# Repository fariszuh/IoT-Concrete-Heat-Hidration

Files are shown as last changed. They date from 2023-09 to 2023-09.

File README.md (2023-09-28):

# Heat Hydration

## Latar Belakang

Perilaku struktur beton pada gedung sangat dipengaruhi oleh mutunya. Salah satu faktor internal beton yang dapat menurunkan kualitas mutu beton adalah panas hidrasi (Lu et al., 2020). Panas akibat proses hidrasi sulit dilepaskan oleh
beton karena sifat konduktivitas beton yang rendah sehingga terjadi perbedaan suhu antara beton dan lingkungan yang besar seiring peningkatan suhu hidrasi
(Gowripalan, 2020). Perbedaan suhu ini mengakibatkan peristiwa konveksi yang menimbulkan tegangan tarik pada sisi luar dan tegangan tekan di bagian tengah  beton. Tegangan ini disebut dengan tegangan thermal. Tegangan thermal yang tidak mampu diterima pada umur awal beton menyebabkan retak yang terjadi bersamaan dengan susut. Retakan dan susut mengubah sifat mekanik beton sehingga terjadi penurunan mutu beton (Gowripalan, 2020).
Mutu beton yang berubah penting untuk diketahui dengan cara evaluasi yang ditinjau dengan Indeks kematangan beton. Evaluasi ini didasari oleh hasil monitoring kenaikan suhu dan perubahan susut beton sebagai efek dari panas hidrasi sejak umur awal.
Monitoring kenaikan suhu dan perubahan susut merupakan hal yang penting diperhatikan dalam mengevaluasi mutu beton. Namun, sistem akuisisi yang digunakan untuk monitoring masih menggunakan transfer data dari data logger menuju komputer atau bahkan dicatat secara manual. Akuisisi data dengan sistem ini berisiko mudah mengalami kehilangan data record karena pada kondisi monitoring realtime terdapat banyak gangguan dan kurang praktis karena data tidak dapat dipantau secara jarak jauh serta memerlukan komputer yang harus menyala ketika monitoring, yang mana monitoring dilakukan selama 24 jam.
Inovasi yang diberikan untuk permasalahan tersebut adalah perancangan sistem monitoring dengan automasi transfer data ke cloud database sebagai wadah penyimpanan dan pengolahan data. Transfer data dari penyimpanan internal dapat dilakukan secara otomatis atau dikendalikan oleh pengguna saat terdapat jaringan internet. Data input yang telah ditransfer, diolah dalam pemrograman untuk mendapatkan maturity index berupa grafik yang akan dibandingkan antara data lab dan lapangan sebagai tinjauan evaluasi kematangan beton akibat efek panas hidrasi. Selain itu, perubahan susut dapat diklasifikasikan berdasarkan waktu yang berjalan dan kondisi kenaikan suhu. Adapun, Modifikasi pada instrumen susut yang menggunakan prinsip sinyal impuls pada kaliper digital yang bekerja bersamaan dengan pengukuran suhu oleh sensor thermocouple. Implementasi ide ini diharapkan dapat menjawab masalah tersebut  yang mana proses perwujudan ide akan dijelaskan dalam laporan ini.

## Rumusan Masalah

Masalah yang dapat dirumuskan dari latar belakang di atas adalah sebagai
berikut.

1. Merancang purwarupa dan algoritma sistem untuk mengukur parameter evaluasi mutu beton (suhu dan susut) pada umur awal akibat efek panas
hidrasi berbasis wireless?
2. Bagaimana cara kerja sistem akuisisi data sehingga dapat menjadi indikator evaluasi mutu beton pada umur awal akibat efek panas hidrasi?
3. Bagaimana menciptakan visualisasi dari sistem akuisisi data parameter evaluasi mutu beton pada umur awal akibat efek panas hidrasi berbasis wireless?

## Tujuan

Tujuan yang akan dicapai dari Program Kreativitas Mahasiswa ini adalah
sebagai berikut.
1. Merancang purwarupa dan algoritma sistem untuk mengukur parameter
evaluasi mutu beton (suhu dan susut) pada umur awal akibat efek panas
hidrasi berbasis wireless.
2. Mengetahui cara kerja sistem akuisisi data sehingga dapat menjadi
indikator evaluasi mutu beton pada umut awal akibat efek panas hidrasi.
3. Menciptakan visualisasi sistem akuisisi data parameter evaluasi mutu
beton pada umur awal akibat panas hidrasi berbasis wireless.

## Manfaat Program
Manfaat dari program Kreativitas Mahasiswa ini adalah sebagai berikut.

1. Bagi Pelaksana
Tercapainya peran dan fungsi mahasiswa untuk be eran pada masyarakat  dan bidang keilmuannya.

2. Bagi Akademisi
Menunjang riset terkait inovasi beton yang mengkaji panas hidrasi sebagai properties beton.

3. Bagi Industri Konstruksi
a. Mempermudah monitoring dan evaluasi mutu beton dengan sistem yang lebih akurat dan praktis.
b. Adanya riwayat pengujian pada penyimpanan awan akan membantu dalam pencarian problem pada sistem struktural pekerjaan konstruksi.

## Hasil pengujian dan evaluasi
Hasil dan evaluasi yang diperoleh dari pengujian alat meliputi: 

### Hasil pengambilan data thermocouple tipe K tersaji dalam grafik berikut
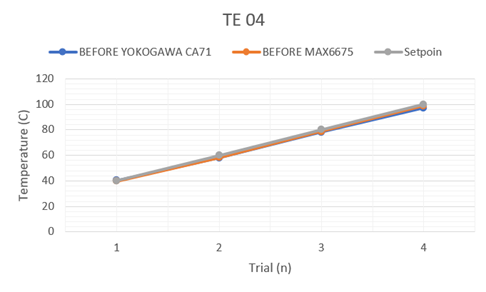
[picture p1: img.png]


Gambar 4. 6 Kalibrasi Pengukuran Suhu

Error thermocouple terukur rata-rata sebesar 0.8025°C (absolute). Hal ini menandakan bahwa standar pengukuran <5% dari range 60°C sudah te enuhi atau bernilai < 3°C. 

### Hasil pengujian Panjang susut tersaji pada grafik berikut. 

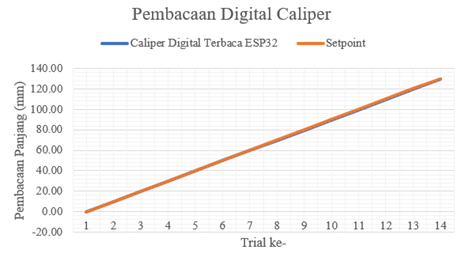
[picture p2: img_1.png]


Gambar 4. 7 Kalibrasi Pengukuran Susut

Error pengukuran digital caliper diperoleh sebesar 252.142857 µm. Nilai error ini masih jauh dari harapan, yakni sesuai standar 10 µm. ketidaksesuaian ini dimungkinkan terjadi karena kontak multiple elektrode stator (tembaga) dengan jalur slider (sin-cos plate) pada PCB terkadang bergeser vertical (normalnya hanya bergeser horizontal sepanjang tuas caliper) sehingga menyebabkan adanya gap antar plate dan timbul noise capacitance. Gap ini dimungkinkan terjadi karena pemasangan caliper dan kabel extender ke modul memakan jalur gerak tuas caliper sehingga jika dilihat dari sisi mekanikal akan sedikit menganga.

### Hasil percobaan monitoring dari sampel beton mutu 25 MPa yang dibuat memperoleh hasil sebagai berikut. 

Data hasil pengukuran suhu oleh termokopel disajikan pada gambar 4.8 dan data pengukuran susut oleh digital caliper disajikan oleh gambar 4.10. Untuk memperoleh prediksi kuat tekan beton digunakan nilai suhu yang dimasukkan kedalam persamaan Nurse-Saul dan diperoleh plot grafik perbandingan kuat tekan terhadap umur beton.

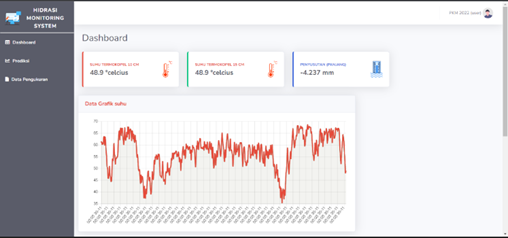
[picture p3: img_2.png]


Gambar 4. 8 Hasil Monitoring Suhu Beton

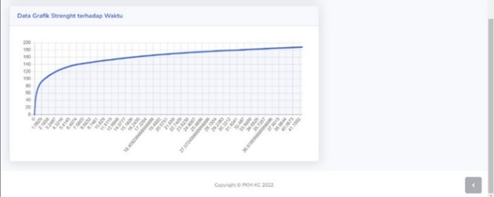
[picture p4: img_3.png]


Gambar 4. 9 Hasil Ploting Grafik Indeks Kematangan Beton

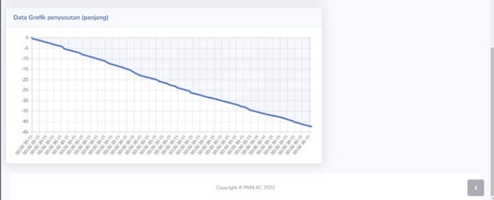
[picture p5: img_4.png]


Gambar 4. 10 Hasil Monitoring Susut Beton

## Kesimpulan
Sistem yang kami buat merupakan sistem akuisisi data berbasis wireless untuk evaluasi efek panas hidrasi beton pada umur awal. Data hasil pengukuran dan monitoring parameter panas hidrasi akan dikirim pada penyimpanan cloud. Sehingga dapat diakses secara realtime melalui website. Adapun alat yang kami buat berhasil diimplementasikan pada sampel beton mutu 25 MPa. Akan tetapi, dari hasil evaluasi diperoleh nilai eror rata-rata pembacaan suhu sebesar 0.8025˚C dan eror pembacaan susut sebesar 0,25mm dibandingkan dengan alat yang terkalibrasi.

## Saran
Saran kami dalam mewujudkan pengembangan alat ini menuju arah yang lebih baik adalah mempertimbangkan sensor dengan ketelitian yang lebih baik atau lebih mendalami cara meningkatkan kualitas pengukuran. Selain itu, perlu adanya kerja sama dengan pihak lain agar pengembangkan alat mampu diimplementasikan di lapangan dan potensi khusus dapat tercapai.

## Dokumentasi PKM (Youtube Ditmawa ITS 2022)
Dokumentasi ada pada direktori Luaran PKM (Video dan Audio). 

Link youtube:
https://www.youtube.com/watch?v=sR6Rn05YM_g&ab_channel=DirektoratKemahasiswaanITS

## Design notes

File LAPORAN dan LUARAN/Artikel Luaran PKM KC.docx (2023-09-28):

# SISTEM AKUISISI DATA BERBASIS WIRELESS UNTUK EVALUASI PANAS HIDRASI BETON PADA UMUR AWAL

Ahmad Dzikrullah Akbar, Muhammad Faris Zuhairi, Hakhi Gya Yektianto, Muhammad Alfiyan

Institut Teknologi Sepuluh Nopember

ABSTRAK

ABSTRACT

Pendahuluan

Metode

Hasil dan Pembahasan

Kesimpulan

Ucapan Terima Kasih

Daftar Pustaka

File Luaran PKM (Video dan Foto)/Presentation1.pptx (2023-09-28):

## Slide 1

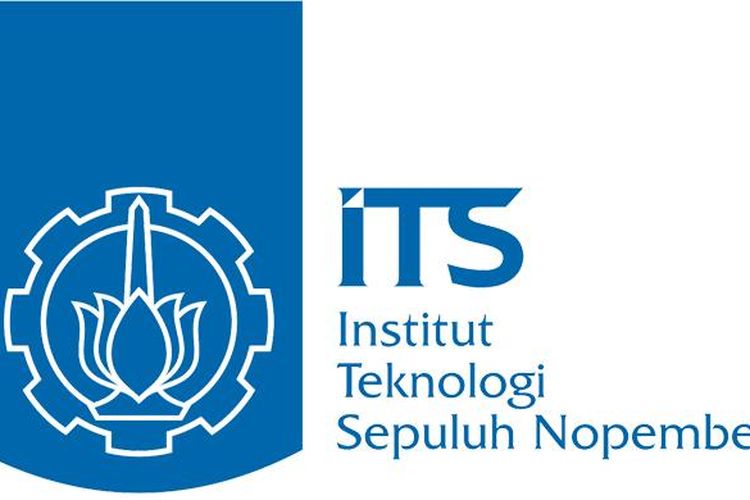
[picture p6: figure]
Lihat gambar sumber
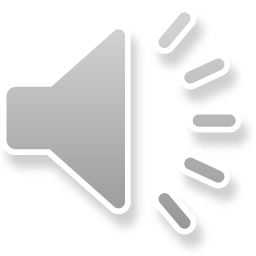
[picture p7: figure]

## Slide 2

Supported by:

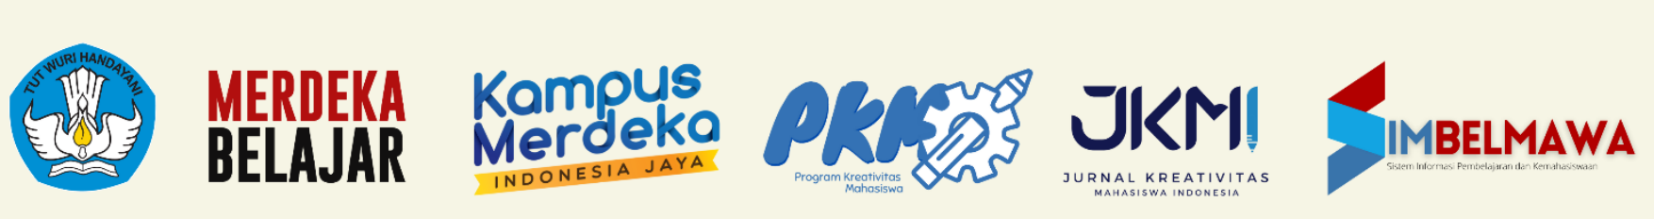
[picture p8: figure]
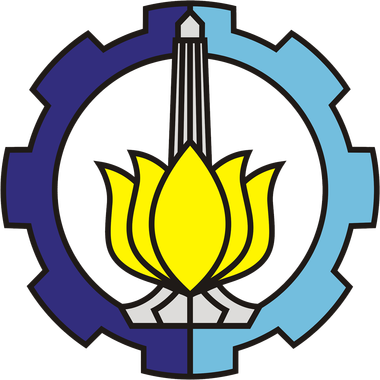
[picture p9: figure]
Institut Teknologi Sepuluh Nopember - Wikipedia bahasa Indonesia, ensiklopedia bebas

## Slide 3

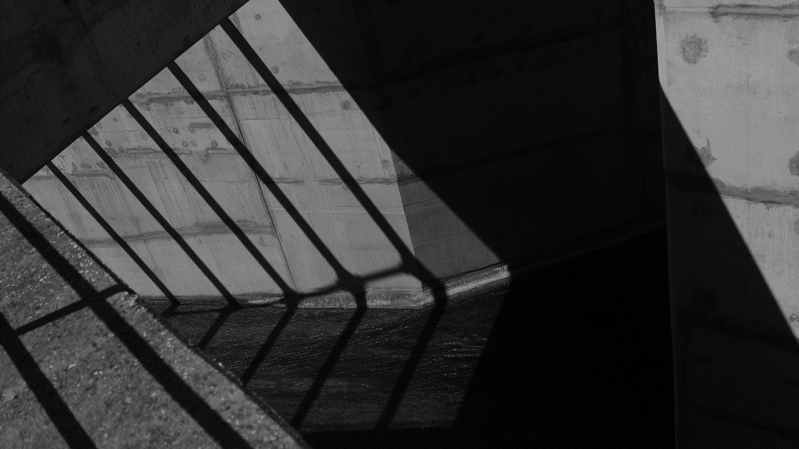
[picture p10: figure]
wing, light, black and white, architecture, structure, white, texture, roof, building, urban, wall, construction, pattern, line, space, shadow, black, monochrome, modern, material, concrete, design, stairs, symmetry, shape, monochrome photography

PROGRAM KREATIVITAS MAHASISWA KARYA CIPTA MEMPERSEMBAHKAN

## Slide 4

SISTEM AKUSISI DATA BERBASIS WIRELESS UNTUK EVALUASI EFEK PANAS HIDRASI BETON PADA UMUR AWAL

TIM 2461

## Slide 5

SISTEM AKUSISI DATA BERBASIS WIRELESS UNTUK EVALUASI EFEK PANAS HIDRASI BETON PADA UMUR AWAL

TIM 2461

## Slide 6

KEY PEOPLE

MUHAMMAD FARIS ZUHAIRI

07111940000021
Teknik Elektro

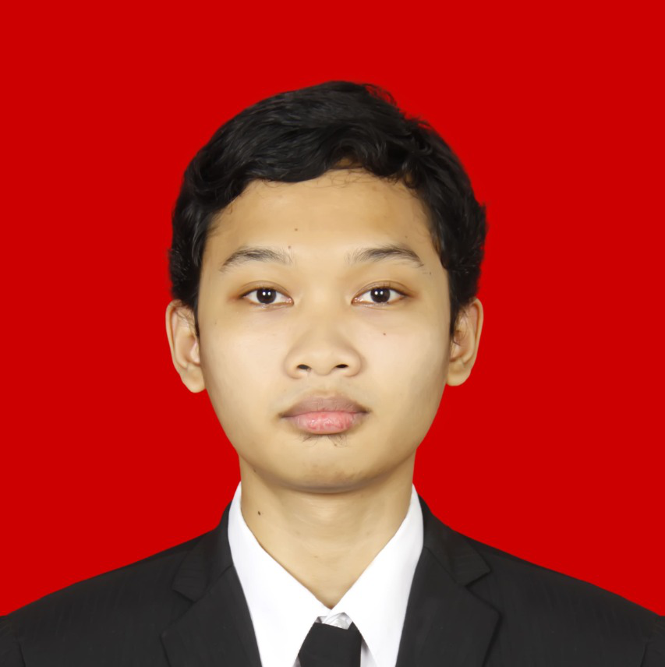
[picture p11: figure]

MUHAMMAD ALFIYAN ZULFA

5012201003
Teknik Sipil

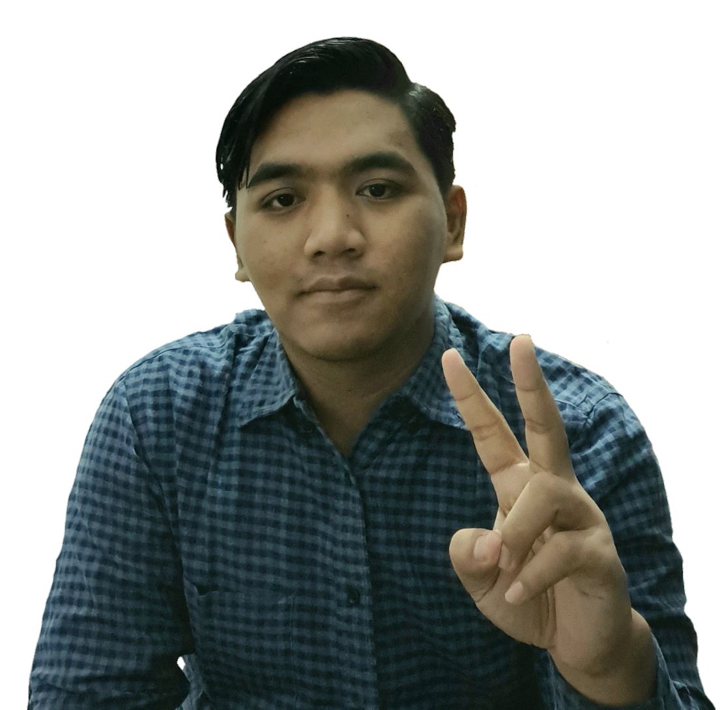
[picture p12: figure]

HAKHI GYA YEKTIANTO

07111940000022
Teknik Elektro

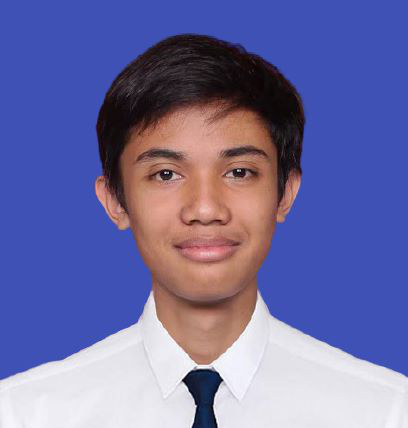
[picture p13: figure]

AHMAD DZIKRULLAH A.

03111940000005
Teknik Sipil

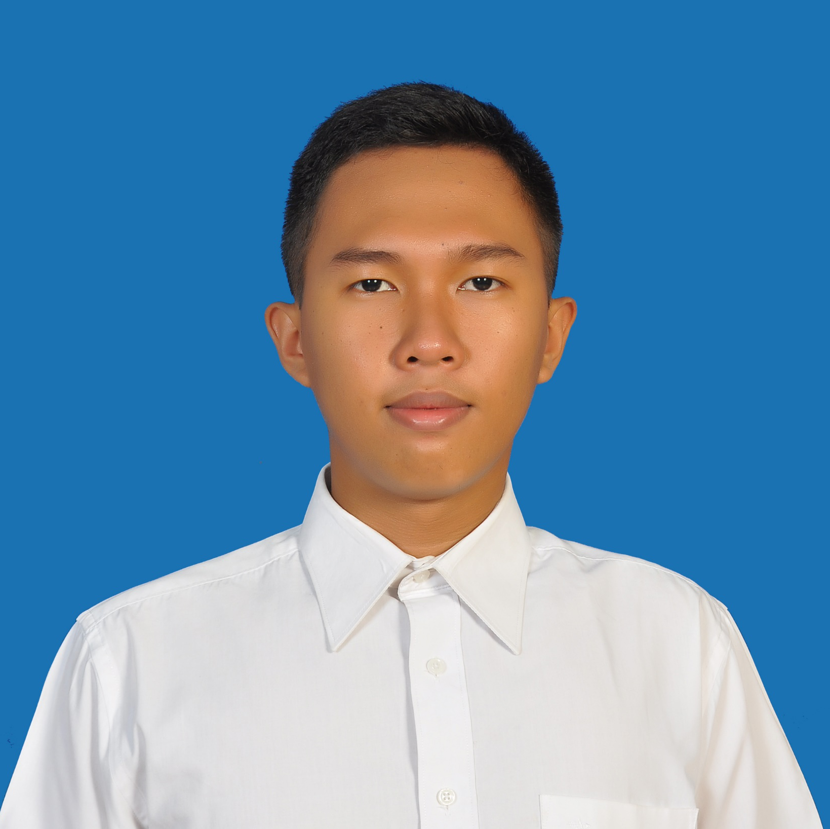
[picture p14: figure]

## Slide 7

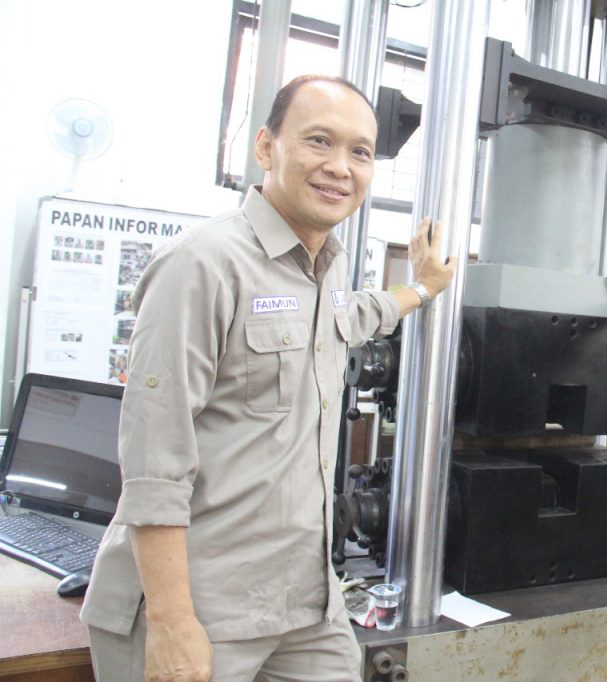
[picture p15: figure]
Lihat gambar sumber

Dosen Pembimbing

Ir. Faimun, M.sc., Ph.D.

## Grafik hasil perbandingan dengan kalibrator

| TE #1 15cm
SP | BEFORE YOKOGAWA CA71 | BEFORE MAX6675 | ERROR MUTLAK
40 | 40,5 | 42,61 | 2,11
60 | 60,2 | 62,71 | 2,51
80 | 80,4 | 82,19 | 1,79
100 | 99,7 | 101,47 | 1,77
| | AVG ERROR: | 2,045

TE #2 15cm
BEFORE YOKOGAWA CA71 | BEFORE MAX6675 | ERROR MUTLAK
41,6 | 41,38 | 0,22
59,8 | 61,49 | 1,69
80 | 82,59 | 2,59
99,4 | 101,05 | 1,65
| AVG ERROR: | 1,5375

## Grafik perbandingan dengan kalibrator

TE #3 10cm
BEFORE YOKOGAWA CA71 | BEFORE MAX6675 | ERROR MUTLAK
39,6 | 39,89 | 0,29
58,4 | 59,75 | 1,35
78,6 | 79,07 | 0,47
96,68 | 98,2 | 1,52
| AVG ERROR: | 0,9075

TE #4 10cm
BEFORE YOKOGAWA CA71 | BEFORE MAX6675 | ERROR MUTLAK
40,4 | 39,68 | 0,72
58,1 | 58,42 | 0,32
78,1 | 78,67 | 0,57
97,2 | 98,8 | 1,6
| AVG ERROR: | 0,8025

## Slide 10

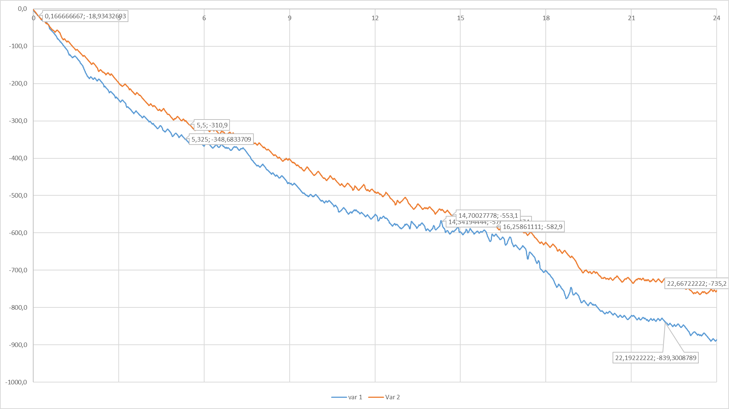
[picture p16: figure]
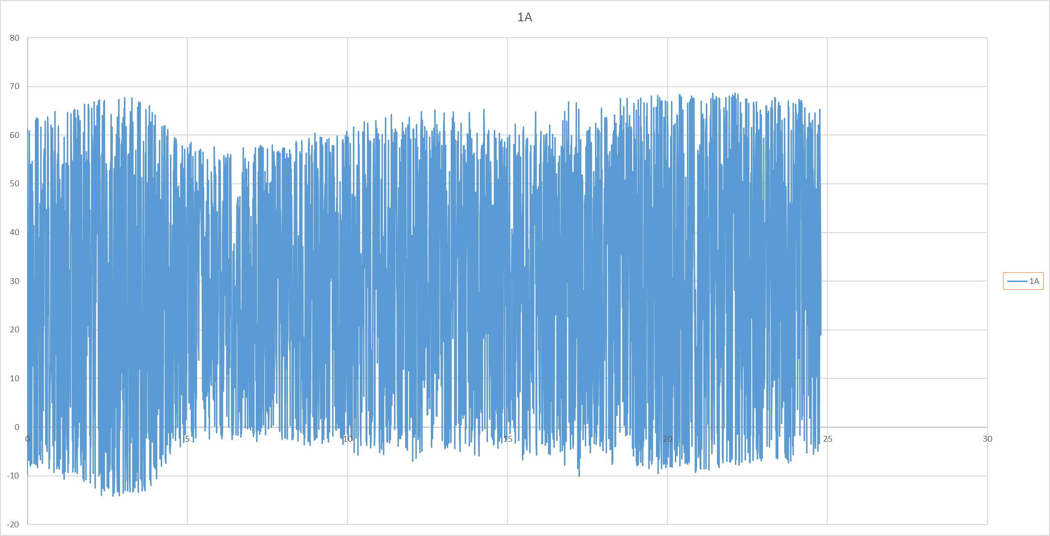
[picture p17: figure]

DATA PENUH NOISE

DATA OUTPUT SEHARUSNYA

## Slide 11

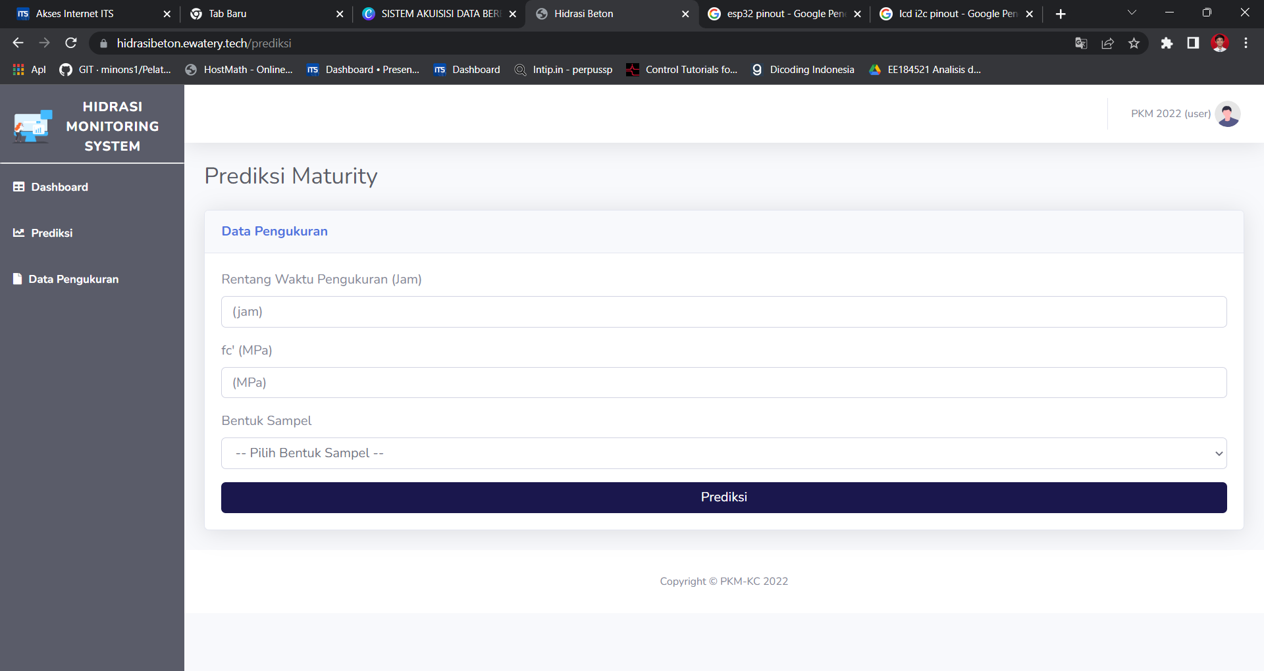
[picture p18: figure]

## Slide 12

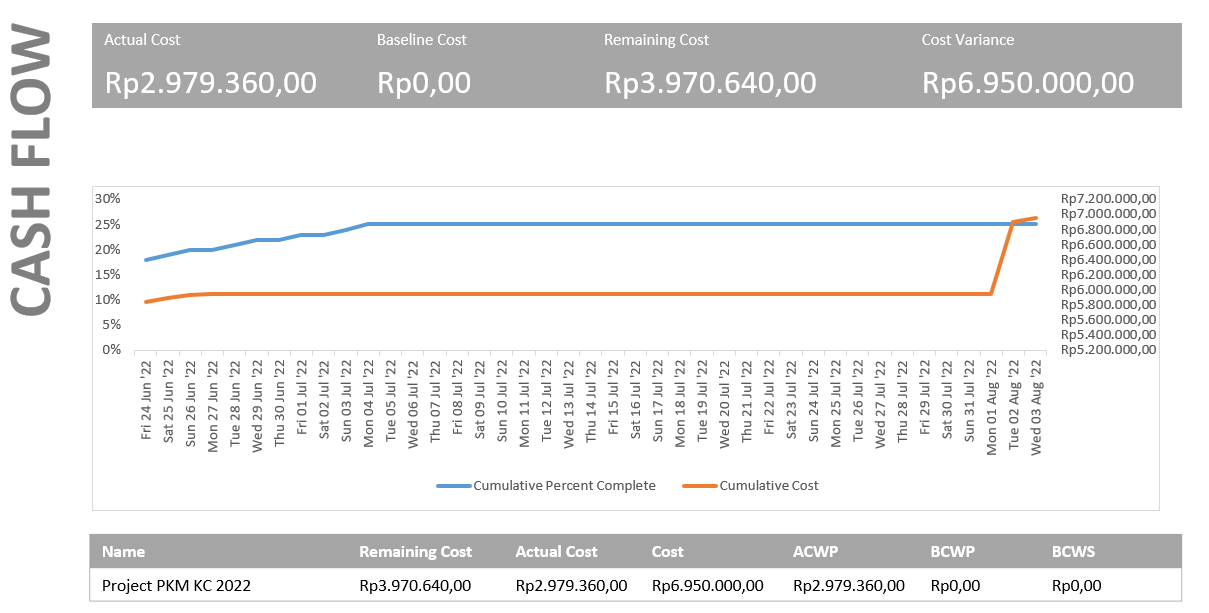
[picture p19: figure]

Berdasarkan rekapitulasi dana, dana yang masuk masih kurang 20% dari total dana yang diberikan oleh ristekdikti. Sedangkan per tanggal 3/9/2022, dana yang telah digunakan adalah sebesar Rp.2.979.360 dengan progress sekitar 80%.

## Simpulan

## Rencana Tahap Selanjutnya

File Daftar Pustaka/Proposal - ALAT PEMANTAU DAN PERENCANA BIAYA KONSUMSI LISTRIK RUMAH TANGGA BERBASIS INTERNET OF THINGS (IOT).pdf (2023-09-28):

i

i

DAFTAR ISI

ii

ii

DAFTAR TABEL
Tabel 1.1 Perbandingan Alat ini dengan KWh Meter Digital dan Power Meter.. 2
Tabel 4.1 Anggaran Biaya | 8
Tabel 4.2 Jadwal Kegiatan | 9

DAFTAR GAMBAR
Gambar 2.1 Sensor Tegangan ZMPT101B | 4
Gambar 2.2 Sensor Arus ACS712 | 4
Gambar 2.3 Modul Relay | 5
Gambar 2.4 STM 32 | 5
Gambar 3.1 Diagram Alir Pelaksanaan | 6
Gambar 3.2 Desain Aplikasi | 7
Gambar 5.1 Halaman Depan Aplikasi | 19
Gambar 5.2 Fitur Pengaturan | 19
Gambar 5.3 Fitur History Pemakaian | 20
Gambar 5.4 Fitur Peringatan | 20
Gambar 5.5 Fitur Informasi | 21
Gambar 5.6 Posisi Peletakan Sensor Tegangan, Sensor Arus dan Relay | 21
Gambar 5.7 Peletakan Hardware | 22
Gambar 5.8 Skema Kerja Alat | 22

BAB 1. PENDAHULUAN

### 1.1 Latar Belakang

Kenaikan pendapatan yang tidak sebanding dengan kebutuhan merupakan salah satu masalah ekonomi yang dirasakan oleh sebagian masyarakat Indonesia. Selain itu kenaikan biaya bahan bakar, pendidikan dan sembako juga menambah beban pengeluaran masyarakat. Adanya kebijakan yang akan diberlakukan pada tahun 2020 untuk mengurangi subsidi dan menaikkan tarif dasar listrik untuk golongan daya 900 VA yang penggunanya didominasi oleh masyarakat kelas menengah ke bawah menyebabkan pengeluaran masyarakat pada golongan tersebut terus bertambah. Di sisi lain, masyarakat golongan menengah ke bawah yang sebagian besar bekerja sebagai petani, pedangang dan juga buruh yang mempunyai pendapatan yang cenderung tetap harus terkena dampak masalah perekonomian nasional.
Salah satu belanja pokok masyarakat tiap bulan adalah biaya listrik yang dapat dihitung dengan cara besaran daya yang dipakai dikalikan tarif listrik lalu dikalikan waktu pemakaian. Jika semakin kecil daya dari peralatan-peralatan elektronik yang digunakan, semakin rendah tarif listrik yang dibayar.Pemakaian listrik semakin sulit untuk dikontrol dan dibatasi agar sesuai dengan anggaran keuangan rumah tangga yang tersedia seiring perkembangan teknologi. Akibat dari pemakaian yang tidak dibatasi, seringkali biaya listrik membengkak. Akibat kondisi ini, seharusnya masyarakat sadar akan pemakaian listrik agar tidak berlebih hanya karena mudahnya mengakses listrik. Dengan anggaran listrik rumah tangga yang terkontrol, sisa anggaran dapat dialokasikan untuk jenis pengeluaran yang lain dan juga tidak mengganggu anggaran belanja rumah tangga yang telah direncanakan.
Saat ini kebanyakan rumah tangga di Indonesia menggunakan kWh meter digital yang dipakai untuk listrik prabayar. Alat tersebut hanya menampilkan daya listrik tersisa yang akan digunakan. Selain itu ada alat yang bernama Power Meter, yaitu alat yang mampu memonitor dan mengetahui besar daya listrik yang digunakan di dalam rumah. Kedua alat tersebut dapat memantau pemakaian daya listrik, namun tidak mampu melakukan pengawasan terhadap penggunaannya dari sisi biaya. Dari alat berbasis aplikasi ada juga yang dapat mengontrol penggunaan listrik perangkat elektronik yang terhubung dengan jaringan nirkabel namun tidak berbasis biaya listrik. Sehingga, solusi tersebut belum mampu mengatasi permasalahan anggaran pengeluaran kebutuhan listrik rumah tangga masyarakat Indonesia.
Oleh karena itu, dibutuhkan solusi berupa alat pengatur penggunaan listrik berdasarkan anggaran belanja rumah tangga yang dapat memonitor dan membantu konsumen untuk membatasi penggunaan listrik dengan menggunakan sistem wireless melalui smartphone dan aplikasi berbasis IoT (Internet of Things). Alat yang terdiri dari software dan hardware terintegrasi ini dilengkapi dengan algoritma yang menghitung penggunaan daya listrik berbasis tarif Rupiah untuk kemudian disampaikan kepada pengguna dalam bentuk alarm atau notifikasi penggunaan sebagai pengingat apabila penggunaan listrik hampir mendekati batas. Pada alat ini juga terdapat relay system yang terhubung dengan perangkat elektronik agar dapat mematikan peralatan listrik yang tidak terlalu dibutuhkan apabila pengunaan listrik di suatu rumah melebihi tarif yang ditentukan oleh budget planner secara otomatis dan real time. Alat ini dapat melakukan setting untuk berapa besar daya yang mau dikeluarkan bergantung biaya penggunaan listrik yang ingin dimasukkan dalam aplikasi. Selain itu, pada alat ini dilengkapi memory yang dapat menyimpan data penggunaan listrik bulan sebelumnya yang bisa digunakan untuk evaluasi pemakaian listrik. Dengan adanya alat ini, tentunya mampu menjawab permasalahan masyarakat rumah tangga dala menghemat listrik sehingga anggaran rumah tangga dapat dialokasikan ke kebutuhan yang lain. Tabel 1.1 Perbandingan Elcomic dengan KWh Meter Digital dan Power Meter
| KWh Meter Digital | Power Meter | Alat kami
Mengukur Daya Listrik | ✓ | ✓ | ✓
Mengukur Daya Listrik per Peralatan | - | ✓ | ✓
Mengukur Biaya Listrik yang Telah Digunakan | - | - | ✓
Pengingat Penggunaan Biaya Listrik | - | - | ✓
Rencana Anggaran Penggunaan Biaya Listrik | - | - | ✓
Pemutus Arus Listrik | ✓ | - | ✓

### 1.2 Rumusan Masalah

Permasalahan | yang | akan | diselesaikan | dari | Program | Kreativitas
Mahasasiswa ini adalah sebagai berikut:
1. Bagaimana membuat rancangan pemrograman software alat ini?
2. Bagaimana membuat rancangan hardware alat ini?
3. Bagaimana mengintegrasikan software dan hardware ke dalam satu sistem?
4. Bagaimana penerapan alat ini pada masyarakat?

### 1.3 Tujuan

Tujuan yang akan dicapai dengan Program Kreativitas Mahasiswa ini adalah sebagai berikut:

1. Mendapatkan software yang dapat memantau dan merencanakan penggunaan listrik sesuai dengan rencana anggaran yang diinginkan konsumen.
2. Mendapatkan hardware yang dapat membatasi penggunaan peralatan listrik yang telah terhubung sesuai dengan rencana anggaran yang telah dialokasikan
3. Mendapatkan suatu sistem software dan hardware terintegrasi menjadi alat yang dapat memantau merencanakan konsumsi listrik berbasis anggaran belanja rumah tangga.
4. Mengetahui hasil penerapan alat ini pada masyarakat rumah tangga.

### 1.4 Luaran yang Diharapkan

Luaran yang diharapkan dari Program Kreativitas Mahasiswa ini adalah sebagai berikut:
1. Terciptanya prototype alat dengan software dan hardware terintegrasi sebagai pemantau dan perencana penggunaan listrik berbasis anggaran belanja rumah tangga.
2. Artikel ilmiah tentang penerapan alat ini.
3. Catatan harian, laporan kemajuan, dan laporan akhir dari kegiatan PKM ini.

### 1.5 Manfaat

Manfaat dari Program Kreativitas Mandiri ini sebagai berikut:
1. Bagi Rumah Tangga
Program ini dapat membantu masyarakat rumah tangga dalam merencanakan dan mengontrol penggunaan listrik sesuai dengan anggaran belanja sehingga dapat menghemat pengeluaran.
2. Bagi Mahasiswa
Program ini dapat mengembangkan kreativitas mahasiswa dalam bidang teknologi yang lebih efektif dan efisien sesuai dengan permasalahan yang ada dalam masyarakat.
BAB 2. TINJAUAN PUSTAKA

### 2.1 Internet of Things (IoT)

Internet of Things, atau dikenal juga dengan singkatan IoT, merupakan sebuah konsep yang bertujuan untuk memperluas manfaat dari konektivitas internet yang tersambung secara terus-menerus dengan mentrabsfer data melalui jaringan tanpa memerlukan interaksi menusia ke manusia atau manusia ke computer. Semua sudah dijalankan secara otomatis dengan program. Pada dasarnya, Internet of Things mengacu pada benda yang dapat diidentifikasikan secara unik sebagai representasi virtual dalam struktur berbasis Internet dengan tujuan untuk mempermudah berbagai macam aktivitas yang dilakukan oleh manusia. IoT telah berkembang dari konvergensi teknologi nirkabel, micro-electromechanical systems (MEMS), dan Internet. (IdCloudHost, 2016). Pada rancangan alat kami, alat menggunakan IoT dimana akan mengirimkan data hasil daya dari peralatan kepada otak utama, STM 32 lalu akan dikirim melalui jaringan ke aplikasi penghitung daya pada smartphone pengguna.

### 2.2 Sensor Tegangan ZMPT101B

AC Voltage Sensor ZMPT101B adalah sensor berukuran kecil, memiliki akurasi tinggi, dan konsistensi yang baik untuk mengukur tegangan dan daya hingga kisaran 250VAC(Abubakar et al., 2017). Aplikasi lain dari alat ini diantaranya untuk mendeteksi gangguan pada ground, dan pembacaan arus berlebih. Pada sensor ZMPT101B terdapat trafo step-down yang dianalogikan pada rangkaian op-amp sebagai pembanding dan kemudian akan menghasilkan output sinyal analog. Pada rancangan kami, sensor ini akan bekerja sebagai pembaca tegangan pada titik percabangan dan beban.

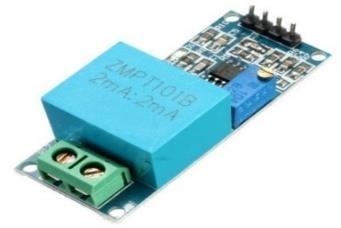
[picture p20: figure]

Gambar 2.1 Sensor Tegangan ZMPT101B ( Sumber : hallroad.com.pk )

### 2.3 Sensor Arus ACS712

Sensor Arus ACS712 adalah sensor yang berfungsi mendeteksi aliran arus listrik baik AC maupun DC yang melewatinya berdasarkan efek medan elektromagnetik. Sensor ini memiliki pembacaan arus listrik dengan ketepatan yang tinggi karena terdapat rangkaian low offset linear hall dengan satu lintasan yang terbuat dari tembaga sebagai rangkaian penguat operasional. Sensor ini tidak memerlukan isolasi sebagai pelindung sehingga tidak memerlukan biaya dan ruang yang besar. ACS712 juga memiliki hambatan yang kecil sehingga nilai arus yang dialirkan ke perangkat listrik tetap optimal (Allegro MicroSystems, 2017). Pada rancangan alat kami, ACS712 berfungsi sebagai pendeteksi aliran arus listrik yang mengalir.

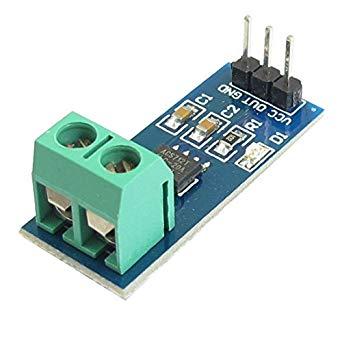
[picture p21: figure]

Gambar 2.2 Sensor Arus ACS712 ( Sumber : amazon.com )

### 2.4 Modul Relay

Relay adalah saklar (switch) yang dioperasikan secara listrik dan merupakan komponen elektronik dengan terdiri dari empat bagian penting yakni coil, armature, switch contact point, dan spring yang bekerja berdasarkan medan elektromagnetik (Teknikelektronika, 2019). Relay menggunakan prinsip elektromagnetik untuk menggerakkan kontak saklar sehingga dengan arus listrik yang kecil dapat menghantarkan listrik yang bertegangan tinggi. Modul relay berfungsi sebagai saklar elektrik dalam peralatan elektronik sehari-hari seperti motor listrik, remote control, dan peralatan elektronik lainnya.

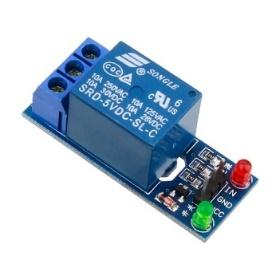
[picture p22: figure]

Gambar 2.3 Modul Relay
( Sumber : addicore.com )

### 2.5 STM 32

STM32 adalah mikrokontroler dengan inti prosesor 32 bit RISC ARM Cortex-M7, Cortex-M4F, Cortex-M3, Cortex-M0+, dan Cortex-M0 dari STMicrelectronics. Mikrokontroler ini mempunyai frekuensi waktu yang tinggi, umumnya berada pada kisaran 72MHz atau lebih. Mikrokontroler di dalamnya adalah STM32F103C8T6 dari STMicroelectronics. Selain Mikrokontroler, board ini juga menggunakan dua osilator kristal, satu adalah kristal 8MHz, dan yang lain adalah kristal 32 KHz, yang dapat digunakan untuk menggerakkan RTC internal (Real Time Clock) (Embeddenesia.com, 2019). Pada rancangan alat kami, STM 32 ini berfungsi sebagai otak utama kendali pendata pemakaian daya listrik yang akan ditransferkan datanya kepada aplikasi pengguna.

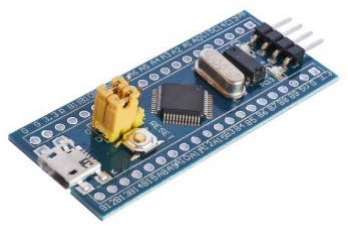
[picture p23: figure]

Gambar 2.4 STM 32
( Sumber : Elektrologi.iptek.web.id )

### 2.6 Micro SD card

Micro SD card merupakan komponen eksternal untuk STM 32 yang berfungsi menyimpan data, baik itu data Operating System ataupun untuk media penyimpanan data jangka panjang. Micro SD card dimasukkan pada port modul untuk dibaca. Penyimpanan dapat diperluas melalui banyak jenis peripheral yang terhubung USB. Dalam pembacaan data yang masuk ke micro SD card diperlukan pembacaan melalui OS yang ditanamkan pada SD card. Pada rancangan alat kami, micro SD card digunakan untuk menyimpan data penggunaan listrik yang dihasilkan peralatan.

BAB 3 Tahapan Pelaksanaan
Kegiatan program kreativitas mahasiswan ini dilakukan dengan diagram pelaksanaan sebagai berikut :

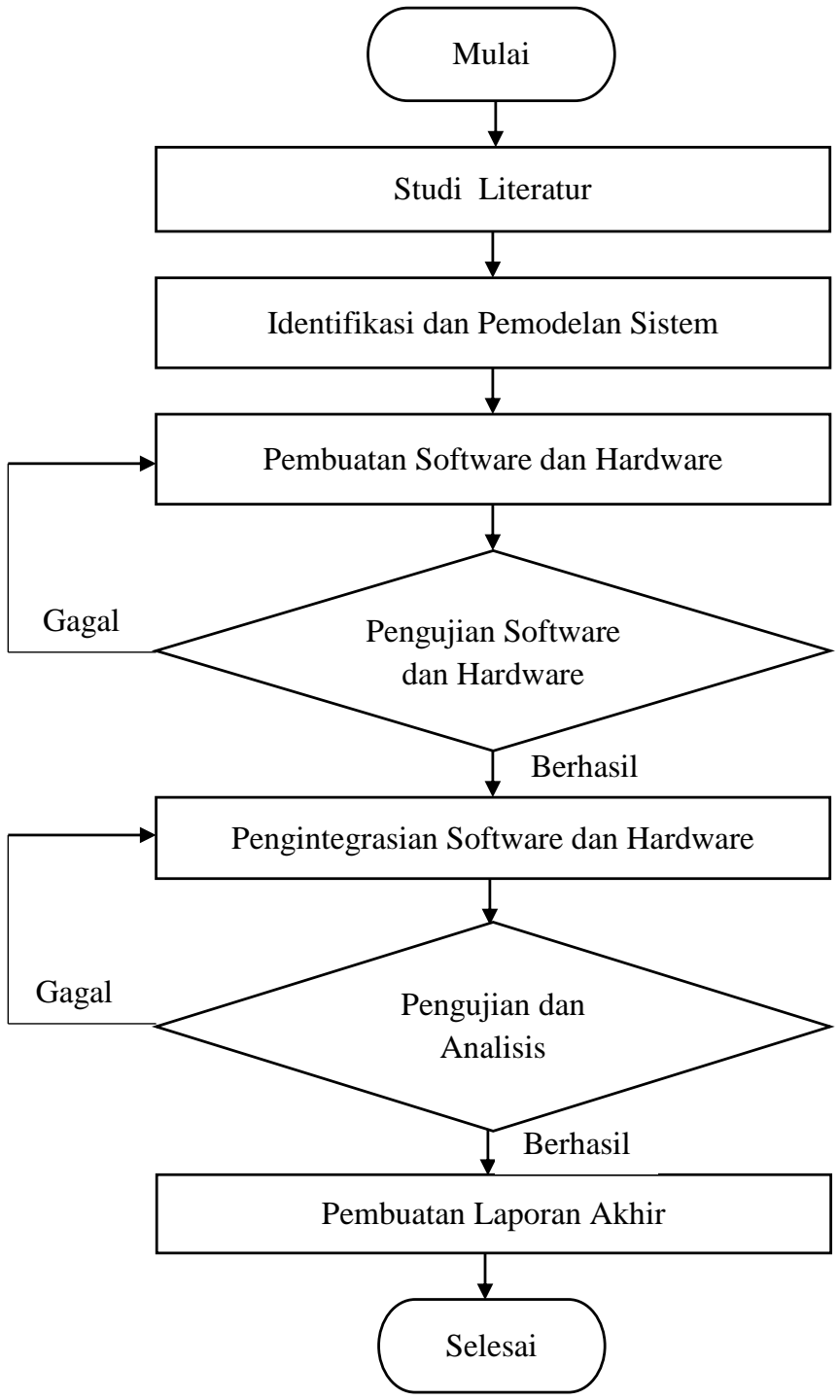
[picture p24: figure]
Pembuatan Laporan Akhir; Selesai; Berhasil; Gagal; Pengintegrasian Software dan Hardware; Identifikasi dan Pemodelan Sistem; Studi Literatur; Mulai; Pembuatan Software dan Hardware; Pengujian Software dan Hardware; Pengujian dan Analisis

Gambar 3.1 Diagram Alir Pelaksanaan

### 3.1 Studi Literatur

Kegiatan studi literatur dilakukan dengan mencari dasar teori yang tepat dalam perancangan alat seperti algoritma program yang tepat untuk perencanaan dan pengontrol konsumsi biaya listrik, penampil data real time pada clientyang fungsional dan user friendly, karakteristik relay, cara kerja power supply, sensor arus dan tegangan, metode penempatan kedua sensor dan relay, rangkaian instrumentasi ,serta pemrosesan dan penyimpanan data konsumsi listrik pada server dengan STM32 dan memory.

### 3.2 Identifikasi dan Permodelan Sistem

Identifikasi sistem bertujuan untuk mengidentifikasi prosedur perencanaan dan permodelan sistem yang tepat sehingga dapat menghasilkan algoritma software, pemodelan alat, komunikasi dengan server, sistem alokasi biaya pemakaian listrik, sistem penyimpanan data pada server, proses pemutusan energi listrik pada server, dan interface pada server-client yang tepat. Dengan algortima pemrograman yang tepat, maka sistem dapat memantau dan merencanakan konsumsi biaya listrik dengan baik seperti yang diinginkan oleh pengguna. Metode penyimpanan data pada server yang tepat dibutuhkan untuk efisiensi suplai daya yang digunakan agar proses monitoring dapat dilakukan secara kontinu dalam jangka waktu yang panjang dan menjamin akurasi data agar perhitungan dan pembatasan konsumsi biaya listrik dapat dilakukan dengan tepat. Sedangkan penampil data real time pada aplikasi server-client wajib memiliki interface yang mudah dipahami oleh pengguna aplikasi dan memuat fitur-fitur terpenting dalam aplikasi seperti pemutus hubungan listrik, tata tertib pemakaian yang benar dan perencana anggaran.
Dalam perencanaan alat pemantau dan perencana kelistrikan rumah ini terdapat lima sistem.
a. Sistem pengambilan data alokasi anggaran listrik yang direncanakan oleh pengguna melalui aplikasi yang bernama Elcomic.
b. Sistem pengambilan data anggaran listrik yang berasal dari sensor yang sudah terpasang pada peralatan yang ingin dikontrol pengguna.
c. Sistem penyimpanan data pada server dengan microkontroller STM 32 yang dilengkapi dengan micro SD card.
d. Sistem operasi pemutusan aliran listrik pada peralatan yang telah ditentukan apabila pemakaian listrik melewati batas yang sudah diatur menggunakan relay.
e. Sistem penampil data pada aplikasi perangkat user.

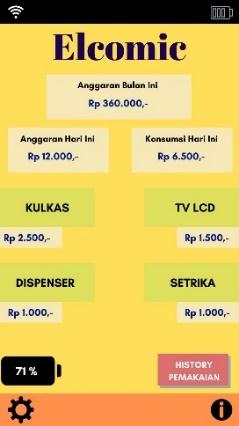
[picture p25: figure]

Gambar 3.2 Desain Aplikasi Elcomic

### 3.3 Pembuatan Prototype

Pembuatan prototype adalah bentuk realisasi dari desain dan model sistem yang telah direncanakan sebelumnya. Rangkaian Elcomic terdiri dari rangkaian peralatan listrik yang digunakan untuk mengolah data pemakaian listrik dan kemudian mengirim data tersebut ke server serta menampilkan pada user. Server untuk rangkaian ini menggunakan mini komputer STM32. Kemudian user dengan perangkat Android mengakses cloud dan mampu menampilkan hasil monitoring pemakaian listrik sesuai dengan anggaran yang ditentukan dan smart alert and relay system akan bekerja apabila pemakaian listrik mendekati batas bawah yang anggaran tersebut. Apabila tidak ada respon dari user dan pemakaian listrik telah melewati batas, maka relay akan otomatis mematikan peralatan yang terhubung.

### 3.4 Pengujian dan Analisis

Pengujian alat ini bertujuan untuk mengetahui dampak dan hasil kinerja dari Elcomic secara langsung yang akan diterapkan pada pemakaian listrik rumah tangga. Pada tahap ini akan menguji data berupa anggaran konsumsi listrik yang tersimpan pada server, penggunaan daya listrik pada tiap tiap alat elektronik dan menyeluruh secara langsung (real time) yang ditampilkan pada user melalui aplikasi, biaya pemakaian listrik dalam rupiah secara langsung (real time), serta kinerja hardware yang terhubung dengan alat elektronik dalam listrik rumah tangga. Keseluruhan pengujian juga ditujukan untuk analisis ketahanan rancangan alat agar dapat dipakai dalam jangka waktu yang lama dan analisis pemakaian
daya | listrik | dalam | bulan-bulan | sebelumnya | agar | pengguna | dapat
mengevaluasinya. Kemudian, dari hasil keseluruhan sistem dapat ditentukan tingkat efisiensi, efektivitas, dan akurasi data dari biaya penggunaan yang dikeluarkan oleh sistem dibandingkan dengan biaya penggunaan yang dikeluarkan oleh PLN melalui meteran listrik konvensional.

### 3.5 Pembuatan Laporan

Pembuatan laporan dilakukan setelah seluruh tahapan yang direncanakan terselesaikan. Laporan dapat menyampaikan keseluruhan proses, menjelaskan kinerja dari alat Elcomic, dan hasil dari penelitian rancangan alat Elcomic dengan mengacu pada data yang didapatkan.
BAB 4. BIAYA DAN JADWAL KEGIATAN

### 4.1 Anggaran Biaya

Adapun anggaran biaya untuk program ini sebagai berikut : Tabel 4.1 Anggaran Biaya

No | Jenis Pengeluaran | Biaya
1 | Peralatan penunjang | Rp 2.010.000,00
2 | Bahan habis pakai | Rp 6.272.500,00
3 | Perjalanan | Rp 246.250,00
4 | Lain-lain | Rp 3.877.500,00

Jumlah | Rp 12.406.250,00

### 4.2 Jadwal Kegiatan

| Adapun jadwal kegiatan untuk program ini sebagai berikut :
Tabel 4.2 Jadwal Kegiatan Pelaksanaan Program
No | Kegiatan | Bulan
1 | 2 | 3 | 4 | 5
1 | 2 | 3 | 4 | 1 | 2 | 3 | 4 | 1 | 2 | 3 | 4 | 1 | 2 | 3 | 4 | 1 | 2 | 3 | 4
1 | Studi Literatur
2 | Identifikasi dan Permodelan Sistem
3 | Pembuatan Prototipe
5 | Pengujian dan Analisis
6 | Pembuatan Laporan

DAFTAR PUSTAKA
Abubakar, dkk. 2017. Calibration of ZMPT101B Voltage Sensor ModSule using Polynomial Regression for Accurate Load Monitoring. APRN Journal of Engineering and Applied Sciences. Volume 12, No. 4.
Allegro | MicroSystem. | 2017. | ACS712-Datashhet. | URL | :
http://www.allegromicro.com/~/media/Files/Datasheets/ACS712-Datasheet.ashx. Diakses pada 29 October 2019.

Ali Akmal, Ketut Abimanyu. 2017. Studi Pengaturan Relay Arus Lebih dan Relay Hubung Tanah Penyulang Timor 4 pada Gardu Induk. Jurnal infotronik. Volume 2, No. 1.

CNBC Indonesia. 2019. Subsidi Listrik 900 VA Dicabut Apakah Tepat Sasaran . URL : https://www.cnbcindonesia.com/news/20190905180518-4-97463/subsidi-listrik-900-va-dicabut-apakah-tepat-sasaran. (https://www.cnbcindonesia.com/news/20190905180518-4-97463/subsidi-listrik-900-va-dicabut-apakah-tepat-sasaran) Diakses pada 30 Oktober 2019.

Embeddenesia.com. 2019. Seri Tutorial Pemograman Mikrokontroler. URL : https://embeddednesia.com/v1/seri-tutorial-stm-32/. Diakses pada 30 Oktober 2019

IdCloudHost. 2016. Mari Mengenal Apa itu Internet of Thing (IoT). URL: https://idcloudhost.com/mari-mengenal-apa-itu-internet-thing-iot/ . Diakses pada 30 Oktober 2019

Mehta, Manan. 2015. Esp 8266: A Breakthrough In Wireless Sensor Networks And Internet Of Things. International Journal of Electronics and Communication Engineering & Technology. 6(8): 07-11.

Moneysmart. 2019. Daftar Tarif Listrik Terbaru 2019 Resmi Dari Kemeterian ESDM. URL: https://www.moneysmart.id/daftar-tarif-listrik-terbaru/. Diakses pada 30 Oktober 2019.

Saleh, Muhamad dan Haryanti, Munnik. 2017. Rancang Bangun Sistem Keamanan Rumah Menggunakan Relay. Jurnal Teknologi Elektro Universitas Mercu Buana. Vol. 8, No. 2.

Saludin Muis. 2014. Perancangan Power Supply Switch Mode. Edisi ke-1. Graha Ilmu, Jogjakarta.

Setiawan, R., Rivai, M., & Suwito. (2017). Implementasi Analog Front End Pada Sensor Kapasitif Untuk Pengaturan Kelembaban Menggunakan Mikrokontroller STM32. Jurnal Teknik ITS. Vol. 6, No. 1.

Teknikelektronika. 2019. Pengertian Relay dan Fungsinya., https://teknikelektronika.com/pengertian-relay-fungsi-relay/. Diakses pada 29 Oktober 2019

T Microelectronics. 2014. STM32F4 Discovery Datasheet : Discovery kit for STM32F407/417 line.

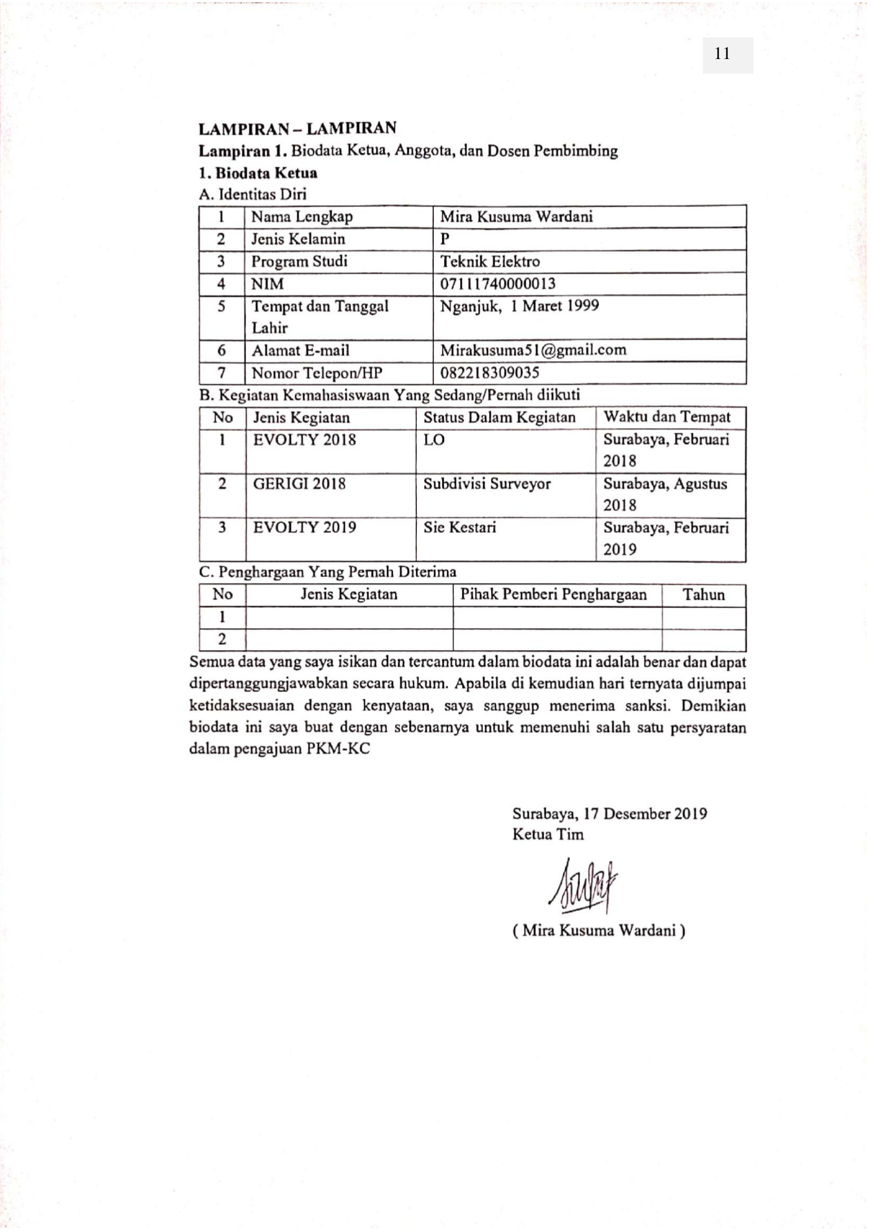
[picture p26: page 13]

hhhhh

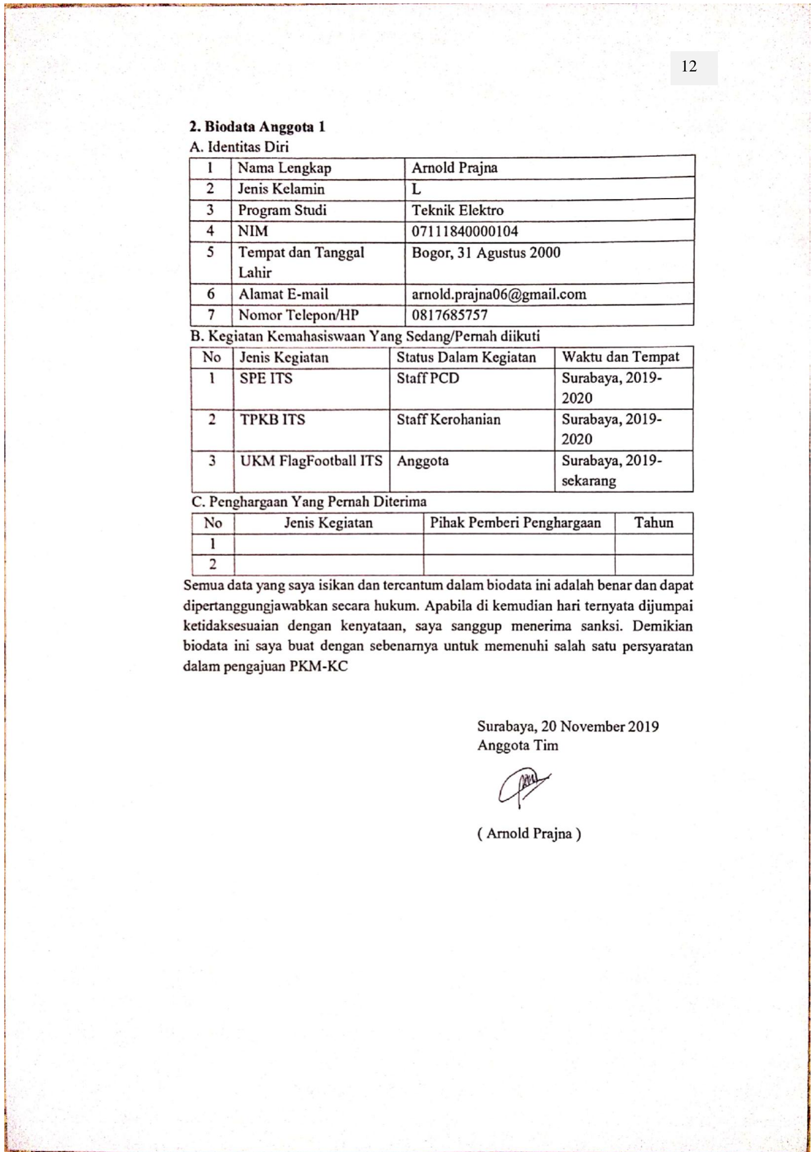
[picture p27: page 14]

hale

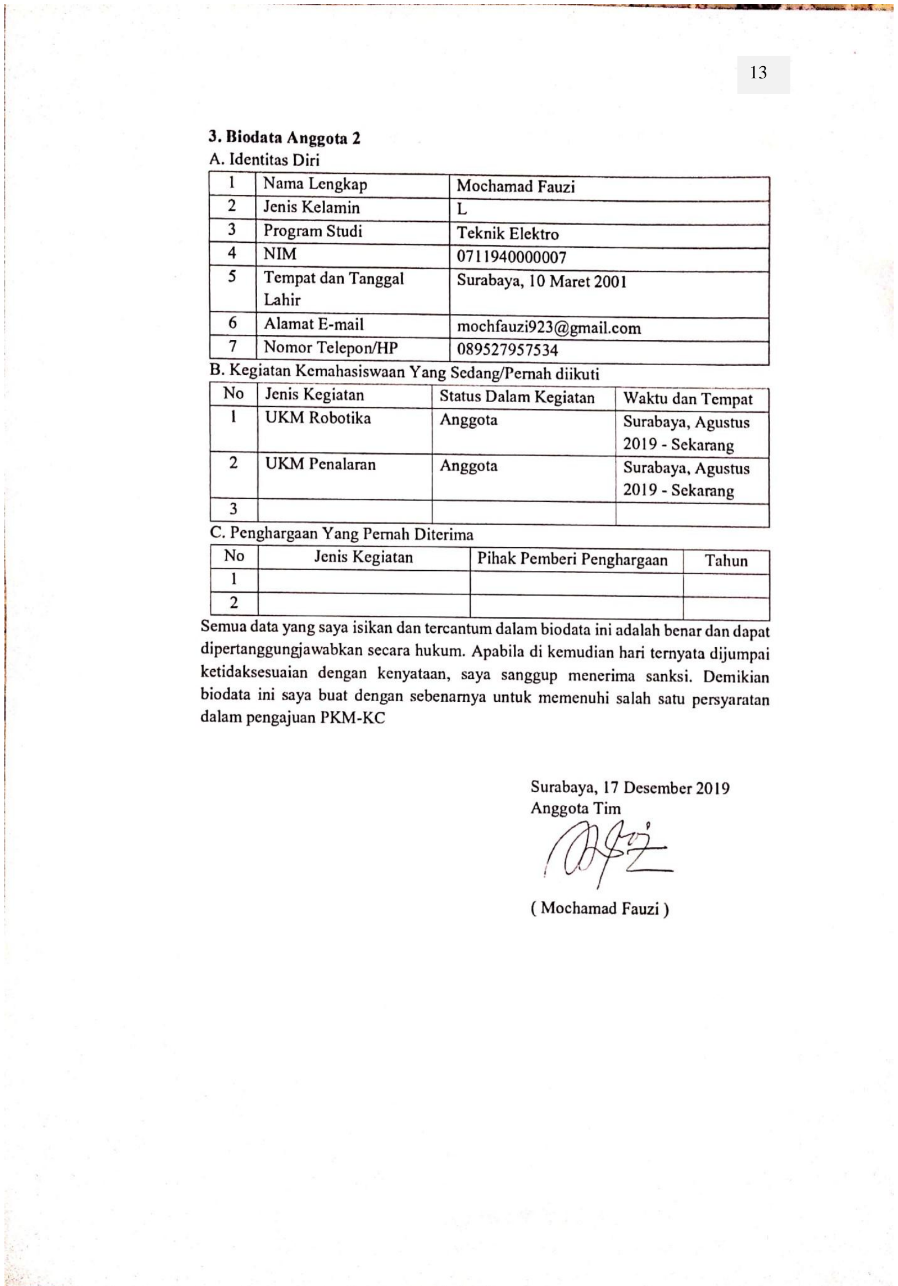
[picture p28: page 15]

bii

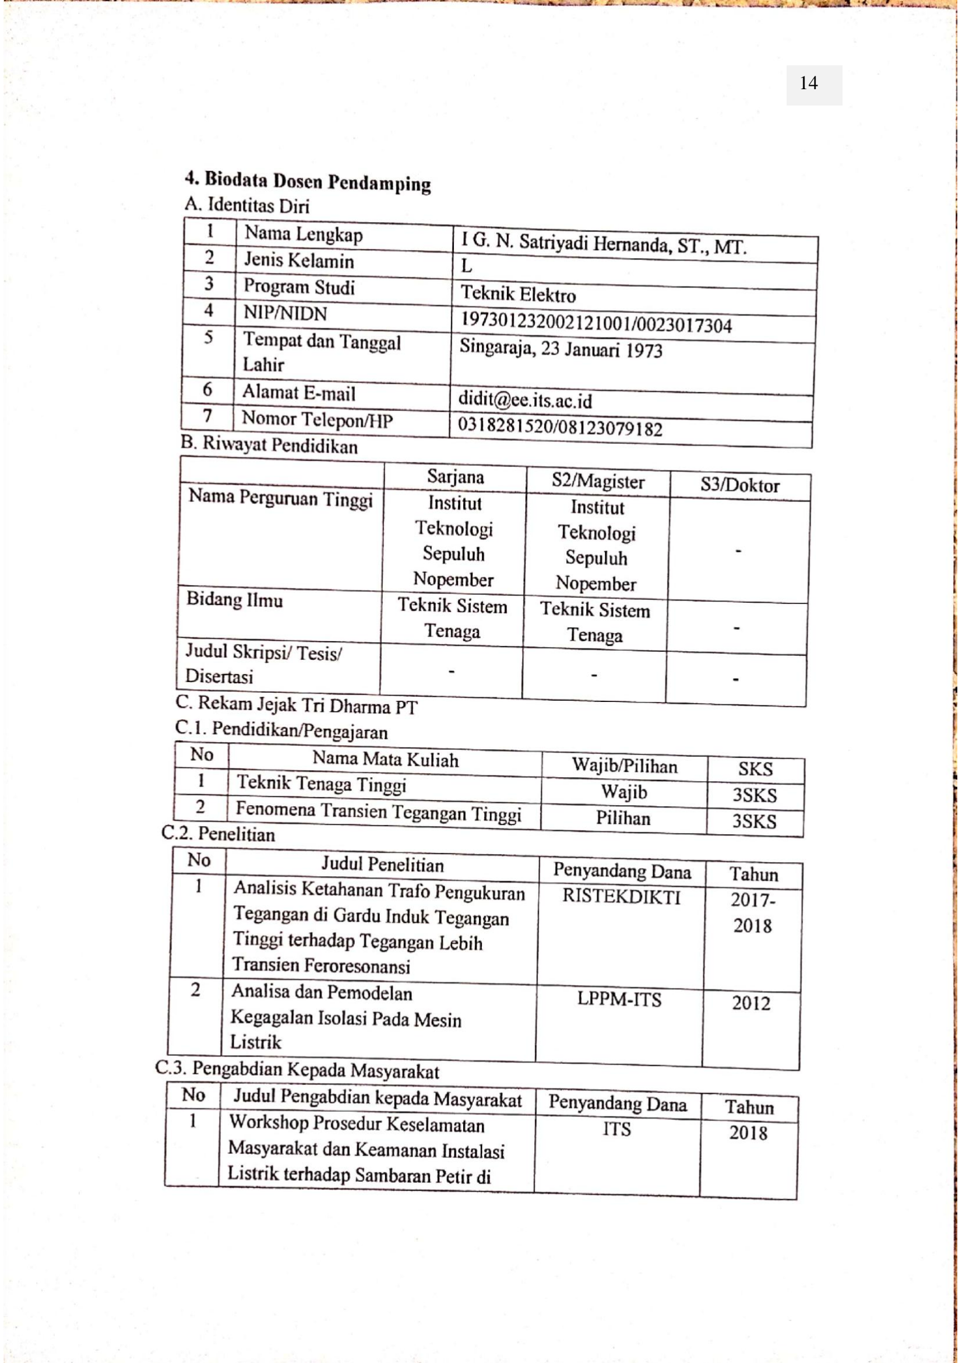
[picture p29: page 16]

Lampiran 2. Justifikasi Anggaran Kegiatan
1. Jenis Perlengkapan | Volume | Harga Satuan (Rp) | Nilai (Rp)
- Solder + Holder | 1 Paket | Rp135.500,00 | Rp135.000,00
- Timah | 2 Buah | Rp17.500,00 | Rp35.000,00
- Bor PCB | 1 Buah | Rp88.000,00 | Rp88.000,00
- Penyedot Timah | 1 Buah | Rp27.000,00 | Rp27.000,00
- AVO Meter Digital Sanwa | 1 Buah | Rp933.300,00 | Rp933.300,00
- DC Power | 1 Buah | Rp195.000,00 | Rp195.000,00
- Tang Kit | 1 Buah | Rp115.000,00 | Rp115.000,00
- Obeng Kit | 1 Buah | Rp105.000,00 | Rp105.000,00
- Lem Tembak | 1 Buah | Rp22.500,00 | Rp22.500,00
- Heatsink | 4 Buah | Rp9.800,00 | Rp39.200,00
SUBTOTAL (Rp) | | | Rp2.010.000,00
2. Bahan Habis Pakai | Volume | Harga Satuan (Rp) | Nilai (Rp)
- Sensor Tegangan ZMPT101B | 2 Buah | Rp69.500,00 | Rp139.000,00
- Sensor Arus ACS 712 | 2 Buah | Rp87.500,00 | Rp175.000,00
- Relay | 4 Buah | Rp60.000,00 | Rp240.000,00
- Komponen (Resistor, Kapasitor, dll) | 1 Buah | Rp115.000,00 | Rp115.000,00
- Xbee Pro | 1 Buah | Rp911.500,00 | Rp911.500,00
- MCB DOMAEI 1 Fasa 2/4 A | 4 Buah | Rp47.000,00 | Rp188.000,00
- STM32 | 1 Buah | Rp1.000.000,00 | Rp1.000.000,00
- Micro SD 16GB | 1 Buah | Rp149.000,00 | Rp149.000,00
- USB Downloader | 1 Buah | Rp195.000,00 | Rp195.000,00
- Monitor LCD | 1 Buah | Rp835.000,00 | Rp835.000,00
- Supply DC | 1 Buah | Rp750.000,00 | Rp750.000,00
- Modem dan Router | 1 Buah | Rp1.57.500,00 | Rp1.57.500,00
SUBTOTAL (Rp) | | | Rp6.272.500,00
3. Perjalanan | Volume | Harga Satuan (Rp) | Nilai (Rp)
- Keperluan Pembelian Komponen | 25 Kali | Rp9.850,00 | Rp246.250,00
SUBTOTAL (Rp) | | | Rp246.250,00
4. Lain – Lain | Volume | Harga Satuan (Rp) | Nilai (Rp)
- Proposal dan Administrasi | 5 Buah | Rp12.500,00 | Rp62.500,00
- Banner | 2 Buah | Rp95.000,00 | Rp190.000,00
- Poster | 5 Buah | Rp25.000,00 | Rp125.000,00
- Fee Pembuatan Alat | 1 Kali | Rp3.500.000,00 | Rp3.500.000,00
SUB TOTAL (Rp) | | | Rp3.877.500,00

TOTAL (Rp) Rp12.406.250,00 (Terbilang Dua Belas Juta Empat Ratus Enam Ribu Dua Ratus Lima Puluh Rupiah)

Lampiran 3 Susunan Organisasi Tim Kegiatan dan Pembagian Tugas
No. | Nama/NRP | Program Studi | Bidang Ilmu | Alokasi Waktu (jam/minggu) | Uraian Tugas
1 | Mira Kusuma Wardani | S1 | Teknik Elektro | 10 | Melakukan Studi literatur dan perancangan model sistem alat, mengkordinasikan pembagian tugas, melakukan pengujian dan evaluasi terhadap alat
2 | Arnold Prajna | S1 | Teknik Elektro | 10 | Mendesain serta merancang alat, melakukan pemrograman terhadap sistem yang akan digunakan, merencanakan dan mengatur keuangan
3 | Mochamad Fauzi | S1 | Teknik Elektro | 10 | Pembuatan laporan akhir, merancang model sistem alat, merangkai rangkaian alat dan melakukan pembelian terhadap bahan baku yang digunakan


19 19

Lampiran 5. Gambaran Teknologi yang Akan Diterapkan


Gambar 5.1 Halaman Depan Aplikasi


Gambar 5.2 Fitur Pengaturan


Gambar 5.3 Fitur History Pemakaian


Gambar 5.4 Fitur Peringatan


Gambar 5.5 Fitur Informasi


Gambar 5.6 Posisi Peletakan Sensor Tegangan, Sensor Arus dan Relay


Gambar 5.7 Peletakan Hardware

Skema Kerja Alat Elcomic


Gambar 5.8 Skema Kerja Alat Gambar diatas merupakan skema kerja dari alat kami. Pertama, user melalui aplikasi yang bernama Elcomic memasukkan target anggaran untuk bulan tertentu dan memilih peralatan apa saja yang ingin dikontrol pemakaiannya. Mikrokontroller STM32 akan menyimpan data dan mengitung target rata – rata pemakaian per hari. Sensor arus akan mendeteksi arus yang mengalir dan sensor tegangan akan mendeteksi tegangan pada terminal peralatan. Mikrokontroller akan menghitung daya yang terpakai melalui arus dikalikan tegangan dan menghitung biaya melalui hasil tersebut dikalikan dengan tarif per kWh PLN. Relay akan mematikan peralatan jika sudah melebihi batas pemakaian. Sistem ini juga mengirimkan peringatan pada pengguna jika pemakaian sudah mencapai 50 %, 75 % dan 90 %. Jika harga per kWh berubah, sistem akan memberi tahu pada fitur informasi bahwa sudah terdapat pembaharuan aplikasi agar user segera mendownload sehingga perhitungan biaya dapat tetap relevan dengan sistem PLN.

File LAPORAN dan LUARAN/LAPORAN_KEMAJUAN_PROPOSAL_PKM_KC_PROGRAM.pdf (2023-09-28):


LAPORAN KEMAJUAN PROPOSAL PROGRAM KREATIFITAS MAHASISWA

JUDUL PROGRAM

IMAN KEMPES (Implementasi Antropometri pada Alat Kemudi Pesawat Terbang) : Solusi Untuk Mempermudah Pengendalian Arah Pada Pesawat Terbang.

BIDANG KEGIATAN:

PKM KARSA CIPTA

Diusulkan Oleh:

Meda Aji Saputro; D400150096; 2014

Nur Indah Swariningrum; J210150106; 2015

Lathiifah Thawafani; D400150110; 2015

UNIVERSITAS MUHAMMADIYAH SURAKARTA

SURAKARTA

2018


ii

iii

DAFTAR ISI

HALAMAN JUDUL | i
HALAMAN PENGESAHAN | ii
DAFTAR ISI | iii
BAB 1. PENDAHULUAN | 1

### 1.1 Latar Belakang | 1

BAB 2. TARGER LUARAN | 2

### 2.1 Target Luaran | 2

BAB 3. METODE PELAKSANAAN | 4

### 3.1 Tahap Penyusunan Konsep | 4 3.2 Desain 3D | 5 3.3 Tahap Pembuatan, Pengujian dan Evaluasi | 5

BAB 4. HASIL YANG DICAPAI | 6
BAB 5. POTENSI HASIL | 9

### 5.1 Kesimpulan | 9 5.2 Publikasi | 10

BAB 6. RENCANA TAHAPAN BERIKUTNYA | 10
LAMPIRAN 1 Anggaran Dana | 11
LAMPIRAN 2 Dokumentasi Kegitatan | 15
LAMPIRAN 3 Nota Kegitatan | 18

BAB 1
PENDAHULUAN

### 1.1 Latar Belakang

Ruang kemudi pada umumnya merupakan tempat seseorang untuk mengontrol dan mengendalikan sebuah alat industri atau transportasi pada umumnya, biasanya bagian ini terletak paling depan sebuah alat tersebut. Seperti halnya pesawat terbang, pesawat terbang memiliki ruang kemudi yang disebut cockpit (Juwianto et al, 2014). Cockpit memiliki beberapa instrumen panel dan kontrol yang mana berfungsi untuk mempermudah pilot menerbangkan pesawat terbang. Kontrol pada cockpit pesawat terbang terdiri dari: (i) Control column (tuas kemudi) digunakan untuk roll (gulingan) dan pitch (anggukan) dari pesawat terbang oleh pergerakan elevator (ekor horisontal) dan aileron (ujung belakang sayap); (ii) Rudder pedals (alat kemudi rudder) yang berfungsi menggerakan rudder (sirip pesawat terbang) ke kiri atau kanan yang memungkinkan pesawat untuk bermanuver dan (iii) Kontrol throttle yang disediakan untuk mengontrol kekuatan mesin dan memberikan dorongan pesawat (Grag, 2013)(US.Departement of Transportation, 2016).


Gambar 1. Cockpit pesawat terbang modern Sumber: http://www.aerospace-technology.com

Salah satu faktor yang membuat pekerja dapat bekerja dengan produktif adalah dengan menciptakan lingkungan kerja yang tenang, aman, dan nyaman (Prasetyo, 2011) dengan memasukkan data antropometri. Antropometri (berasal dari bahasa Yunani: Anthorops = manusia; metron = ukuran) adalah pengetahuan yang menyangkut pengukuran tubuh khususnya dimensi tubuh manusia. Antropometri secara luas akan digunakan sebagai pertimbangan-pertimbangan ergonomis dalam proses desain produk maupun sistem kerja yang akan memerlukan interaksi manusia (Nurmianto, 2013). Hal ini tidak terlepas pada perancangan alat kemudi pesawat terbang yang bertujuan agar rancangan dapat terintegrasi dari atas ke bawah sehingga lebih terstruktur, berdasar dan bersifat koheren pada rancangan generasi selanjutnya.

Diharapkan rancangan baru dapat membantu pilot dalam tugasnya menerbangkan pesawat lebih baik (Baxter et al., 2007). Salah satunya adalah rudder pedals. Rudder pedals merupakan bagian dari alat kemudi pesawat terbang yang terletak di bawah instrumen panel dekat kaki pilot pada ruang kemudi (cockpit) dan berfungsi untuk melakukan gerakan gelengan (yaw) ke kiri dan kanan (Daneshjo, 2013) serta memiliki peranan yang sangat penting ketika pesawat berada di darat (Handayo dan Subdibyo, 2011). Akan tetapi desain rudder pedals saat ini dirancang untuk ukuran kaki orang Eropa dan Amerika sehingga kurang ergonomis jika digunakan oleh orang Asia yang memiliki ukuran kaki lebih pendek (ilmuterbang.com) serta dapat menjadi beban kerja mental yang berakibat kecelakaan, karena dari 60% sampai 90% kecelakaan pesawat terbang berasal dari intensitas beban kerja mental yang tinggi (Zongmin, 2014). Dari permasalahan tersebut, maka diusulkan rancangan konseptual alat kemudi rudder berbasis kendali tangan yang mengakomodasi aspek ukuran antropometri dengan persentil 50 dan 90 laki-laki Amerika dewasa, sehingga ergonomis dan nyaman digunakan oleh pilot dari berbagai ras. Secara ringkas inovisi karsa cipta ini dinamakan IMAN KEMPES
Yang merupakan inovasi terbaru di dalam sistem interface primary flight control (alat kemudi)/stir pesawat terbang yang menggabungkan alat kemudi rudder dan control column, yang semula kedua alat ini terpisah. Namun perlu diingat bahwa rancangan IMAN KEMPES ini berbeda prinsip dengan sistem fly by wire. Meskipun begitu IMAN KEMPES tetap membutuhkan sistem fly by wire untuk meneruskan sinyal-sinyal dari cockpit ke sirip-sirip kendali pesawat. Karena pada dasarnya rancangan IMAN KEMPES hanya berfokus pada alat kemudi/stir/antar muka yang berhubungan langsung dengan pilot untuk melakukan beberapa gerakan pada pesawat terbang. Rancangan ini mengadopsi aspek ukuran antropometri dengan persentil 50 dan 90 laki-laki Amerika dewasa dengan mempertimbangankan tingkat keergonomisan, sehingga dalam pengoperasian alat kemudi rudder cukup menggunakan tangan pilot sebab alat tersebut telah menjadi satu bagian pada control column yang dalam pengoperasian juga menggunakan tangan dan alat kemudi rudder dapat dioperasikan tidak harus menggunakan kaki pilot. Hal ini dapat memberikan rasa nyaman, efisien dan kemudahan dalam pengoperasian pada pesawat terbang oleh pilot dari berbagai ras serta dapat mengurangi persentase intensitas beban kerja mental pilot yang dapat berakibat pada kecelakan

BAB II
TARGET LUARAN

### 2.1 Target Luaran

Alat kemudi rudder yang ada saat ini masih menggunakan kaki sebagai penggeraknya dalam mengoperasikan bidang kemudi rudder atau yang disebut rudder pedals, walaupun sudah ada alat tambahan dalam pada rudder pedals. Namun kondisi tersebut dikatakan belum cukup sebab ada sebuah masalah terhadap feedback yang tidak maksimal dari tekanan kaki yang diberikan ke pedal terhadap bidang kemudi rudder. Inovasi tersebut tidak berhenti sampai itu, ada beberapa inovasi salah satunya pada flexible gerakan dan posisi tempat duduk pilot dan menahan beban hentakan hingga 6G. Namun, kursi pilot mempunyai kelemahan yang sangat fatal yaitu kursi tersebut harus terkunci secara benar pada relnya agar tidak bergerak ketika lepas landas atau pun mendarat. Suatu kecelakaan dapat terjadi sebagai akibat dari kursi penerbang yang tiba-tiba bergeser ke belakang diwaktu pesawat mulai rotation saat lepas landas yang mengakibatkan pilot menarik tuas kemudi melebihi yang dibutuhkan, sebab dari reflek sebagai upaya menahan dirinya, sehingga pesawat terbang stall dan jatuh pada posisi mendongak (Hutagaol, 2013). Oleh karena itulah Alat kemudi rudder berbasis tangan tersebut di rasa cukup membantu dalam menyelesaikan masalah ini tanpa mengatur tempat duduk dan menambah alat bantu pada pedal yaitu hanya menggantikan pedal menjadi handle dan dijadikan satu paket dengan control column sehingga menggunakan tangan pilot dan alat kemudi rudder dapat dioperasikan tidak harus menggunakan kaki pilot.. Namun perlu diingat bahwa rancangan IMAN KEMPES ini berbeda prinsip dengan sistem fly by wire. Meskipun begitu IMAN KEMPES tetap membutuhkan sistem fly by wire untuk meneruskan sinyal-sinyal dari cockpit ke sirip-sirip kendali pesawat. Karena pada dasarnya rancangan IMAN KEMPES hanya berfokus pada alat kemudi/stir/antar muka yang berhubungan langsung dengan pilot untuk melakukan beberapa gerakan pada pesawat terbang.
Target luaran yang diharapkan dari program ini adalah dihasilkannya sebuah rancangan konseptual IMAN KEMPES dalam bentuk gambar 3D, prototype IMAN KEMPES dan artikel ilmiah yang akan dimasukan pada jurnal ilmiah nasional.

BAB III METODE PELAKSANAAN; yang akan dilaksanakan.; Tahapan; Metode; Output; Alat dan Bahan; Identifikasi Masalah; Draft Keluhan; Check Sheet; Wawancara Terhadap Pilot dan Forum Diskusi Penerbangan; Data Keluhan Pilot; Pengumpulan Data; Pengumpulan Data Sekunder dari Buku Referensi; Data Anthropometry Orang Dewasa Asia, Eropa, dan Amerika; Penyusunan Konsep; Penentuan Data Anthropometry yang Digunakan; Konsep IMAN KEMPES; Pembuatan Desain 3D; Software Solidwork; Desain 3D Rudder Pedals dengan Software Solidwork; Desain 3D Rudder Pedals; Alat Perkakas Bengkel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

Metode yang digunakan dalam kegiatan ini adalah dengan membuat kerangka kerja, dimana kerangka kerja tersebut akan menjelaskan secara garis besar urutan

Gambar 3.1 Diagram Alir Metode Pelaksanaan

### 3.1. Tahap Penyusunan Konsep

Penyusunan konsep ini adalah membuat sketsa rancangan awal desain alat kemudi rudder berdasarkan data-data yang telah diperoleh dari dua referensi yaitu: (i) Boeing 737 measurements dari referensi Capt. Mark, dengan pertimbangan bahwa Boeing 737 merupakan pesawat komersil yang memiliki teknologi yang sangat mutakhir di zamannya, sekaligus menjadi salah satu objek penelitian dan pengembangan pesawat komersil lainnya. (ii) Data sekunder dimensi tubuh atau anthropometry (Tilley, 1993). Data yang didapatkan dari literatur kedua adalah dimensi tangan laki-laki dewasa Amerika dengan persentil 50% untuk ukuran rata-rata dan 90 % (large man) untuk dimensi tertentu, dengan alasan dimensi tubuh terbesar dimiliki oleh manusia Eropa dan Amerika (Tilley, 1993). Pemilihan persentil tersebut dengan dasar agar ukurannya tidak terlalu besar dan terlalu kecil bagi sebagian ras manusia yang digunakan sebagai pedoman dalam pembuatan desain 3D IMAN KEMPES.

### 3.1.2 Desain 3D

Pembuatan desain 3D dari rancangan konsep yang telah dibuat dengan menggunakan software 3D Solidwork sehingga didapatkan desain 3D IMAN KEMPES.

### 3.1.3 Pembuatan Prototype, Pengujian dan Evaluasi

Pembuatan prototype sesuai dengan konsep dan desain yang telah didapatkan sebelumnya dengan menggunakan alat: (i) alat perkakas bengkel dan bahan utama: (i) control column, (ii) handle, (iii) besi hollow, (iv) kabel wire, poros, dan (v) bearing. Hasil dari pembuatan prototype akan dilakukan pengujian tingkat keandalan dan kenyamanan dengan mengambil sampel sebanyak 20-30 pilot untuk mengoperasikan prototype tersebut. Pengujian ini menggunakan alat ukur anthorpometry sebagai indikator pengujian. Data pengujian yang sudah dilakukan, dicatat dan dijadikan sebagai bahan evaluasi dalam perbaikan

BAB IV
HASIL YANG DICAPAI

Hasil tampilan dari perancangan alat ini dapat dilihat pada gambar 4.1 merupakan desain 3D IMAN KEMPES yang dibuat dengan menggunakan Aplikasi desain yaitu Solidworks Pro 2014 dan gambar 4.2 tampilan fisik prototype IMAN KEMPES yang dibuat sesuai dengan data yang didapat dari data sekuder dan desain yang terlah kami buat di aplikasi desain Solidworks. Untuk data-data ukuran tubuh antropometri setiap ras atau etnisitas sangat berbeda (Tilley, 1993), dan berdasarkan data survei antropometri ukuran ras yang paling besar nilainya dari penelitian Tilley adalah ukuran si Finn dan Amerika (NASA, 1978). Sesuai dengan pengambilan data kami yang tertera pada bab 3 tentang pengambilan data, ada alasan mengapa kami mengambil data atau literatur sekunder dari Tilley. Karena sangatlah susah dan juga membutuhkan waktu yang sangat lama untuk mengukur dan mendapatkan data ukuran tubuh semua manusia dari berbagai macam ras di dunia.


Gambar. 4.1 Desain IMAN KEMPES | Gambar. 4.2 Bentuk fisik

Dalam pembuatan alat kemudi rudder berbasis tangan yang kami sebut dengan IMAN KEMPES ini kami menggunakan data antropometri tangan pria Amerika usia 20-65 tahun dalam persentil pertama (ukuran terkecil) dengan asumsi tangan kemudi dapat digunakan berbagai ras manusia, dan menggunakan persentil ke-99 (ukuran terbesar) sehingga nantinya tidak terlalu kecil / padat untuk tangan besar. Data berikut ini adalah tangan manusia Amerika anthropomerty dalam persentil 1 dan 99 :
Tabel 1. Data percentil yang didapat dari
No. | Kode | Dimensi | Percentile (mm)
1% | 99%
1 | PT | Total Length Hand | 168 | -
2 | PTM | Long Hand Grip | 97 | -
3 | DTM | Diameter Tubes Handheld | 38.1 | -
4 | PTT | Long Hand Center to Center Tubes | 66 | -
5 | PTU | Long Center to End Hand Thumb | 102 | -
6 | PUI | Long Edge to Edge Thumb Tubes | 74.1 | -
7 | LTM | Width Hand Grip | 86.36 | -
8 | L4J | The Total Width of Four Fingers | 79 | -

9 | PIJ | Long Toe to Edge of Finger | 69 | -
10 | LP4JB | The Total Width of The Four Fingers | - | 93
11 | T1 | Thick Finger Finger + (Allowance 8 Mm) | - | 32
12 | T2 | Thickness Middle Finger + (Allowance 4 Mm) | - | 29
13 | T3 | Thick Ring Finger + (Allowance 4 Mm) | - | 28
14 | T4 | Thick Finger Little Finger + (Allowance 2 Mm) | - | 26
15 | D1 | Depth Finger Finger X ½ | - | 11.5
16 | D2 | Depth Middle Finger X ½ | - | 12
17 | D3 | Depth Ring Finger X ½ | - | 12
18 | D4 | Depth Finger Little Finger X ½ | - | 11.5

Data ukuran tersebut yang kami gunakan adalah ketika tangan dalam bentuk menggenggam pada suatu handle dan stir/kemudi kendaraan seperti pada gambar 4.3.


Gambar 4.3.Desain alat kemudi rudder berbasis tangan yang sudah mengadopsi anthropometry

Sehingga kami mendesain alat tersebut sesuai dengan ukuran-ukuran yang diperoleh dengan menggunakan Aplikasi desain yaitu Solidworks Pro 2014, seperti yang terdapat pada gambar 4. Dari desain tersebut digunakan untuk pembuatan prototype alat kemudi rudder (gambar 5). Untuk mengetahui tingkat keergonomisan dan kenyamanan kami melakukan uji coba pada alat dengan mengambil sampel 20 orang yang terdiri dari 16 mahasiswa dan 4 pilot dengan keluhan rasa sakit atau pegal di tangan (seperti gambar 4.4; 4.5). Dalam hal ini kami hanya mampu mendapatkan 4 pilot dalam pengujian kenyamanan pada alat kami, yang mana karena kesibukan para pilot yang kami hubungi sebelumnya akan pekerjaannya. Meskipun itu kami menggantikannya dengan 16 mahasiswa, Untuk mahasiswa sendiri kami mengambil setidaknya 2 kartegori yaitu 6 mahasiswa dengan pengetahuan akan dunia penerbang dan juga pernah mengendarai pesawat terbang pada flight simulator dengan jam terbang sekurang-kurangnya 15 jam terbang dan 10 mahasiswa biasa tanpa pengetahuan penerbangan dan tanpa pernah mengendarai pesawat terbang pada simulator. Serta dengan tinggi badan yang bervariatif yaitu 180-175 cm, 175-170 cm, 170-165 cm, dan 165-160 cm dengan lama waktu penggunaan 30 menit dan didapat hasil seperti berikut :
Tabel 2. Hasil pengujian Kenyamanan
NO | Nama Karespondensi | Jenis Kelamin | Tinggi Badan | Keluhan
1 | Sdr. A | L | 163 cm | Tidak Ada
2 | Sdr. Z | L | 170 cm | Latah
3 | Sdr. A | L | 165 cm | Latah
4 | Sdr. T | L | 160 cm | Tidak Ada
5 | Sdr. H | L | 175 cm | Latah
6 | Sdr. N | L | 168 cm | Latah
7 | Sdr. J | L | 174 cm | Tidak Ada
8 | Sdr. W | L | 178 cm | Tidak Ada
9 | Sdr. S | L | 165 cm | Latah
10 | Sdr. R | L | 170 cm | Latah
11 | Sdr. B | L | 180 cm | Latah
12 | Sdr. Y | L | 178 cm | Tidak Ada
13 | Sdr. N | L | 170 cm | Tidak Ada
14 | Sdr. J | L | 165 cm | Latah
15 | Sdr. T | L | 170 cm | Tidak Ada
16 | Sdr. M | L | 168 cm | Latah
17 | Sdr. S | L | 164 cm | Tidak Ada
18 | Sdr. F | L | 168 cm | Latah
19 | Sdr.H | L | 167 cm | Latah
20 | Sdr. M | L | 170 cm | Tidak Ada

. Dari hasil pengujian didapat hampir tidak ada keluhan rasa sakit atau pegal pada tangan dan pergelangan tangan hanya saja dari karesponden menyatakan bahwa karespondensi sering melakukan kegiatan semacam latah atau lupa (seperti kondisi dimana seseorang yang kebiasaan sehari-hari menggunakan sepada motor bebek lalu pada suatu hari menggunakan sepeda motor matic yang terkadang kaki pengendara tersebut sering bergerak secara otomatis untuk memindahkan proseneling, padahal sepeda motor yang dikendarai adalah sepeda motor matic). Kegiatan latah di ungkapkan oleh karespondensi dari mahasiswa dengan pengetahuan akan dunia penerbang dan juga pernah mengendarai pesawat terbang pada flight simulator dengan jam terbang sekurang-kurangnya 15 jam dan pilot ini perlu maklum, karena pada dasarnya alat kemudi pesawat yang menggabungkan kedua alat kemudi ini belum pernah ditemukan di beberapa pesawat komersil maupun militer, baik pesawat yang berbadan kecil walaupun di pesawat berbadan besar Berikut adalah gambar pengujian alat kemudi rudder IMAN KEMPES di Kampus 4 Universitas Muhammadiyah Surakarta


Gambar 4.4 pengguna pertama | Gambar 4.5 pengguna kedua


Gambar 4.6 pengguna ketiga | Gambar 4.7 pengguna keempat

BAB V
| POTENSI HASIL

### 5.1. Kesimpulan

Berdasarkan hasil dari penelitian diatas, dapat disimpulkan bahwa alat kemudi rudder berbasis kendali tangan merupakan penggabungan alat kemudi rudder dan control column dengan memberikan handle yang sudah diadopsi oleh ukuran tangan anthropometry persentil 50 dan 90 laki-laki Amerika dewasa, sehingga dalam pengoperasian alat kemudi rudder cukup menggunakan tangan. Hal ini dapat menciptakan kemudi yang lebih nyaman, efisien, mudah dan dapat digunakan oleh pilot dari berbagai macam ras. Prototype kemudian diujikan terhadap 20 calon pengguna untuk melihat tingkat keandalan dan kenyamanan dari alat yang dirancang dari hasil pengujian diperoleh bahwa tidak ada keluhan rasa sakit dan pegal pada tangan hanya saja ada kegiatan latah pada pengguna. Kegiatan latah ini perlu maklumi karena pada dasarnya alat kemudi pesawat yang menggabungkan kedua alat kemudi ini belum pernah ditemukan di beberapa pesawat komersil maupun militer, baik pesawat yang berbadan kecil walaupun di pesawat berbadan besar.

### 5.2. Publikasi

Publikasi yang telah dilakukan yaitu publikasi di MTA TV dan submit 2 jurnal pada 8th University Research Colloqium (URECOL) di Universitas Muhammadiyah Purwokerto.

BAB VI

RENCANA TAHAP SELANJUTNYA

Rencana untuk tahap berikutnya dilakukan yaitu :

### 1. Submit Jurnal pada Rekayasa Aplikasi Perancangan dan Industri (RAPI) ke

XVII di Universitas Muhammadiyah Surakarta.

### 2. Hak Paten melalui LPPM UMS

IMAN KEMPES yang berupa alat kemudi rudder berbasis tangan yang dibuat akan dipatenkan melalui LPPM UMS dan dipamerkan pada kegiatan-kegiatan Pameran yang diselenggarakan oleh LPPM UMS guna untuk memperkenalkan alat tersebut ke dunia industri khususnya industri penerbangan, yang mana harapan kami yaitu agar mampu menjadi alternatif dalam mengatasi dan mengurangi tindakan rasa kurang nyaman pada alat kemudi pesawat terbang.

Lampiran 1. Penggunaan Dana
A. Bahan habis pakai
Tangal | Uraian | Volume | Harga Satuan (Rp) | Jumlah (Rp.)
10 April 2018 | Lem Alteco | 3 | 6.500 | 19.500
16 April 2018 | PLS 303 IT | 1 | 6.000 | 6.000
27 April 2018 | Lapban Daimaru | | | 11.000
1 Mei 2018 | 1. Kabel Kawat/Tig | 2 | | 30.000
| 2. Isolasi Kertas | 1 | | 5.000
| 3. Lem Alteco | 2 | | 12.000
| 4. Daimaru lapban | 2 | 8.500 | 17.000
| 5. GB P 50 X 100 X 2 | 1 | 10.000 | 10.000
9 Mei 2018 | Control coloum | 1 | 1.500.000 | 1.500.000
14 Mei 2018 | 1. Master dan Handle rem sepeda motor | 2 125.000 | 95.000 | 220.000
| 2 Bearing | 4 | 27.000 | 108.000
| 3. Plat | 9 | 12.000 | 108.000
| 4. oli skok | 2 | | 20.000
| 5. baut | 20 | 800 | 16.000
18 Mei 2018 | Alfa Gloss | 1 | 35.000 | 35.000
20 Mei 2018 | 1. Duplek Plano | 2 | 6.000 | 12.000
| 2. Yellow Board | 2 | 8.000 | 8.000
| 3. Garisan Besi | 1 | 5.600 | 5.600
| 4. GB P 40 X 60 X 1,5 cm | 2 | 5.000 | 10.000
| 5. Debozz DB-M510 Jang | 1 | 16.500 | 16.500
| 6. Lem Epotek | 1 | 7.200 | 7.200
21 Mei 2018 | 1. Besi bundar hollow | 2 | 200.000 | 400.000
| 2. Master dan Handle rem sepeda motor | 4 135.000

| 3. Bearing | 4 | 28.000 | 112.000
10 Juni 2018 | 1. Handle Mio variasi 1 set | 2 | 195.000 | 390.000
| 2.Master Rem Supra | 2 | 175.000 | 350.000
| 3.Mur dan Baut | 1 Set | | 50.000
9 Juli 2018 | 1. Master Rem Supra lengkap | 2 | | 205.000
| 2. Maspran 1/2" | 1 | | 18.000
| 3. T 1/2” | 2 | | 7.000
| 4. Knie 1/2" | 2 | | 6.000
| 5. Knie 2” | 2 | | 10.000
| 6. Overlup 2” ¼ | 1 | | 5.000
| 7. C. Tik | 1 | | 4.000
TOTAL | | | | 3.868.800
B. PeralatanPenunjang
Tanggal | Nama Alat | Volume | Harga Satuan (Rp) | (Rp.)
20 Mei 2018 | Penggaris | 1 | 5.600 | 5.600
| Kenko cutter | 1 | 5.000 | 5.000
21 Mei 2018 | Amplas halus dan kasar | 2 set | 20.000 | 40.000
| Alat ukur : Busur dan penggaris | 1 | 19.500 | 19.500
| Gergaji Kayu | 1 | 30.000 | 30.000
| Mata gerinda | 5 | 10.000 | 50.000
Total | | | | 150.100
C. Lain-lain
No | Jenis Pengeluaran | Tanggal | Nama Barang | Jumlah (Rp)
1 Kesekertariatan | | 10 April 2018 | Print proposal dan FC | 14.300
| | 1 Juni 2018 | Print laporan | 35.000
| | 5 Juni 2018 | Print Gambar Kerja | 24.000

| 7 Juni 2018 | Print Gambar Kerja | 19.500
| 9 Juli 2018 | Print Laporan | 38.000
2 Transportasi | 21 April 18 | Pertalite | 50.000
| 23 April 18 | Pertalite | 26.000
| 25 April 2018 | Pertalite | 30.000
| 27 April 2018 | Pertalite | 28.000
| 9 Mei 2018 | Perjalanan Bandara Soetta- Depok | 45.000
| 10 Mei 2018 | Perjalanan Depok -Solo | 160.000
| 5 Juli 2018 | Perjalanan Surabaya -Solo | 117.500
| 6 Juli 2018 | Pertalite | 34.000
| 10 April 2018 | Konsumsi Anggota | 8.000
| 22 April 2018 | Konsumsi Anggota | 18.000
| 24 April 2018 | Kosumsi Anggota | 37.851
| 26 April 2018 | Konsumsi Anggota | 22.400
| 30 April 2018 | Konsumsi Anggota | 6.800
| 30 Mei 2018 | Konsumsi Karespondensi | 85.000
| 17 Juni 2018 | Konsumsi Laboran | 24.000
| 3 Juli 2018 | Konsumsi Karespondensi | 48.000
| 4 Juli 2018 | Konsumsi Laboran | 10.000
| 6 Juli 2018 | Konsumsi Anggota | 34.200
| 9 Juli 2018 | Konsumsi Anggota | 25.000
Total | | | 940.551

### 3 Konsumsi

No | Jenis Pengeluaran | Biaya (Rp)
1 | Bahan Habis Pakai | 3.868.800
2 | Peralatan Penunjang | 150.100
3 | Lain-Lain | 940.551
TOTAL | | 4.959.451

Lampiran 2. Dokumentasi Kegiatan


Gambar 1. Submit Artikel Ilmiah/Jurnal di 8th URECOL Universitas Muhammadiyah Purwokerto


Gambar. 2 Publikasi Prototype di MTA TV


Gambar 3 Proses Pembuatan rancang bangun prototype alat IMAN KEMPES


Gambar 4. Pengujian prototype rancang bangun IMAN KEMPES

Lampiran 3. Nota Kegiatan





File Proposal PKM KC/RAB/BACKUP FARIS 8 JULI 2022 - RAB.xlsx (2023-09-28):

1. Perlengkapan | kuantitas | satuan | Harga Satuan | Nilai (RP) | link beli
breadboard | 1 | unit | Rp 32000 | Rp 32000 | https://www.tokopedia.com/akhishop/solderless-breadboard-transparan-syb-120
kabel jumper | 2 | paket | Rp 15000 | Rp 30000 | https://www.tokopedia.com/akhishop/kabel-jumper-female-to-female-30cm-isi-40-kabel
timah | 1 | unit | Rp 44000 | Rp 44000 | https://www.tokopedia.com/isee/timah-kaina-100gr-b-2-solder-wire-0-8mm-63-37-flux-2-original-fine
solder | 1 | unit | Rp 70000 | Rp 70000 | https://www.tokopedia.com/isee/dekko-dcs30-30w-soldering-iron-alat-solderan-solder-deko-biru-dcs-30-w
Cetakan Beton | 2 | unit | Rp 600000 | Rp 1200000
Peralatan K3 | 4 | paket | Rp 50000 | Rp 200000
kabel 3p | 5 | meter | Rp 6000 | Rp 30000 | estimasi https://www.tokopedia.com/arduinoid/kabel-serabut-awg24-multicore-isi-12-10-8-6-4-3-2-jalur-kabel-data-1m-3jalur
 |  |  |  | Rp 0
 |  |  |  | Rp 0
sub total |  |  |  | Rp 1606000
2. Bahan Habis Pakai | kuantitas | satuan | Harga Satuan | Nilai (RP)
mikrokontroller ESP32 devkit v4 | 2 | unit | Rp 80000 | Rp 160000 | https://www.tokopedia.com/akhishop/esp32-devkitc-v4-development-board-esp32-wroom-32d-esp32-wroom-32u-esp32-wroom-32u
digital caliper | 2 | unit | Rp 975000 | Rp 1950000 | https://www.tokopedia.com/rekomendasi/609847508?c=11973662787&m=131165158&p=609847508&txsc=google&gclsrc=aw.ds
hosting | 1 | unit | Rp 275880 | Rp 275880 | hostinger
domain web | 1 | unit | Rp 140000 | Rp 140000 | hostinger
adaptor 12v 1A | 1 | unit | Rp 34000 | Rp 34000 | https://www.tokopedia.com/isee/adaptor-dc-12v-2a-power-supply-eu-plug-5-5mm-x-2-1-2-5mm-high-quality
dc stepdown (lm 2596) | 1 | unit | Rp 12000 | Rp 12000 | https://www.tokopedia.com/akhishop/lm2596-dc-dc-step-down-module
DS18B20 (probe) | 2 | unit | Rp 20000 | Rp 40000 | https://www.tokopedia.com/akhishop/waterproof-ds18b20-temperature-probe
komponen elektronik lain | 1 | paket | Rp 150000 | Rp 150000 | isee/ berkat
konektor (molex, pinheader, mur, baut, dll) | 1 | paket | Rp 50000 | Rp 50000 | isee/ berkat
Pasir | 0.25 | col | Rp 280000 | Rp 70000
Batu Kerikil | 0.25 | col | Rp 290000 | Rp 72500
Semen OPC | 1 | sak | Rp 50000 | Rp 50000
styrofoam tebal 1 cm 100 x 50 | 5 | Lembar | Rp 20000 | Rp 100000
Acrylic case ESP32 | 1 | unit | Rp 35000 | Rp 35000 | https://www.tokopedia.com/isee/acrylic-case-box-king-chasis-for-nodemcu-v3-ch340-lolin-with-lcd-16x2
PCB print | 1 | unit | Rp 50000 | Rp 50000
sub total |  |  |  | Rp 3189380
3. Perjalanan dalam Kota | kuantitas | satuan | Harga Satuan | Nilai (RP)
Transport lokal (untuk keperluan pembelian bahan dan uji coba) | 4 |  | Rp 100000 | Rp 400000
 |  |  |  | Rp 0
 |  |  |  | Rp 0
 |  |  |  | Rp 0
sub total |  |  |  | Rp 400000
4. Lain-lain | kuantitas | satuan | Harga Satuan | Nilai (RP)
Print administrasi | 100 | lembar | Rp 500 | Rp 50000
Alat tulis kantor | 4 | paket | Rp 30000 | Rp 120000
Perlengkapan protokol kesehatan | 4 | orang | Rp 120000 | Rp 480000
Publikasi jurnal | 1 | kali | Rp 1000000 | Rp 1000000
materai | 2 | unit | Rp 10000 | Rp 20000
sub total |  |  |  | Rp 1670000
total |  |  |  | Rp 6865380

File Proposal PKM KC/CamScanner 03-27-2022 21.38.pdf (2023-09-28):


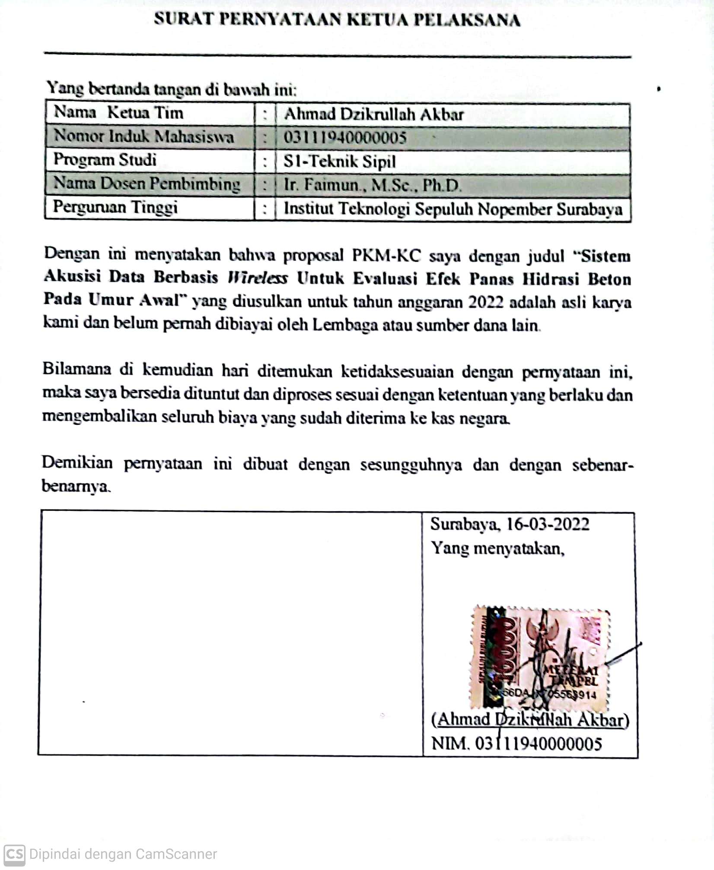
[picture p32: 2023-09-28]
Proposal PKM KC/CamScanner 03-27-2022 21.38.jpg

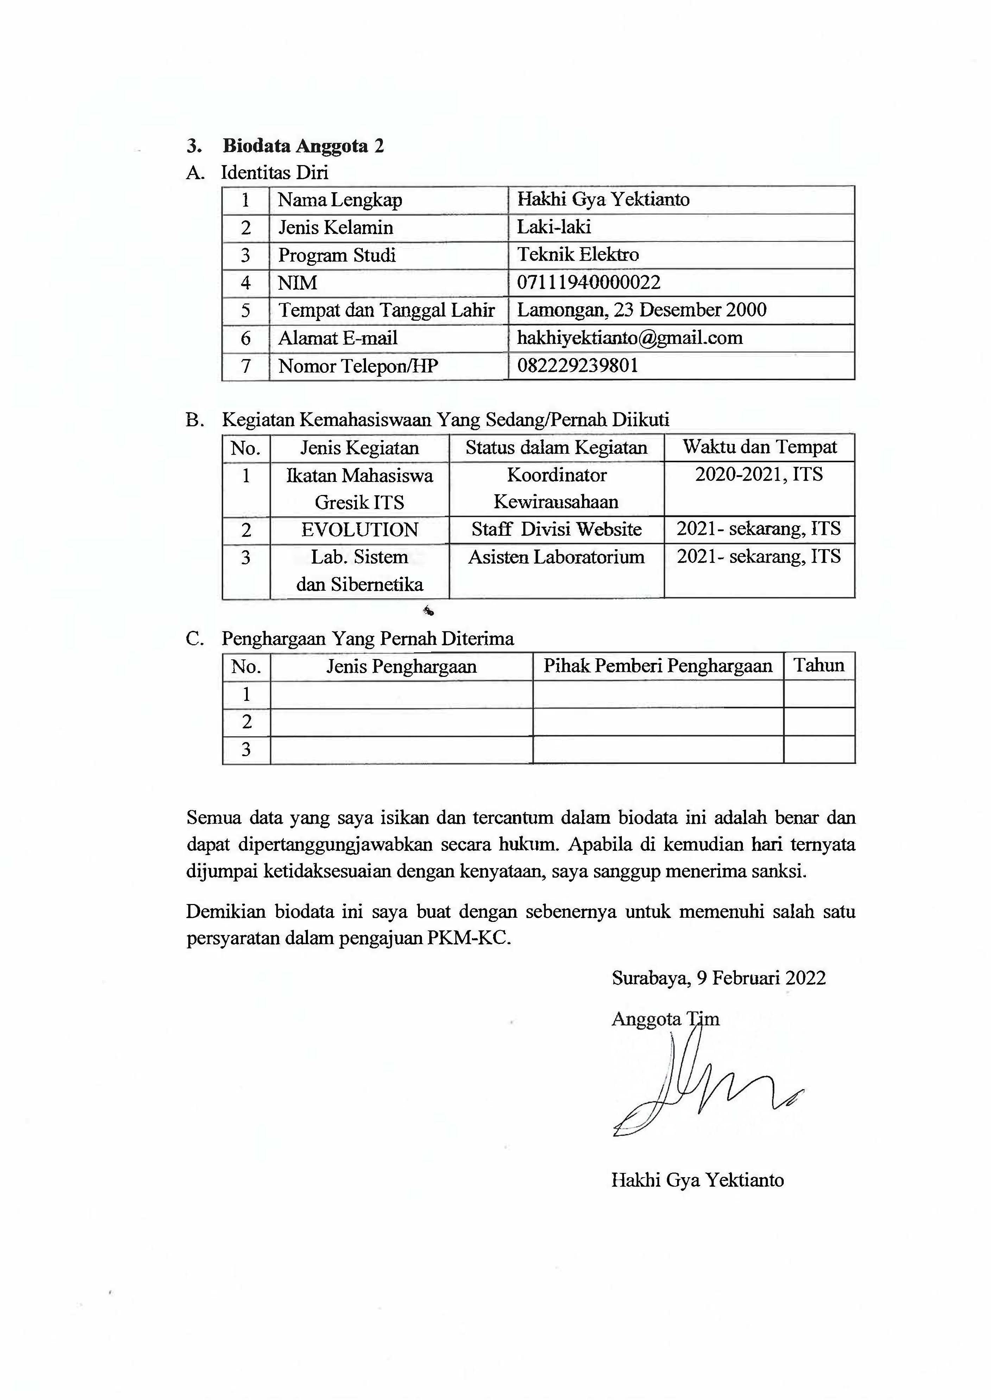
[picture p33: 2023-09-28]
Proposal PKM KC/Biodata/Scan biodata Hakhi.jpg

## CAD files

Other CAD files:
Prototype/6+inch+digital+caliper.skp
Prototype/Bolt+M12+dynamic.skp
Prototype/Prototype 2018/prototype uji autogenous shrinkage 18.skp
Prototype/Prototype 2018/м8.skp
Prototype/Spring.skp
Prototype/bolt.skp
Prototype/prototype uji autogenous shrinkage.skp
Prototype/м8.skp

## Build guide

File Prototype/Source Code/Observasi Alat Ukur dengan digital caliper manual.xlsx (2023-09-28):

 | Observasi Alat Ukur dengan digital caliper manual.
 | length (mm)
No | Caliper Manual | Caliper Digital Terbaca ESP32 | error
1 | 0.00 | 0.01 | 0.01
2 | 10.00 | 9.88 | 0.12
3 | 20.00 | 19.88 | 0.12
4 | 30.00 | 29.77 | 0.23
5 | 40.00 | 39.81 | 0.19
6 | 50.00 | 49.70 | 0.3
7 | 60.00 | 59.73 | 0.27
8 | 70.00 | 69.64 | 0.36
9 | 80.00 | 79.68 | 0.32
10 | 90.00 | 89.65 | 0.35
11 | 100.00 | 99.68 | 0.32
12 | 110.00 | 109.70 | 0.3
13 | 120.00 | 119.70 | 0.3
14 | 130.00 | 129.66 | 0.34
 |  |  | 0.2521428571

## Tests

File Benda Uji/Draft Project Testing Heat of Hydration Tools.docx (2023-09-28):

Draft Project Testing Heat of Hydration Tools

Latar Belakang

Prosedur Pengetesan

Standard of Heat Temperatures

Accusation of Temperatures

Sensor

Testing Method

Materials

Mix Design Beton

Method : ACI R411

Mutu Beton (f’c) : 28 MPa

Slump rencana :

w/c :

Air :

% Udara :

Tipe semen :

Kebutuhan semen :

Gradasi

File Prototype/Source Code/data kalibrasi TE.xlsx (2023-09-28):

 | TE #1 15cm |  |  | TE #2 15cm |  |  | TE #3 10cm |  |  | TE #4 10cm
Setpoin | BEFORE YOKOGAWA CA71 | BEFORE MAX6675 | ERROR MUTLAK | BEFORE YOKOGAWA CA71 | BEFORE MAX6675 | ERROR MUTLAK | BEFORE YOKOGAWA CA71 | BEFORE MAX6675 | ERROR MUTLAK | BEFORE YOKOGAWA CA71 | BEFORE MAX6675 | ERROR MUTLAK
40 | 40.5 | 42.61 | 2.11 | 41.6 | 41.38 | 0.22 | 39.6 | 39.89 | 0.29 | 40.4 | 39.68 | 0.72
60 | 60.2 | 62.71 | 2.51 | 59.8 | 61.49 | 1.69 | 58.4 | 59.75 | 1.35 | 58.1 | 58.42 | 0.32
80 | 80.4 | 82.19 | 1.79 | 80 | 82.59 | 2.59 | 78.6 | 79.07 | 0.47 | 78.1 | 78.67 | 0.57
100 | 99.7 | 101.47 | 1.77 | 99.4 | 101.05 | 1.65 | 96.68 | 98.2 | 1.52 | 97.2 | 98.8 | 1.6
 |  | AVG ERROR: | 2.045 |  | AVG ERROR: | 1.5375 |  | AVG ERROR: | 0.9075 |  | AVG ERROR: | 0.8025

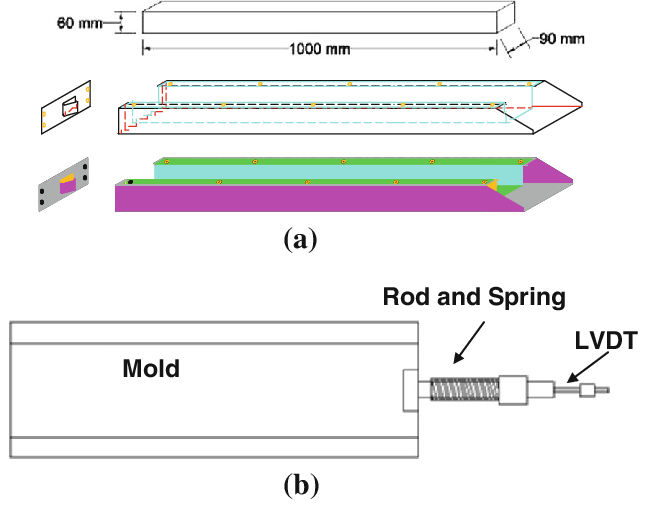
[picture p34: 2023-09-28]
Prototype/Autogenous-shrinkage-test-set-up-a-Inner-and-outer-molds-of-shrinkage-drain-b-set-up.png

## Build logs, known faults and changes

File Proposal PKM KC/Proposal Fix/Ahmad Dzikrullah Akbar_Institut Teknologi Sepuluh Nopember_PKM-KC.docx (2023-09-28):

# DAFTAR ISI

# DAFTAR GAMBAR

# DAFTAR TABEL

## BAB 1. PENDAHULUAN

## 1.1 Latar Belakang

Beton merupakan material yang seringkali digunakan pada konstruksi dalam kondisi lingkungan tidak terkendali yang menyebabkan kerusakan struktur seiring berjalannya waktu, sehingga kualitas mutu beton perlu dikendalikan. Beton dengan mutu tinggi memerlukan pengendalian terhadap masalah panas hidrasi yang tinggi. Utamanya, ketika pelaksanakan pengecoran dengan volume yang masif. Beton akan kesulitan menurunkan suhu hidrasi karena memiliki sifat “Poor Thermal Conductivity”. Pada saat bersamaan dengan peningkatan suhu, beton mengalami penyusutan volume internal akibat hidrasi semen yang disebut dengan Autogenous Shrinkage. Perbedaan suhu yang besar yang terjadi antara bagian tengah dan muka beton mengakibatkan susut semakin membesar (Gowripalan, 2020). Susut yang tidak dibatasi akan menyebabkan tegangan tarik yang memunculkan retak micro atau macro pada beton. Kualitas mutu beton akan menurun dengan adanya keretakan ini, terutama ketika retak terjadi sejak umur awal beton. (Springenschmid, 2004). Monitoring pengukuran suhu dan susut yang terjadi sebagai efek dari panas hidrasi di umur awal beton penting sebagai evaluasi kematangan mutu beton.

Pengukuran suhu beton yang ideal memiliki akurasi ±0,2ºC, yang merupakan nilai simpangan (noise) akibat pengaruh lingkungan, dengan kapasistas ukur alat minimum 50ºC (Astm C1064/C1064M-04, 2004). Untuk mendapatkan nilai simpangan akibat pengaruh lingkungan yang ideal tersebut, proses pengukuran perlu dilakukan pada kondisi panas internal beton yang terisolasi sempurna atau mengalalami sistem adiabatik. Akan tetapi, sistem adiabatik sulit terjadi di lapangan. Oleh karena itu, untuk tetap mempertahankan pengukuran yang ideal, dilakukan pendekatan sistem semi adiabatik. Pendekatan ini dilakukan dengan mengisolasi beton menggunakan styrofoam box, dengan pendekatan ini akan diperoleh nilai simpangan yang kecil (Awal & Hussin, 2010). Peningkatan suhu internal terjadi bersamaan dengan perubahan susut beton, sehingga perubahan susut diukur juga bersamaan dengan suhu dalam satu spesimen yang sama. Pengukuran susut yang ideal harus memenuhi syarat dalam ASTM C1698. Kedua pengukuran tersebut merupakan parameter yang digunakan dalam evaluasi kematangan mutu beton. Terdapat dua indikator kematangan mutu beton dengan data pengukuran tersebut, yaitu maturity index yang didapatkan dari perbandingan hasil pengukuran suhu dan tes kuat tekan beton, dan grafik hubungan susut beton versus suhu beton tiap waktu ukur. Untuk itu, Alat pengukuran dan sistem akusisinya menjadi faktor penting dari ketersediaan data parameter evaluasi kualitas kematangan beton.

Saat ini, pengambilan data yang umum menggunakan sensor suhu, sensor displacement susut dan diakusisi oleh data logger menuju komputer atau bahkan dicatat secara manual (Kim et al., 2009). Akusisi data dengan sistem ini beresiko mudah mengalami kehilangan data record karena pada kondisi monitoring realtime terdapat banyak gangguan dan kurang praktis karena data tidak dapat dipantau secara online serta memperlukan komputer yang harus menyala ketika monitoring, dimana monitoring dilakukan selama 24 jam. Berdasarkan permasalahan tersebut, Inovasi yang diberikan adalah perancangan sistem monitoring dengan automasi transfer data ke cloud database sebagai wadah penyimpanan dan pengolahan data. Transfer data dari penyimpanan internal dapat dilakukan secara otomatis atau dikendalikan oleh pengguna saat terdapat jaringan internet. Data inputan yang telah ditransfer, diolah dalam pemrograman untuk mendapatkan Maturity Index dan grafik hubungan susut versus suhu sebagai tinjauan evaluasi kematangan beton akibat efek panas hidrasi. Selain itu, inovasi dilakukan pada komponen alat ukur yaitu modifikasi kaliper digital yang umumnya ada pada jangka sorong digital menjadi pengukur susut beton yang akan bekerja bersamaan dengan pengukuran suhu oleh sensor thermocouple. Gagasan ide ini diharapkan dapat terealisasi sehingga permasalahan panas hidrasi pada beton dapat diselesaikan.

## 1.2 Rumusan Masalah

Bedasarkan uraian latar belakang yang dijelaskan diatas, maka didapatkan poin-poin masalah dalam proposal ini adalah sebagai berikut,

1. Bagaimana merancang prototype alat (Hardware) untuk mengukur parameter evaluasi mutu beton sebagai efek panas hidrasi secara otomatis?
2. Bagaimana menyusun algoritma pada program (website) untuk menghasilkan indikator tinjauan mutu beton sebagai efek panas hidrasi?
3. Bagaimana keandalan penggunaan prototype terhadap hasil pengukuran dan evaluasi mutu beton akibat efek panas hidrasi?

## 1.3 Tujuan

Adapun tujuan yang akan dicapai berdasarkan poin-poin permasalahan pada rumusan masalah, adalah sebagai berikut:

1. Terciptanya rancangan prototype alat (Hardware) untuk mengukur parameter evaluasi mutu beton sebagai efek panas hidrasi secara otomatis.
2. Mengetahui susunan algoritma pada program untuk menghasilkan indikator tinjauan mutu beton sebagai efek panas hidrasi.
3. Mengetahui tingkat reabilitas penggunaan prototype terhadap hasil pengukuran dan evaluasi mutu beton akibat efek panas hidrasi.

## 1.4 Luaran yang Diharapkan

Selain, kelancaran dalam pelaksanaan perancangan alat pada proposal ini,target kami dalam PKM-KC ini adalah:

1. Artikel ilmiah, laporan kemajuan, dan laporan akhir yang sesuai kriteria penilaian;
2. Alat yang berfungsi dengan baik, dan dapat digunakan oleh masyarakat luas.

## 1.5 Manfaat Implementasi Prototype

Manfaat yang dapat diambil dengan terealisasinya prototype, sebagai berikut.

1. Bagi Akademisi: Menunjang riset terkait inovasi beton yang mengkaji panas hidrasi sebagai properties beton. Pengembangan alat dapat menjadi bahan studi bagi mahasiswa teknik sipil dan elektro.
2. Bagi Industri Konstruksi: Monitoring perawatan dan evaluasi mutu beton murah, dan praktis. Data histori yang terakusisi dan tersimpan dengan baik membantu pencarian problem pada sistem struktural pekerjaan konstruksi.

## BAB 2. TINJAUAN PUSTAKA

## 2.1 Panas Hidrasi

Salah satu komponen penting dalam beton adalah semen. Semen mengandung senyawa kimia yang tidak stabil secara termodinamika saat bereaksi hidrasi dengan air. Sehingga, pembentukan produk hidrasi akan menghasilkan panas (Exotherm). Panas akibat proses tersebut disebut dengan panas hidrasi (Nugraha & Antoni, 2007). Komposisi semen yang berperan dalam reaksi hidrasi disajikan, sebagai berikut.

Tabel 2. 1 Komposisi Utama Semen

Bahan | Kecepatan Hidrasi | Panas Hidrasi (Joule/gram) | Kontribusi kekuatan | Susut
C3S | Cepat | 503 – tinggi | dalam 28 hari | Sedang
C2S | Lambat | 260 – rendah | > setelah 28 hari | Sedang
C3A | Sangat Cepat | 867 – sangat tinggi | dalam 1 hari | Besar
C4AF | Cepat | 419 – sedang | < 1 hari | Kecil

Sumber: Nugraha and Antoni, 2007

Komposisi semen berupa C3S (alite) dan C2S (belite) memiliki sifat perekat. Senyawa ini dapat memiliki sifat perekat karena reaksi hidrasinya membentuk Calsium Silicate Hydrate (C-S-H) yang berkontribusi pada kuat tekan beton. Kuat tekan beton pada umur awal dipengaruhi oleh C3S karena reaksi hidrasinya lebih cepat daripada C2S. Hidrasi C3S yang cepat menghasilkan panas yang tinggi.

Komposisi semen lain yang berperan dalam meningkatkan panas hidrasi adalah C3A (Tricalsium Aluminate) yang berperan pada proses pengerasan beton. C3A mengalami hidrasi yang sangat cepat sehingga perlu dikontrol dengan penambahan gipsum dan adanya katalisator C4AF (Nugraha & Antoni, 2007). Mekanisme reaksi hidrasi semen dalam beton diilustrasikan pada gambar, berikut.

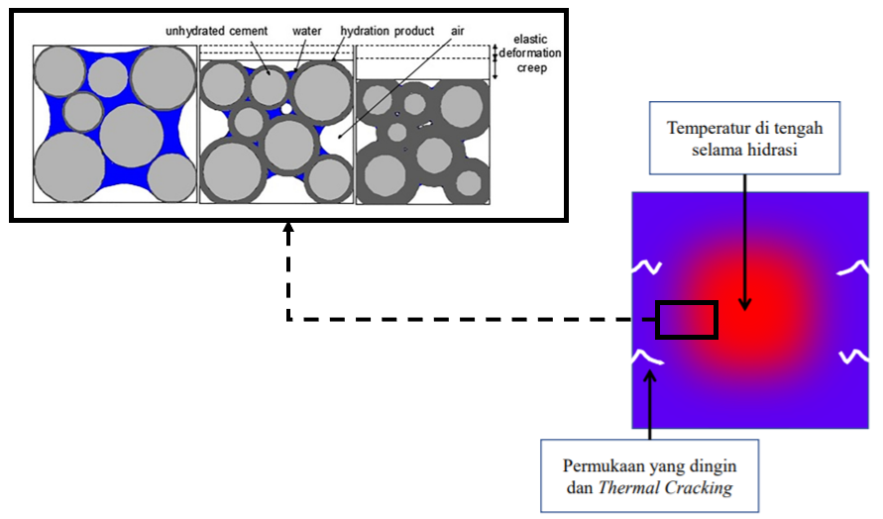
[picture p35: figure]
P113#yIS1

Gambar 2. 1 Ilustrasi Mekanisme Panas Hidrasi
(Amshar et al., 2018; Lu et al., 2020)

Berdasarkan Ilustrasi mekanisme reaksi hidrasi di atas menunjukkan bahwa panas yang terjadi pada bagian tengah beton lebih tinggi dari daerah sekeliling muka beton. Panas hidrasi semen pada beton sulit untuk turun, terutama pada beton dicor dengan volume yang massif. Hal ini disebabkan oleh sifat “Poor Thermal Conductivity” beton (American Concrete Institute (ACI), 2008).

## 2.2 Parameter Evaluasi Mutu Beton Akibat Efek Panas Hidrasi

Indikator panas hidrasi yang umum adalah suhu. Pengukuran suhu beton yang ideal memiliki akurasi ±0,2ºC, yang merupakan nilai simpangan (noise) akibat pengaruh lingkungan, dengan kapasistas ukur alat minimum 50ºC (Astm C1064/C1064M-04, 2004). Untuk mendapatkan hasil pengukuran ideal tersebut, beton diisolasi dalam styrofoam box. (Awal & Hussin, 2010). Peningkatan suhu internal terjadi bersamaan dengan perubahan susut beton, sehingga perubahan susut diukur juga bersamaan dengan suhu dalam satu spesimen yang sama.

Susut massal yang terjadi ketika semen bereaksi hidrasi selama terjadi peningkatan suhu disebut dengan Autogenous shrinkage. Autogenous shrinkage jarang terjadi pada beton konvensional atau terjadi dengan nilai susut kurang dari 100µ ε . Akan tetapi, pada beton mutu tinggi dengan rasio air per semen yang rendah atau mrnggunakan silica fume dapat mengalami susut ini (Gowripalan, 2020). susut secara makroskopis terjadi saat semen mulai bereaksi hidrasi (initial setting time) (Taizawa, 2003). Hidrasi semen dengan rasio air per semen kurang dari 0.42 mulai memberikan efek autogenous shrinkage (Holt, 2001). Hasil pengukuran suhu dan susut menjadi parameter evaluasi mutu beton akibat efek panas hidrasi dalam bentuk grafik hubungan suhu versus susut.

Grafik yang didapatkan ditunjang dengan analisis kematangan beton. Estimasi kematangan beton merupakan salah satu metode non destruktif dalam evaluasi mutu beton. Indikator estimasi kematangan beton adalah Maturity Index. Standardiasai estimasi tercantum dalam ASTM C1074. Konsep pengestimasian didasari oleh histrori suhu internal akibat panas hidrasi, kuat tekan beton, dan umur beton (Lim et al., 2018). Untuk memperoleh Maturity Index, data parameter yang didapatkan diinputkan dalam persamaan (1), sebagai berikut.

M(t)=∑ (T_a -T_0 )∆t (Persamaan 1)

Dimana, M(t) adalah total temperature-time factor pada umur tertentu (t), Δt adalah interval waktu dalam hari atau jam, Ta adalah rata-rata suhu internal sample beton, T0 adalah suhu terendah dari total histori pengukuran suhu. Estimasi umur equivalen dari beton terhadap Maturity Index memenuhi persamaan (2), berikut.

t_e =∑ e^(-Q(1/(Ta) - 1/(Ts))) ∆t (Persamaan 2)

Dimana, te adalah umur equivalen pada suhu spesifik Ts dalam hari atau jam, Q adalah rasio energi aktivasi terhadap konstanta gas K, Ta adalah rata-rata suhu internal sample beton selama Δt, Δt adalah interval waktu dalam hari atau jam, Ts adalah suhu spesifik. Pada suhu spesifik 20º C (293 K), nilai Q adalah 4700 K (ASTM, 2004).

## 2.3 Review Pemodelan Alat

Pengukuran dan monitoring suhu dan susut akibat hidrasi umumnya menggunakan data logger, sensor suhu dan pengukur displacement yang dihasilkan tiap waktu yang ditetapkan. Data yang tersimpan diakusisi oleh data logger menuju komputer. Sensor suhu yang digunakan adalah thermocouple. Thermocouple memilki berbagai macam tipe. Setiap tipe memiliki kriteria kapasitas berbeda. Sedangkan, pengukuran susut yang ada saat ini menggunakan LVDT, dilatometer, dan strain gauge (Holt, 2001; Springenschmid, 2004).

Suhu dan susut diukur dan dimonitor pada waktu bersamaan karena kejadian peningkatan suhu bersamaan dengan penyusutan (Januarti, 2008). Menurut (Januarti, 2008), batasan yang diberikan adalah mekanisme autogenous shrinkage dengan parameter kelembaban relative, suhu internal, dan susut. Sedangkan menurut (Kim et al., 2009), batasan yang diberikan adalah penentuan autogenous shrinkage akibat panas hidrasi pada beton kuat tinggi (High Strength Concrete) dengan parameter ukur susut, suhu internal, dan koreksi terhadap indeks kematangan. Akusisi dengan data logger dari kedua metode pengukuran tersebut, menyebabkan data yang tersimpan rawan hilang. Oleh karena itu, berdasarkan (Lim et al., 2018), akusisi data menggunakan sistem Internet of Things (IoT) dengan batasan untuk memonitor suhu internal beton sebagai parameter indeks kematangan beton (Maturity Index).

## 2.4 Sistem Akusisi Data Berbasis Wireless

Sistem akuisisi data adalah suatu sistem untuk mengambil, mengumpulkan dan menyiapkan data, sampai memprosesnya untuk menghasilkan data yang dikehendaki. Sistem akuisisi data merupakan sistem intrumentasi elektronik terdiri dari sejumlah elemen yang secara bersama – sama bertujuan melakukan pengukuram, penyimpanan, dan mengolah hasil pengukuran.

Proses pengambilan data umumnya dilakukan oleh operator dengan cara yang manual. Pengambilan data secara manual memiliki kelemahan diantaranya waktu yang diperlukan untuk pencatatan data, tingkat akurasi data yang rendah akibat human error, dan proses penyimpanan datayang tidak praktis. Sistem akuisisi data dapat dilakukan dengan mengolah data analog dan data digital. Pengiriman data secara digital dapat menggunakan komputer atau mikrokontroller dengan memanfaatkan jaringan nirkabel (wireless) dengan komunikasi MQTT. Jaringan internet yang digunakan sangat berpengaruh pada proses pengiriman data. Pada penelitian ini hasil dari pembacaan sensor dikirimkan ke database menggunakan mikrokontroller dengan komunikasi MQTT.

## 2.5 Mikrokontroller ESP32

ESP32 adalah mikrokontroler yang terintegrasi dengan modul Wi-Fi dan Bluetooth. Selain itu ESP32 juga sudah terintegrasi dengan built-in antenna switches, RF balun, power amplifier, low noise receives amplifier, filters, and power management modules. sehingga sangat mendukung untuk membuat sistem aplikasi Internet of Things. ESP 32 mempunyai memori RAM sebesar 320KB dan ROM sebesar 448 KB. ESP32 memiliki antarmuka peripheral antara lain 34 pin GPIO (General Purpose Input/Output), 18 pin ADC (Analog Digital Converter), 2 pin DAC (Digital Analog Converter), 16 pin PWM (Pulse Width Modulation), 10 pin capasitive sensing, 2 jalur antarmuka UART, pin antarmuka I2C, I2S, SPI, dll. Setiap pinout ESP 32 dapat menerima atau memberi tegangan hingga sebesar 3,3V (Espressif Systems, 2021). Bentuk mikrokontroller ditunjukkan, sebagai berikut.

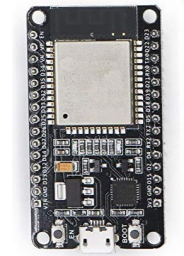
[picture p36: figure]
P132#yIS1

Gambar 2. 2 Model Mikrokontroller ESP32 (Espressif Systems, 2021)

## 2.6 Sensor Temperatur

Termokopel merupakan salah satu dari jenis sensor suhu. Sensor ini terdiri dari dua kawat logam konduktor yang berbeda jenis dan ujungnya digabungkan menjadi satu. Dua kawat memiliki fungsi yang berbeda. Salah satu kawat berfungsi sebagai titik ukur/titik panas. Sedangkan, yang lain sebagai titik referensi, yang mana temperaturnya konstan.

Beberapa sensor suhu yang digunakan dalam pengukuran suhu pada beton adalah Termokopel Tipe T, dan K. Sensor dapat membaca perubahan suhu ketika titik referensi dan ukur terdapat perbedaan suhu yang menimbulkan GGL sehingga menghasilkan arus pada rangkaian. Rangkaian yang terhubung pada sebuah alat pencatat akan mendefinisikan perubahan arus (Santoso & Ruslim, 2019).

## 2.7 Digital Caliper

Kaliper digital terdiri dari balok utama dan a penggeser, rak, dan roda gigi dipasang di balok utama dan penggeser masing-masing. Sistem roda gigi ini mengubah posisi linier pada sumbu-x pada balok utama ke posisi sudut ( θ + 2Nπ ), dan posisi sudut diukur dengan pengukuran kapasitif perangkat. Alat pengukur kapasitif posisi sudut diisolasi secara tertutup dari rak dan roda gigi dengan rongga segel dan anggota segel. Oleh karena itu, caliper dapat digunakan di bawah kondisi yang buruk. Invensi ini khususnya cocok untuk digunakan dalam bidang pekerjaan mekanik (Chen & You, 2010). Komponen kaliper digital disajikan pada ilustrasi, berikut.

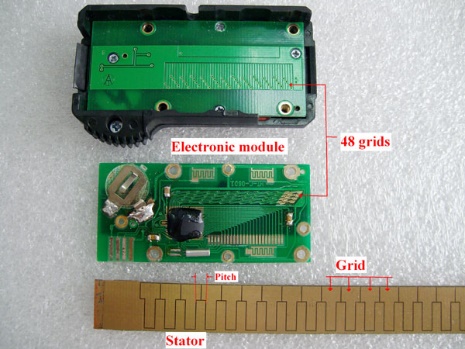
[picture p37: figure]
P139#yIS1

Gambar 2. 3 Model Kaliper Digital (Chen & You, 2010)

## BAB 3. TAHAP PELAKSANAAN

Pelaksanaan program in akan dilakukan secara luring dengan tetap mentaati protokol kesehatan. Pelaksanaan pembuatan prototype untuk pengujian panas hidrasi mengikuti beberapa tahapan yang telah dirancang dalam diagram alir gambar, berikut.

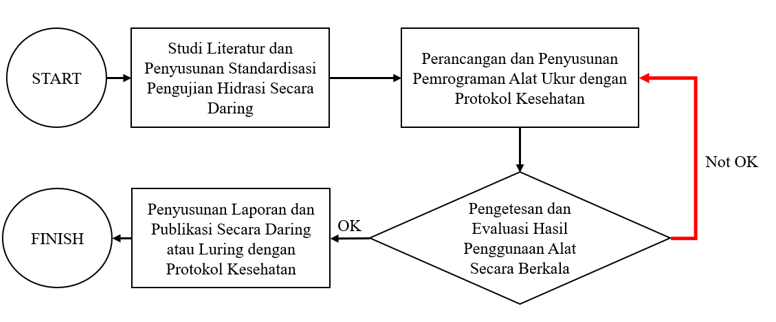
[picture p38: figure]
P143#yIS1

Gambar 3. 1 Skema Alur Pelaksanaan Pembuatan Prototype

## 3.1 Studi Literatur dan Penyusunan Standardisasi

Batasan studi literatur ditujukan untuk perancangan model alat pengujian suhu internal beton dan susut (Autogenous Shrinkage) dengan output pengukuran adalah indeks kematangan beton (Maturity Index). Selain, Pemodelan alat, penyusunan pemrograman berbasis IoT memerlukan standardisasi. Standardisasi mengacu pada design code, sebagai berikut.

Penyiapan Spesimen Uji

a. Mix design beton (ACI 211.1.91 dan SNI 03-3449-2002)
b. Uji konsistensi normal semen (ASTM C 187-16, SNI 03-6826-2002)
c. Uji setting time semen (ASTM C 191-3, SNI 15-2049-2004)
d. Uji saringan/lolos ayakan (ASTM C 117-95)
e. Uji slump (SNI 03-1972-1990)
f. Uji kuat tekan (SNI 03-1974-1990)

Prasyarat Standardisasi Alat

a. Uji suhu internal beton segar (ASTM C 1064)
b. Uji autogenous shrinkage (ASTM C 1698-09)
c. Estimasi kematangan beton (ASTM C 1074)

## 3.2 Perancangan Alat

Perancangan alat dibagi menjadi dua proses, yaitu proses Hardware dan software. Perancangan yang harus dilewati pertama adalah Hardware alat ukur berupa penyusunan komponen kelistrikan dan komponen mekanik alat ukur. Hardware yang telah jadi akan masuk proses software dalam bentuk pengolahan transfer data dan pengolahan data hingga menghasilkan output.

Komponen kelistrikan tersusun dari sensor yang terhubung dengan mikrokontroller ESP32. Sensor yang akan digunakan sebagai pengukur suhu perlu ditrial dahulu agar mendapatkan sensor paling optimal saat digunakan. Sensor suhu rencana yang akan ditrial adalah termokopel tipe T, tipe K, dan DS18B20. Pengukuran suhu dengan sensor yang telah ditentukan akan dilakukan bersamaan dengan pengukuran susut (Autogenous Shrinkage). Pengukuran susut dilakukan oleh kaliper digital sehingga kaliper digital juga akan terhubung dengan mikrokontroller ESP32.

Modifikasi kaliper digital juga akan masuk dalam proses perancangan mekanik alat ukut. Susut yang diukur kaliper digital berupa penurunan muka beton. Beton akan dicetak dalam cetakan persegi berukuran 15 cm x 15 cm x 15 cm. Cetakan beton akan diberi styrofoam untuk mengisolasi panas hidrasi beton. Kaliper digital akan menempel pada cetakan agar pengukuran stabil. Perancangan mekanik alat diilustrasikan dalam gambar, berikut.

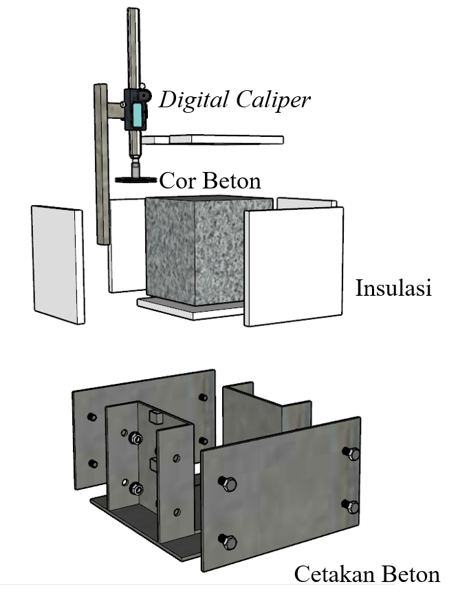
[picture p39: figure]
P162#yIS1

Gambar 3. 2 Pemodelan Alat Ukur Autogenous Shrinkage

Proses perancangan software direncanakan sesuai skema kerja alat disajikan pada gambar, berikut.

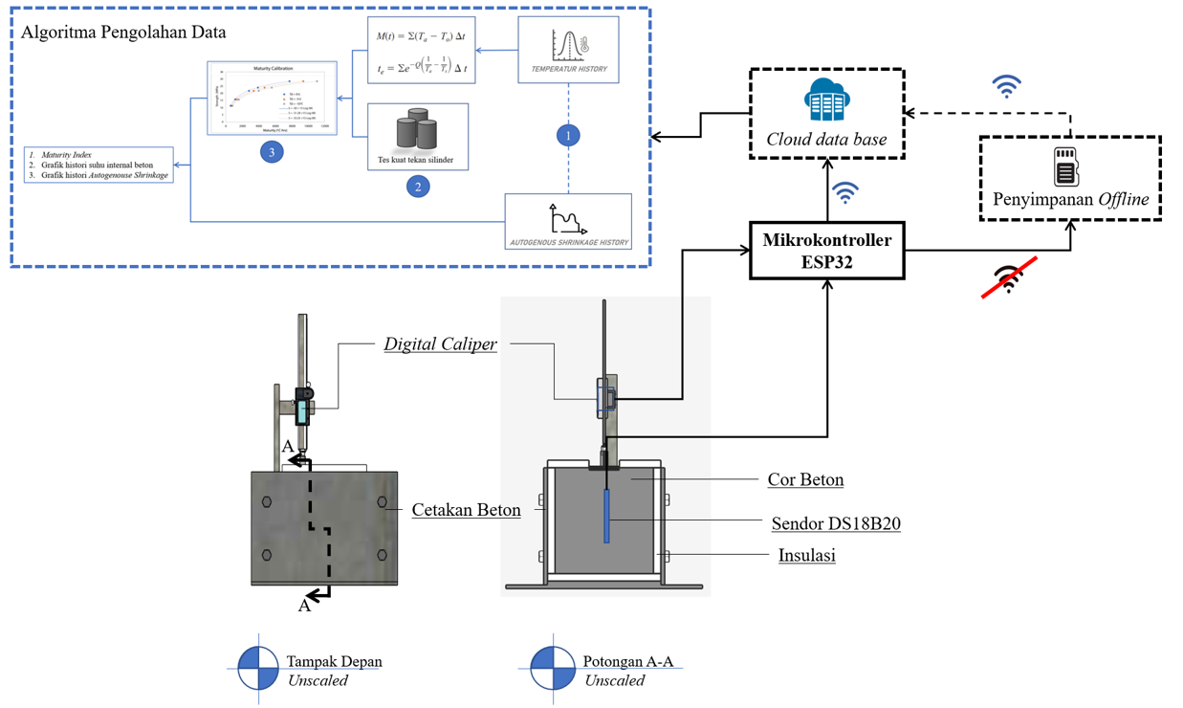
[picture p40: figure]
P165#yIS1

Gambar 3. 3 Skema Pemodelan Alat Ukur

Mikrokontroller akan diprogram agar data inputan dari sensor dan kaliper digital disimpan dalam penyimpanan internal. Data dapat ditransfer menuju cloud data base saat tersedia jaringan internet yang terhubung dengan mikrokontroller. Transfer dapat dibuat menjadi dua opsi yaitu transfer otomatis atau memerlukan perintah pengguna. Data yang telah ditransfer menuju data base akan diolah dengan algoritma pemrograman dalam website (Lampiran 5) menjadi dua output yaitu grafik suhu versus susut serta visualisasi dari tingkat kematangan beton berdasarkan hubungan kuat tekan beton dan hasil pengukuran suhu beton. Suhu beton akan diolah dengan persamaan 1 dan persamaan 2 sehingga menghasilkan output equivalensi hari terhadap suhu beton. Grafik dan hasil regresi dari equivalensi hari terhadap suhu beton dan kuat tekan beton menghasilkan nilai Maturity Indeks. Nilai inilah yang menjelaskan pengaruh suhu hidrasi terhadap mutu beton seiring bertambahnya umur beton.

## 3.3 Pengetesan dan Evaluasi Alat

Pengetesan dan evaluasi pengujian digunakan untuk meningkatkan kinerja dari prototype yang telah dibuat. Proses ini digunakan untuk mengukur variabel akurasi pengukuran alat terhadap penyusutan dan suhu internal beton sesuai standardisasi.

## 3.4 Penyusunan Laporan

Pembuatan laporan dilakukan terprogress dan direkap saat seluruh tahapan selesai sehingga hasil pelaksanaan dapat dikaji dan dibuktikan keasliannya.

## BAB 4. BIAYA DAN JADWAL KEGIATAN

## 4.1 Anggaran Biaya

Berikut kami sajikan rekapitulasi rencana anggaran biaya:

Tabel 4. 1 Rekapitulasi Rencana Anggaran Biaya

No. | Jenis Pengeluaran | Sumber Dana | Besaran Dana (Rp)
1. | Bahan habis pakai | Belmawa | Rp 3.279.000
| | Perguruan Tinggi | Rp 1.093.000
| | Instansi Lain | Rp 0
2. | Sewa dan jasa | Belmawa | Rp 351.000
| | Perguruan Tinggi | Rp 117.000
| | Instansi Lain | Rp 0
3. | Transportasi lokal | Belmawa | Rp 300.000
| | Perguruan Tinggi | Rp 100.000
| | Instansi Lain | Rp 0
4. | Lain-lain | Belmawa | Rp 1.282.500
| | Perguruan Tinggi | Rp 427.500
| | Instansi Lain | Rp 0
Jumlah | | | Rp 6.950.000
Rekap Sumber Dana | | Belmawa | Rp 5.212.500
| | Perguruan Tinggi | Rp 1.737.500
| | Instansi Lain | Rp 0
| | Jumlah | Rp 6.950.000

## 4.2 Jadwal Kegiatan

Adapun jadwal kegiatan dari program ini dapat dilihat pada table berikut:

Tabel 4. 2 Format Jadwal Kegiatan

No | Kegiatan | Bulan | | | | | | | | | | | | | | | | Penanggung jawab
| | 1 | | | | 2 | | | | 3 | | | | 4
1 | Studi Literatur dan Penyusunan Standardisasi. | | | | | | | | | | | | | | | | | Ahmad Dzikrullah Akbar
2 | Perancangan Alat. | | | | | | | | | | | | | | | | | M. Faris Zuhairi
3 | Pengetesan dan Evaluasi Alat | | | | | | | | | | | | | | | | | Hakhi Gya Yektianto
4 | Penyusunan Laporan dan Publikasi | | | | | | | | | | | | | | | | | M. Alfiyan Zulfa

## DAFTAR PUSTAKA

American Concrete Institute (ACI). (2008). Aci 207.2R-07. In Journal of American Concrete Institute: Vol. C.

Amshar, Tjaronge, M. W., Djamaluddin, R., & Amiruddin, A. A. (2018). Panas Hidrasi Beton Massa yang Menggunakan Semen Portland Komposit. Invensi, Inovasi Dan Riset Keselamatan Dan Kesehatan Kerja Untuk Pembangunan Infrastruktur Berkelanjutan, 21–30. https://knpts.ftsl.itb.ac.id/wp-content/uploads/2019/04/28.-PANAS-HIDRASI-BETON-MASSA-YANG-MENGGUNAKAN-SEMEN.pdf

ASTM. (2004). Estimating Concrete Strength by the Maturity Method 1. ASTM C 1074-04. 1–9.

Astm C1064/C1064M-04. (2004). Standard Test Method for Temperature of Freshly Mixed Hydraulic-Cement Concrete. Annual Book of ASTM Standards, c, 4–6. https://doi.org/10.1520/C1064

Awal, A. S. M. A., & Hussin, M. W. (2010). Influence of palm oil fuel ash in reducing heat of hydration of concrete. In Journal of Civil Engineering (IEB) (Vol. 38, Issue 2, pp. 153–157).

Chen, S., & You, N. (2010). (12) United States Patent. 1(12).

Espressif Systems. (2021). ESP32 Series Datasheet. Espressif Systems, 1–65.

Gowripalan, N. (2020). Autogenous Shrinkage of Concrete at Early Ages. Lecture Notes in Civil Engineering, 37(December), 269–276. https://doi.org/10.1007/978-981-13-7603-0_27

Holt, E. E. (2001). Early age autogenous shrinkage of concrete. VTT Publications, 446, 2–184.

Januarti, J. E. (2008). EXPERIMENTAL STUDY ON MECHANISM OF AUTOGENEOUS SHRINKAGE OF DIFFERENT TYPE OF SLAG CEMENT. PONDASI, 14.

Kim, G., Lee, E., & Koo, K. (2009). Hydration Heat and Autogenous Shrinkage of High-Strength Mass Concrete. Journal of Asian Architecture and Building Engineering, 8(2), 509–516. https://doi.org/10.3130/jaabe.8.509

Lim, J. S., Cruz, H., Pourhomayoun, M., & Mazari, M. (2018). Application of IoT for concrete structural health monitoring. Proceedings - 2018 International Conference on Computational Science and Computational Intelligence, CSCI 2018, 1479–1482. https://doi.org/10.1109/CSCI46756.2018.00295

Lu, T., Li, Z., & van Breugel, K. (2020). Modelling of autogenous shrinkage of hardening cement paste. Construction and Building Materials, 264, 120708. https://doi.org/10.1016/j.conbuildmat.2020.120708

Nugraha, P., & Antoni. (2007). Teknologi Beton Dari Material, Pembuatan, ke Beton Kinerja Tinggi (First). Andi.

Santoso, H., & Ruslim, R. (2019). Pembuatan Termokopel Berbahan Nikel (Ni) dan Tembaga (Cu) Sebagai Sensor Temperatur. Indonesian Journal of Fundamental Sciences, 5(1), 59. https://doi.org/10.26858/ijfs.v5i1.9376

Springenschmid, R. (2004). Prevention of Thermal Cracking in Concrete at Early Ages (Issue July). CRC Press. https://doi.org/10.1201/9781482271812

Taizawa, E. C. (2003). Autogenous Shrinkage of Concrete. Routledge. https://doi.org/10.4324/9780203223222

## LAMPIRAN

## Lampiran 1. Biodata Ketua dan Anggota serta Dosen Pendamping

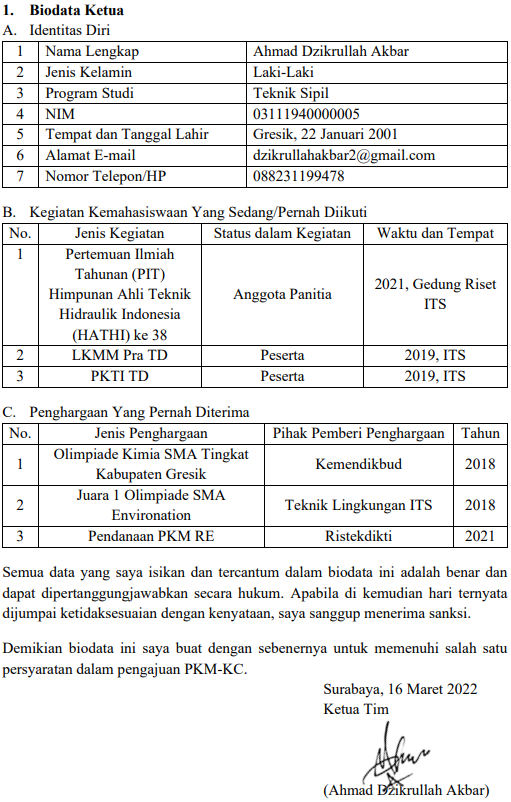
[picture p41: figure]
P376#yIS1

2. Biodata Anggota 1

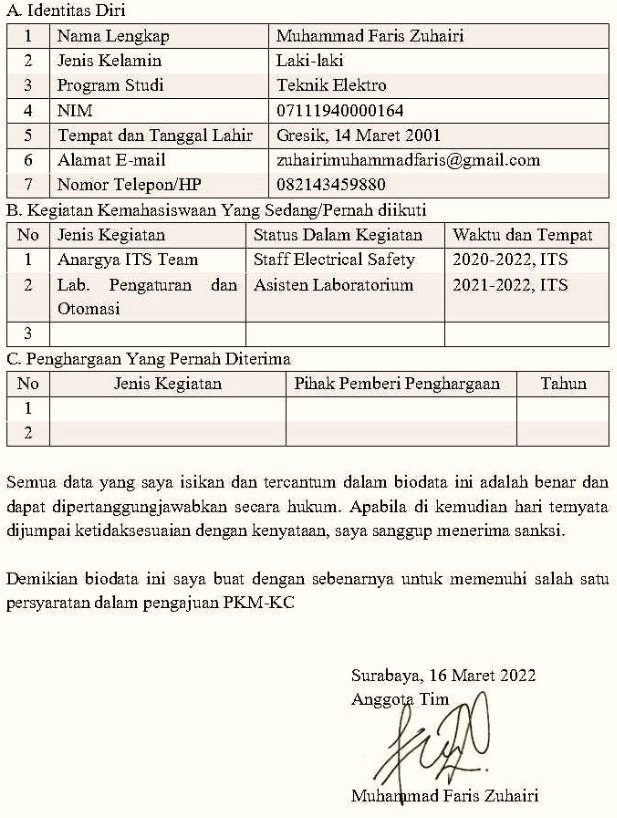
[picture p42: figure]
P379#yIS1

3. Biodata Anggota 2

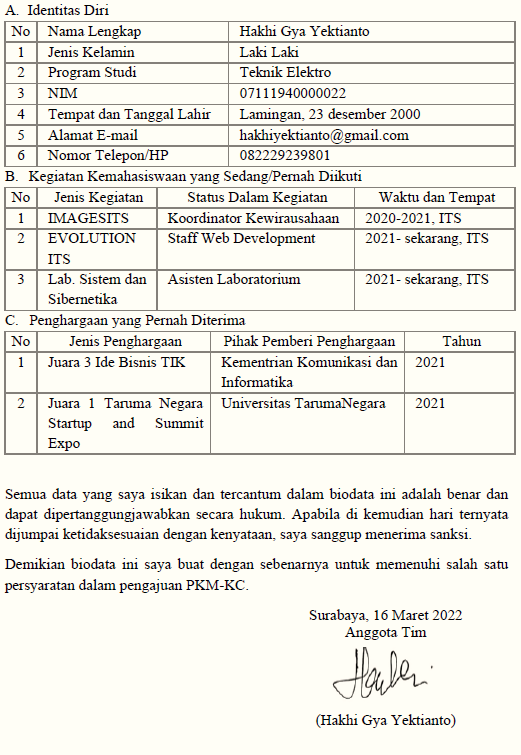
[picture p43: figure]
P382#yIS1
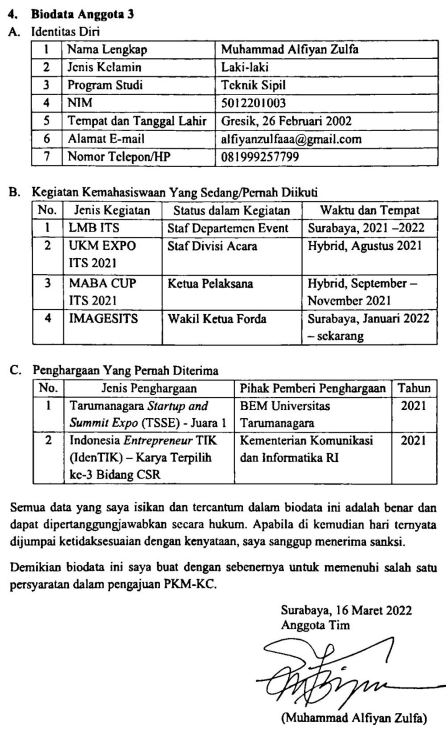
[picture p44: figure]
P383#yIS1
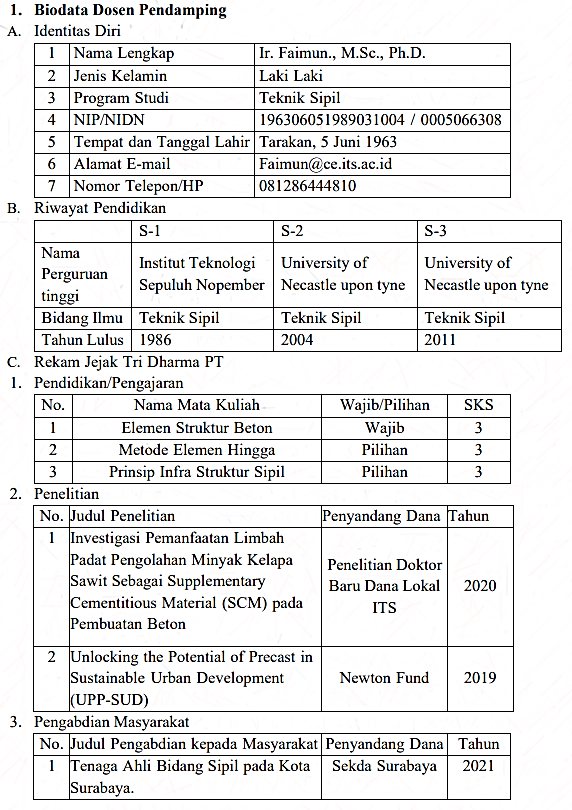
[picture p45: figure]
P384#yIS1
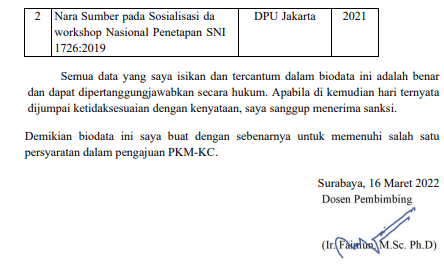
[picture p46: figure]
P385#yIS1

## Lampiran 2. Justifikasi Anggaran Kegiatan

No. | Jenis Pengeluaran | Volume | Harga Satuan (Rp) | Nilai (Rp)
1 | Barang Habis Pakai
| Mikrokontroller ESP32 devkit v4 | 2 unit | Rp. 80.000 | Rp. 160.000
| Digital caliper 1 | 1 unit | Rp. 975.000 | Rp. 975.000
| Digital caliper 2 | 1 unit | Rp. 975.000 | Rp. 975.000
| Breadboard | 1 unit | Rp. 32.000 | Rp. 32.000
| Kabel jumper | 2 paket | Rp. 15.000 | Rp. 30.000
| Adaptor 12v 1A | 1 unit | Rp. 20.500 | Rp. 34.000
| DC stepdown (lm 2596) | 1 unit | Rp. 12.000 | Rp. 12.000
| Termokopel tipe K | 3 unit | Rp. 30.000 | Rp. 90.000
| Komponen elektronik lain | 1 paket | Rp. 100.000 | Rp. 100.000
| Konektor (molex, pinheader, mur, baut, dll) | 1 paket | Rp. 50.000 | Rp. 50.000
| Pasir | 0.25 kol | Rp. 280.000 | Rp. 70.000
| Batu kerikil | 0.25 kol | Rp. 290.000 | Rp. 72.500
| Cetakan Betonz | 1 unit | Rp. 600.000 | Rp. 600.000
| Cetakan Beton A | 1 unit | Rp. 600.000 | Rp. 600.000
| Semen OPC | 2 sak | Rp. 50.000 | Rp. 100.000
| Styrofoam tebal 1 cm 100 x 50 | 5 lembar | Rp. 20.000 | Rp. 100.000
| Acrylic case ESP32 | 1 unit | Rp. 35.000 | Rp. 35.000
| Timah | 1 unit | Rp. 44.000 | Rp. 44.000
| Solder | 1 unit | Rp. 70.000 | Rp. 70.000
| Peralatan K3 | 4 paket | Rp. 50.000 | Rp. 200.000
| Kabel 3p | 5 meter | Rp. 6.000 | Rp. 30.000
SUB TOTAL | | | | Rp 4.372.000
2 | Belanja Sewa dan Jasa
| Sewa hosting | 6 bulan | Rp. 50.000 | Rp. 300.000
| Sewa domain web | 1 tahun | Rp. 168.000 | Rp. 168.000
SUB TOTAL | | | | Rp 468.000
3 | Transportasi Lokal
| Transport lokal (untuk keperluan pembelian bahan dan uji coba) | 4 | Rp. 100.000 | Rp. 400.000
SUB TOTAL | | | | Rp 400.000
4 | Lain-lain
| Print administrasi | 100 | Rp. 500 | Rp. 50.000
| Jasa cetak PCB | 1 unit | Rp. 200.000 | Rp. 200.000
| Alat tulis kantor | 4 | Rp. 30.000 | Rp. 120.000
| Perlengkapan protokol kesehatan | 4 | Rp. 80.000 | Rp. 320.000
| Publikasi jurnal | 1 | Rp. 1.000.000 | Rp. 1.000.000
| Materai | 2 | Rp. 10.000 | Rp. 20.000
SUB TOTAL | | | | Rp 1.710.000
GRAND TOTAL | | | | Rp 6.950.000

GRAND TOTAL (Enam Juta Sembilan Ratus Lima Puluh Ribu Rupiah)

## Lampiran 3. Susunan Organisasi Tim Penyusun dan Pembagian Tugas

No. | Nama/NIM | Program Studi | Bidang Ilmu | Alokasi Waktu (jam/ minggu) | Uraian Tugas
1 | Ahmad Dzikrullah Akbar/03111940000005 | S1 - Teknik Sipil | Teknologi Bahan Bangunan | 12 jam/minggu | Pengetesan Alat dan Penyusunan Alur Perhitungan
2 | M. Faris Zuhairi/07111940000 | S1 - Teknik Elektro | Teknik Sistem Pengaturan | 12 jam/minggu | Perancangan Hardware
3 | Hakhi Gya Yektianto/ 07111940000022 | S1 - Teknik Elektro | Teknik Sistem Pengaturan | 12 jam/minggu | Integrasi Hardware dan Software
4 | Muhammad Alfiyan Zulfa/5012201003 | S1 - Teknik Sipil | Teknologi Bahan Bangunan | 12 jam/minggu | Penyusunan Laporan dan Publikasi

## Lampiran 4. Surat Pernyataan Ketua Pelaksana

P656#yIS1

## Lampiran 5. Gambaran Teknologi yang akan Dikembangkan

Modifikasi digital kaliper secara mekanik dilakukan sesuai Gambar A sehingga mampu mengukur perubahan susut pada muka beton. Digital kaliper juga dimodifikasi agar dapat tersambung dengan rangkaian mikrokontroler sehingga hasil dari pengukuran dapat terekam dan terintegrasi bersamaan dengan pengukuran suhu. Ilustrasi Skema modifikasi digital kaliper dijelaskan sebagai, berikut.

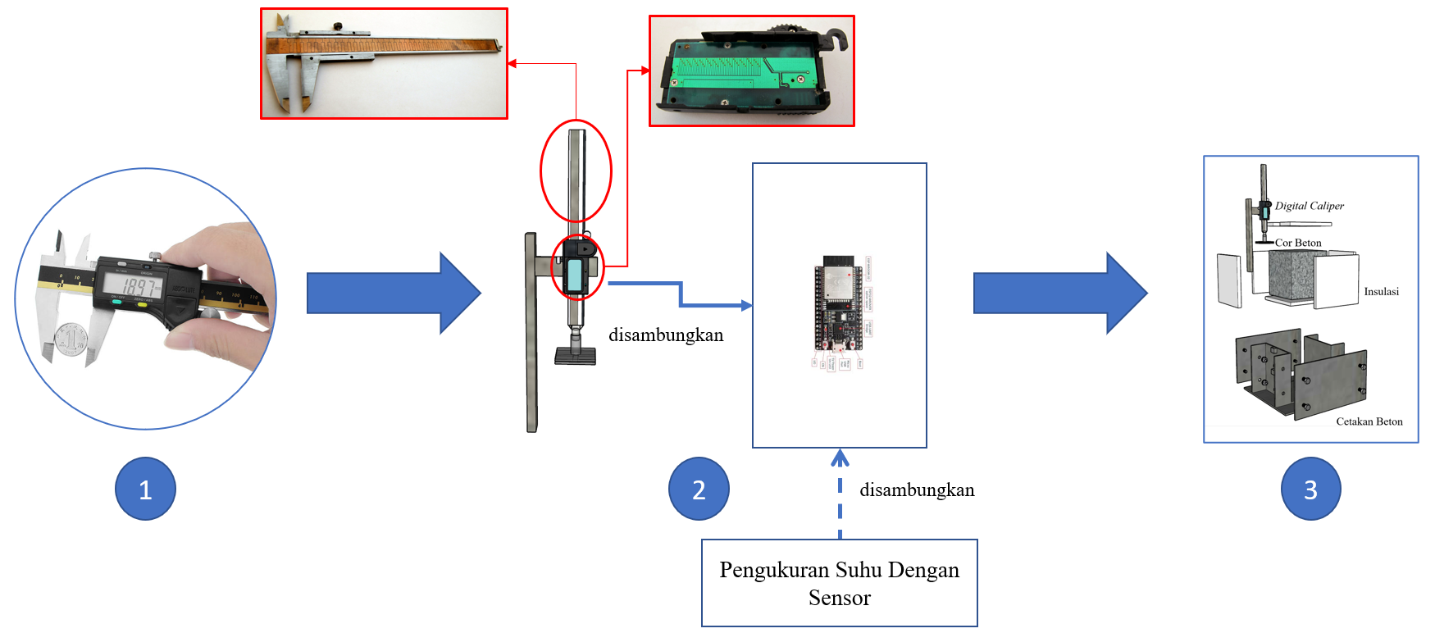
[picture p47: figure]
P663#yIS1

Gambar A Skema Modifikasi Digital Kaliper

Note : “Sensor suhu yang akan digunakan akan dievaluasi dengan membandingkan antar jenis sensor. Sensor yang dibandingkan adalah Termokopel tipe T, Tipe K, dan DS18B20.”

Sistem pengukuran dirancang agar dapat melakukan sinkronisasi dengan cloud data base secara otomatis atau dengan kendali pengguna saat terdapat jaringan internet. Saat alat tidak tersinkronisasi, maka data akan disimpan dalam penyimpanan internal dan akan dapat disinkronkan apabila terdapat jaringan internet. Otomasi sinkronisasi tersebut diolah oleh pemrograman yang diinputkan dalam mikrokontroler. Data yang diupload oleh mikrokontroler akan diolah lagi pada lanjutan simbol A sesuai ilustrasi, berikut.

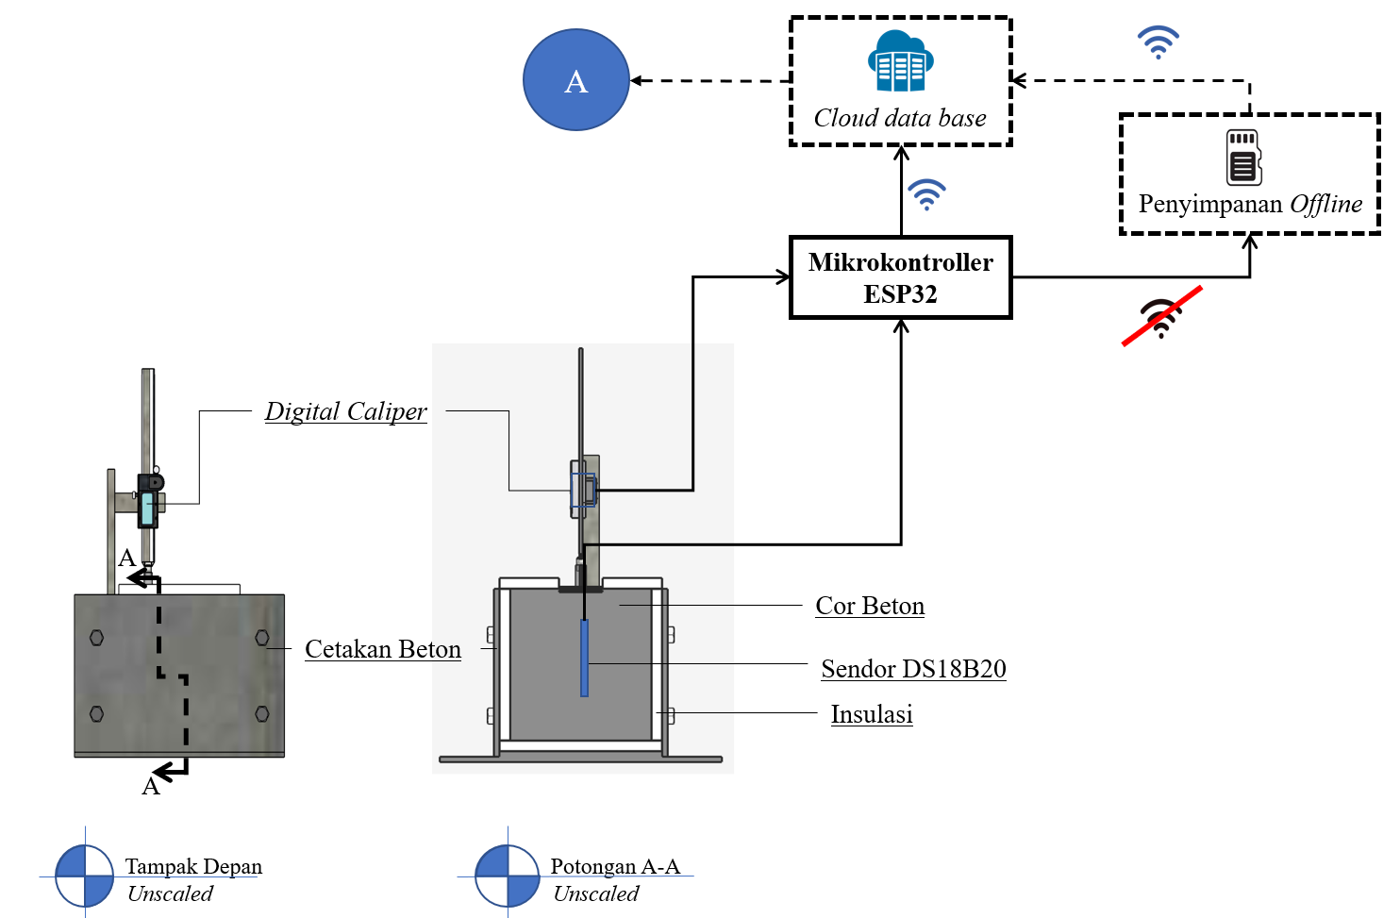
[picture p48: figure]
P667#yIS1

Gambar B Sistem Sinkronisasi Alat dengan Data Base

Sistem pengukuran Lanjutan pada simbol A merupakan algoritma program yang di masukkan dalam cloud data base. Algoritma tersebut disusun sesuai pada gambar dibawah, ini.

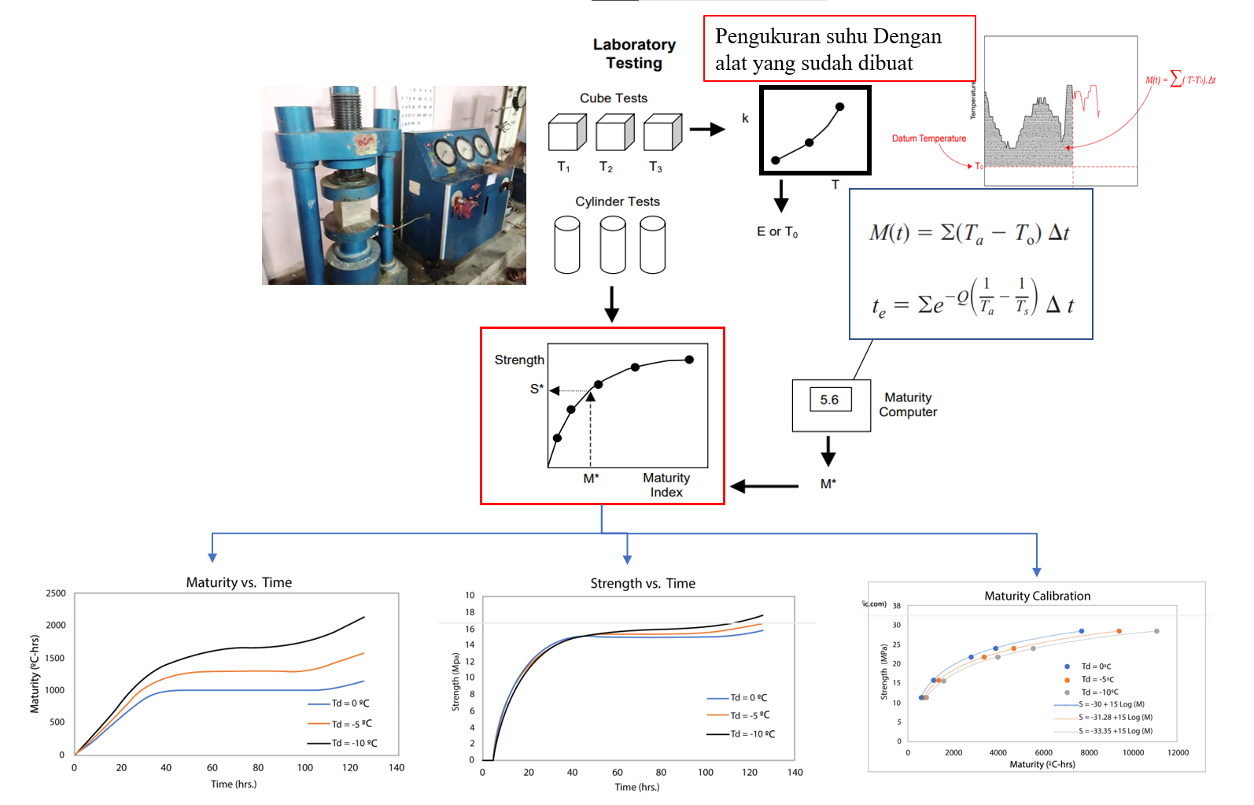
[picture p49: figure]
P670#yIS1

Gambar C Skema Pengolahan Data Input Menjadi Output

Output ditampilkan dalam website dengan tampilan yang disajikan pada gambar, berikut.

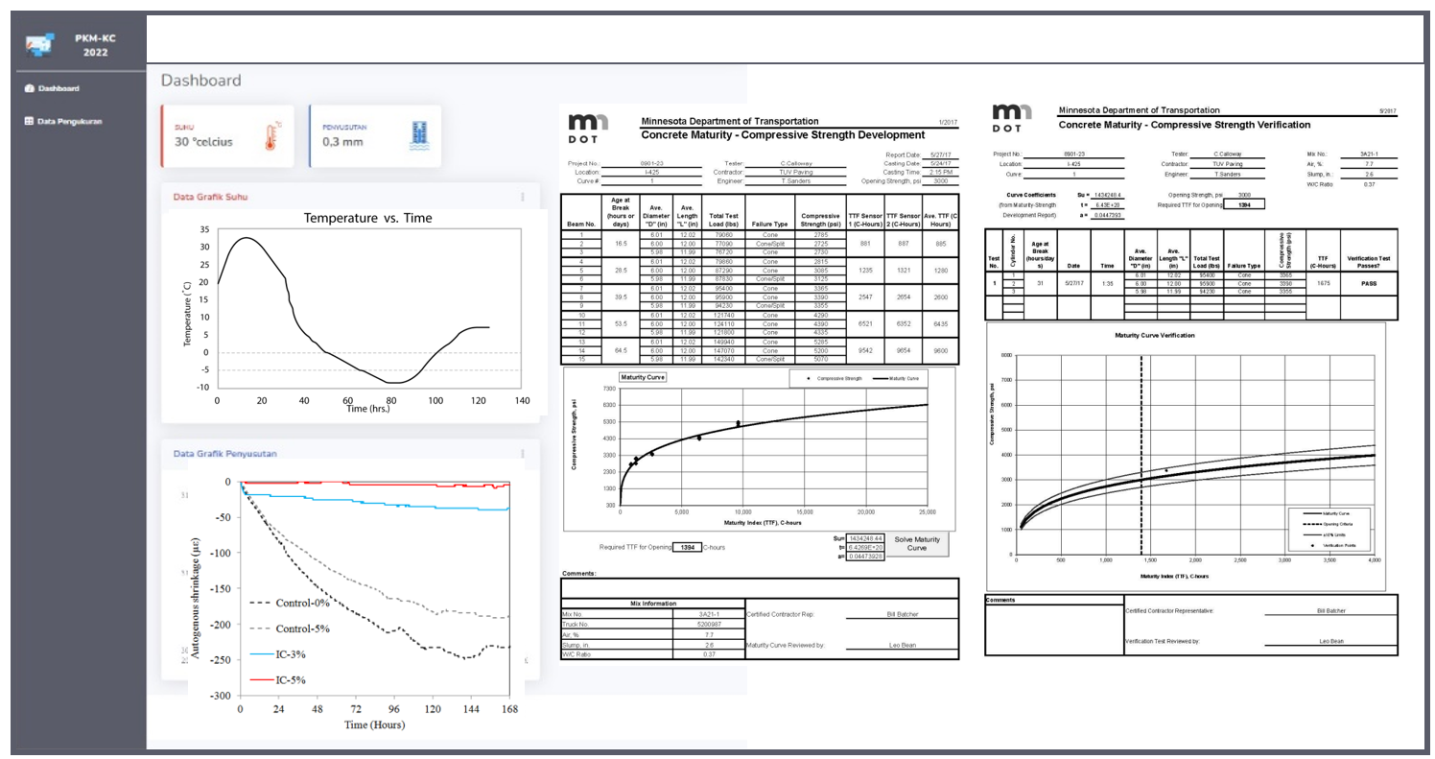
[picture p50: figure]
P673#yIS1

Gambar D Tampilan Antarmuka Output Pemrograman dan Pengukuran

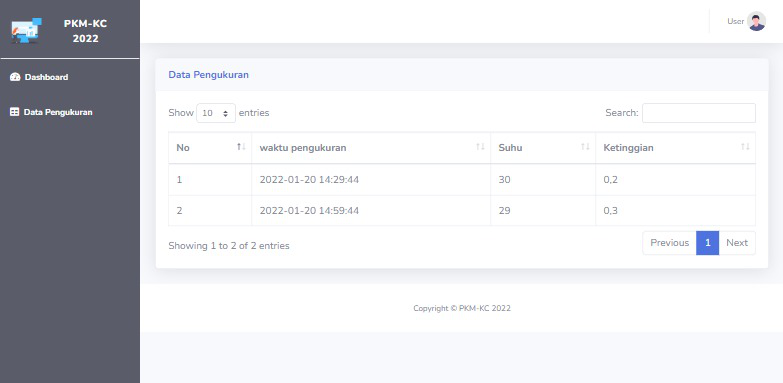
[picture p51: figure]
P675#yIS1

Gambar E Tampilan Antarmuka Riwayat Pengukuran

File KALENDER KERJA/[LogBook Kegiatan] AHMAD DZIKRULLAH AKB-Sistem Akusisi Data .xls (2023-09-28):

Tanggal Pelaksanaan | Kegiatan Yg Dilakukan | Persentase Capaian | Menit Pelaksanaan | Status Validasi Dosen | Berkas Catatan Harian
01/06/2022 | Pertemuan pertama kali setelah pengumuman Pendanaan PKM 2022, dilakukan secara online melalui google meet. Dilakukan pembahasan terkait work breakdown structure dan rencana timeline dari kegiatan pelaksanaan PKM. | 2 | 120 | Disetujui | Ada
15/06/2022 | Identifikasi dan uji coba Jangka Sorong Digital oleh penanggung jawab teknis setelah dilakukan pembelian alat di hari sebelumnya. | 6 | 180 | Disetujui | Ada
24/06/2022 | Melanjutkan penyusunan dan fiksasi kegiatan PKM KC beserta timelinenya menggunakan software Ms. Project agar lebih detail terkait jam dan hari kerjanya. Kemudian dilanjutkan ddengan membahas/melakukan studi literatur untuk menentukan standard yang digunakan dalam sistem akuisisi ini dan bahan acuan untuk menyusun latar belakang pada laporan. | 10 | 120 | Disetujui | Ada
01/07/2022 | Penyusunan Bab 1 (Rumusan Masalah, Tujuan, Luaran dan Manfaat) dari laporan kemajuan PKM KC, Sistem Akuisisi Data Berbasis Wireless Untuk Evaluasi Efek Panas HIdrasi Beton Pada Umur Awal | 14 | 240 | Disetujui | Ada
02/07/2022 | Kegiatan SON 1 oleh tim KSN ITS kepada setiap tim pendanaan PKM, topik pembahasannya adalah progres laporan kemajuan utamanya untuk formatingnya, mulai dari BAB 1, 2, 3,4 dan lampiran. Serta mengasistensikan kendala yang dialami oleh tim. | 15 | 30 | Disetujui | Ada
04/07/2022 | Simulasi pembacaan caliper, simulasi ini berjalan lancar dan berhasil dibaca oleh sistem. Setelah ini akan dilakukan pembuatan casing dan integrasi dengan ESP. | 16 | 90 | Disetujui | Ada
07/07/2022 | Pendesainan cetakan beton khusus beserta box control dan komponen elektronik lainnya pada existing cetakan beton. Dari desain ini diperlukan modifikasi dan beberapa penyesuaian pada cetakan beton sehingga didapat desain dan posisi masing masing komponen yang baik. | 25 | 240 | Disetujui | Ada
07/07/2022 | Diskusi dan finalisasi terkait algoritma untuk memprediksi susut dan mutu beton uji dengan referensi persamaan/rumus maturity beton untuk diaplikasikan pada pemrograman web. | 20 | 120 | Disetujui | Ada
07/07/2022 | Dilakukan proses perancangan program web dari algoritma yang telah didapatkan sebelumnya, perancangan ini difokuskan untuk dapat mengeluarkan output prediksi mutu beton pada umur tertentu sekaligus perancangan menu-menu pada web. | 28 | 90 | Disetujui | Ada
11/07/2022 | Modifikasi cetakan beton yang sudah ada sesuai dengan desain yang sebelumnya dibuat, modikasi disini adalah memotong beberapa bagian dari plat besi untuk dijadika tempat komponen yang lain. | 30 | 90 | Disetujui | Ada
14/07/2022 | Mendesain UI website dari sistem akuisisi data, yang mana pada proses pendesainan dilakukan penataan tampilan dashboard, prediksi mutu beton serta data pengukuran. Desainpun dilakukan dengan memperhatikan aspek estetika dan kesederhanaan dalam pembacaan data oleh pengguna alat. Posisi-posisi data, tombol dan menu lainnya harus sederhana agar mudah dipahami dan diakses. | 32 | 150 | Disetujui | Ada
15/07/2022 | Menyusun kebutuhan informasi dan data yang akan digunakan pada database website, serta dilakukan pendesainan database ketika data dan informasi yang dibutuhkan sudah tersedia. | 34 | 120 | Disetujui | Ada
16/07/2022 | Melakukan pembuatan script program sesuai dengan desain yang telah dibuat dan teknologi yang telah ditentukan pada proses/tahapan sebelumnya. | 36 | 120 | Disetujui | Ada
17/07/2022 | Melanjutkan tahap development website dengan meanjutkan pembuatan script sekaligus recheck terhadap script yang telah dibuat. | 38 | 120 | Disetujui | Ada
23/07/2022 | Melakukan pengujian website yang telah dibuat dengan memeriksa script, formulir, ataupun aspek lainnya apakah terdapat kesalahan pengetikan atau kesalahan aturan bahasa yang digunakan. Pengujian ini dilakukan untuk mengetahui sekaligus memastikan bahwa seluruh fitur website sudah/akan berjalan dengan baik. | 39 | 90 | Disetujui | Ada
24/07/2022 | Setelah dilakukan pengujian, dan didapati adanya kesalahan pengetikan/bahasa yang digunakan, maka dilakukan revisi pada script. Hal ini bertujuan agar fitur pada website dapat berjalan dengan baik. | 40 | 60 | Disetujui | Ada
29/07/2022 | Melanjutkan pengerjaan laporan kemajuan, dengan menambahkan isi pada bagian Bab 3, 4, 5 dan 6. Sekaligus memastikan konten apa saja yang harus ada pada bagian lampiran. | 42 | 120 | Disetujui | Ada
31/07/2022 | Melakukan tahap deployment, yang merupakan tahap terakhir dalam pembuatan website. Pada tahap ini dilakukan publikasi web yang telah dibuat ke Internet, agar dapat diakses oleh user. | 45 | 120 | Disetujui | Ada
05/08/2022 | Membuat rangka caliper dan thermocouple yang dipasang/direkatkan pada cetakan beton, rangka dibuat dari bahan akrilik dengan tebal 2 mm. | 48 | 120 | Disetujui | Ada
06/08/2022 | Pemasangan thermocouple dan modulnya pada komponen yang telah di-assembly-kan sebelumnya, sekaligus melakukan modifikasi box control sebagai housing dari komponen. Modifikasi meliputi melubangan beberapa bagian untuk penembpatan baut, kabel, button, dll. | 55 | 150 | Disetujui | Ada
06/08/2022 | Dilakukan modifikasi kembali pada cetakan beton untuk memberikan ruang rangka akrilik, box control dan lubang lubat baut. | 60 | 90 | Disetujui | Ada
13/08/2022 | Kalibrasi thermocouple agar pembacaan suhu dapat sesuai dengan suhu real yang ada/terjadi dan pengujian website meliputi pengujian fitur, pengecekan ulang script sekaligus melakukan revisi apabila terdapat kesalahan | 75 | 180 | Disetujui | Ada
08/09/2022 | Menyelesaikan laporan kemajuan PKM KC dan memulai menyusun draft artikel ilmiah terkait ide sistem akuisisi ini. | 90 | 300 | Disetujui | Ada
26/09/2022 | Pengerjaan dan finalisasi laporan akhir PKM KC | 100 | 120 | Belum Diproses | Ada

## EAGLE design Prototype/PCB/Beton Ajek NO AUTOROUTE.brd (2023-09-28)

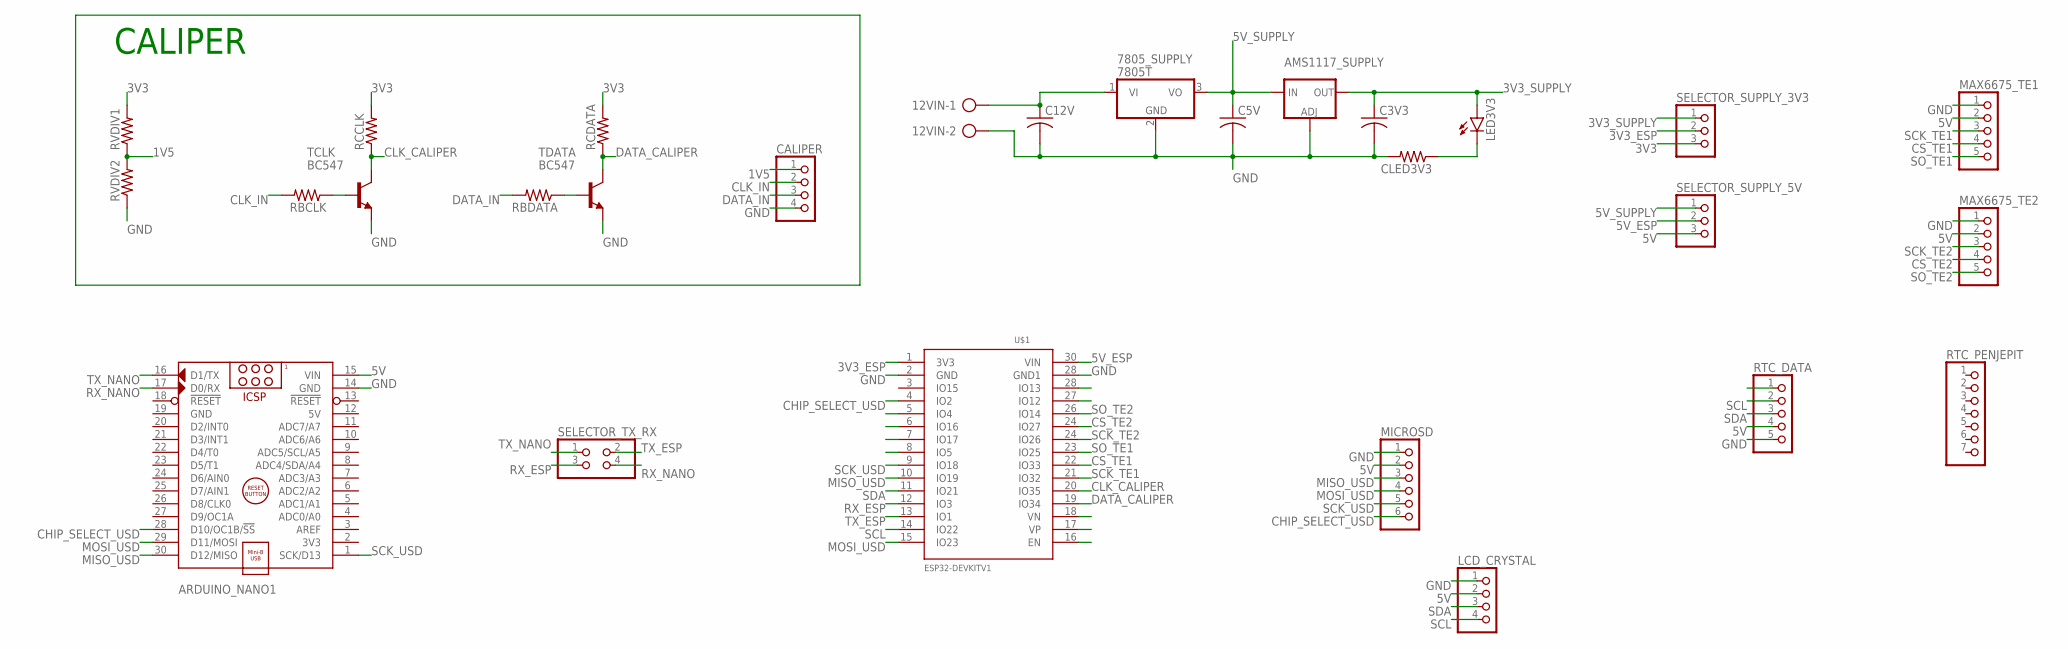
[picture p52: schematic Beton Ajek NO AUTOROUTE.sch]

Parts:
12VIN: AK300/2
7805_SUPPLY: 7805T; TO220H
AMS1117_SUPPLY: V_REG_LM1117SOT223; SOT223
ARDUINO_NANO1: ARDUINO_NANO
C3V3, C5V, C12V: C-US075-032X103; C075-032X103
CALIPER: PINHD-1X4; 1X04
CLED3V3: R-US_0207/10; 0207/10
LCD_CRYSTAL: PINHD-1X4; 1X04
LED3V3: LED5MM
MAX6675_TE1, MAX6675_TE2: PINHD-1X5; 1X05
MICROSD: PINHD-1X6; 1X06
RBCLK: R-US_0207/10; 0207/10
RBDATA: R-US_0207/10; 0207/10
RCCLK: R-US_0207/10; 0207/10
RCDATA: R-US_0207/10; 0207/10
RTC_DATA: PINHD-1X5; 1X05
RTC_PENJEPIT: PINHD-1X7; 1X07
RVDIV1, RVDIV2: R-US_0207/10; 0207/10
SELECTOR_SUPPLY_3V3, SELECTOR_SUPPLY_5V: PINHD-1X3; 1X03
SELECTOR_TX_RX: PINHD-2X2; 2X02
TCLK: BC547; TO92
TDATA: BC547; TO92
U$1: ESP32DEVKITV1; ESP32-DEVKITV1

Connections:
1V5: CALIPER.1, RVDIV1.1, RVDIV2.2
3V3: RCCLK.2, RCDATA.2, RVDIV1.2, SELECTOR_SUPPLY_3V3.3
3V3_ESP: SELECTOR_SUPPLY_3V3.2, U$1.1 (3V3)
3V3_SUPPLY: AMS1117_SUPPLY.2 (OUT), AMS1117_SUPPLY.4 (OUT), C3V3.1, LED3V3.A, SELECTOR_SUPPLY_3V3.1
5V: ARDUINO_NANO1.12 (5V), ARDUINO_NANO1.15 (VIN), LCD_CRYSTAL.2, MAX6675_TE1.2, MAX6675_TE2.2, MICROSD.2, RTC_DATA.4, SELECTOR_SUPPLY_5V.3
5V_ESP: SELECTOR_SUPPLY_5V.2, U$1.30 (VIN)
5V_SUPPLY: 7805_SUPPLY.3 (VO), AMS1117_SUPPLY.3 (IN), C5V.1, SELECTOR_SUPPLY_5V.1
CHIP_SELECT_USD: ARDUINO_NANO1.28 (D10/OC1B/!SS), MICROSD.6, U$1.4 (IO2)
CLK_CALIPER: RCCLK.1, TCLK.3 (C), U$1.20 (IO35)
CLK_IN: CALIPER.2, RBCLK.2
CS_TE1: MAX6675_TE1.4, U$1.22 (IO33)
DATA_CALIPER: RCDATA.1, TDATA.3 (C), U$1.19 (IO34)
DATA_IN: CALIPER.3, RBDATA.2
MISO_USD: ARDUINO_NANO1.30 (D12/MISO), MICROSD.3, U$1.10 (IO19)
MOSI_USD: ARDUINO_NANO1.29 (D11/MOSI), MICROSD.4, U$1.15 (IO23)
unnamed: 12VIN.1, 7805_SUPPLY.1 (VI), C12V.1
unnamed: RBCLK.1, TCLK.2 (B)
unnamed: CLED3V3.1, LED3V3.K (C)
unnamed: RBDATA.1, TDATA.2 (B)
RX_ESP: SELECTOR_TX_RX.3, U$1.12 (IO3)
RX_NANO: ARDUINO_NANO1.17 (D0/RX), SELECTOR_TX_RX.4
SCK_TE1: MAX6675_TE1.3, U$1.21 (IO32)
SCK_USD: ARDUINO_NANO1.1 (SCK/D13), MICROSD.5, U$1.9 (IO18)
SCL: LCD_CRYSTAL.4, RTC_DATA.2, U$1.14 (IO22)
SDA: LCD_CRYSTAL.3, RTC_DATA.3, U$1.11 (IO21)
SO_TE1: MAX6675_TE1.5, U$1.23 (IO25)
SO_TE2: MAX6675_TE2.5, U$1.26 (IO14)
TX_ESP: SELECTOR_TX_RX.2, U$1.13 (IO1)
TX_NANO: ARDUINO_NANO1.16 (D1/TX), SELECTOR_TX_RX.1

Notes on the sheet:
CALIPER

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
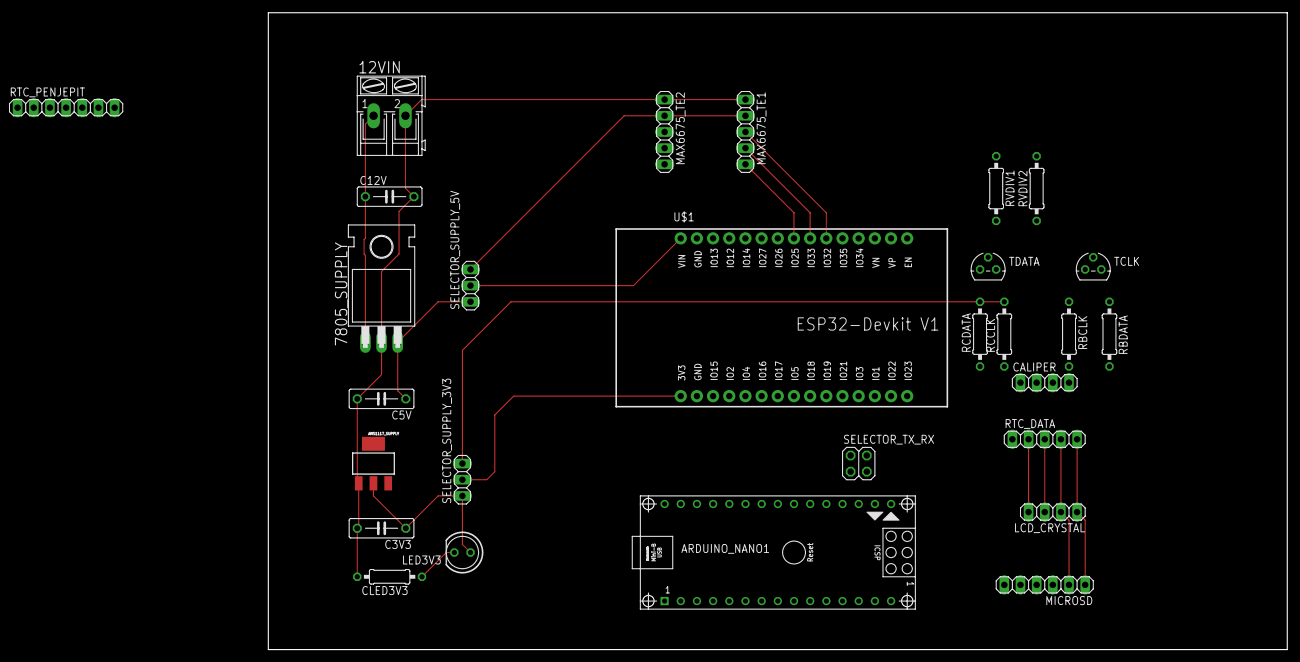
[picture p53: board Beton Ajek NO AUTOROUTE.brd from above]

Board: 2 copper layers, 160.0 x 100.0 mm, 28 parts (0 on the bottom side), 32 nets.

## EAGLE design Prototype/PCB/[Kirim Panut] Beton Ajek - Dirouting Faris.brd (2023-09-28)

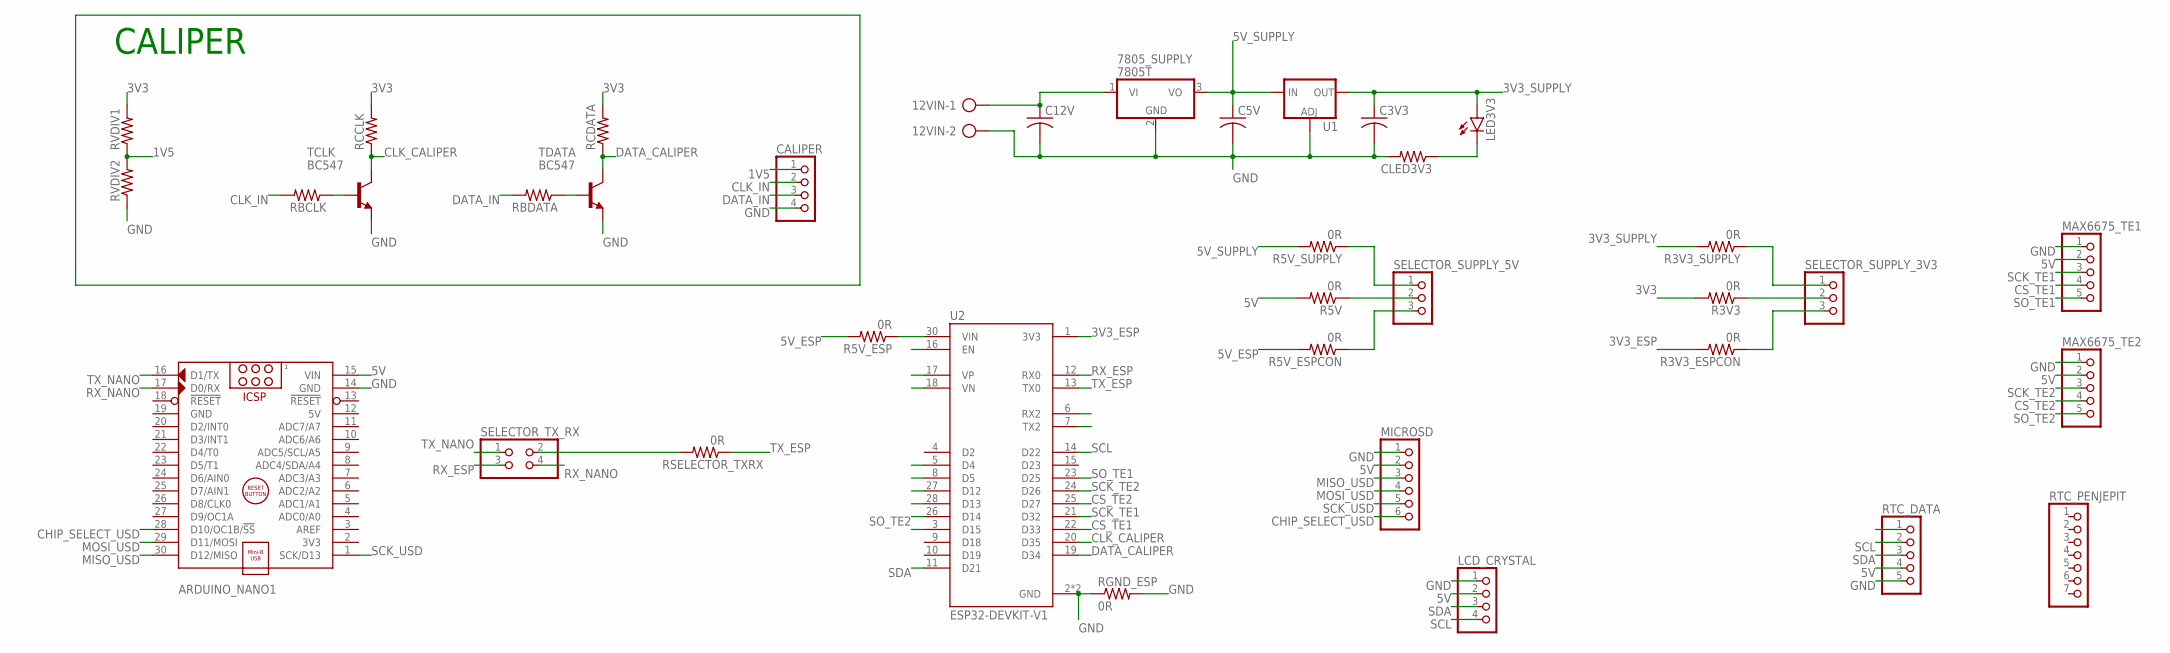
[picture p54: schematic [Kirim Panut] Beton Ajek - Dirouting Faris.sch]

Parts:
12VIN: AK300/2
7805_SUPPLY: 7805T; TO220H
ARDUINO_NANO1: ARDUINO_NANO
C3V3, C5V, C12V: C-US075-032X103; C075-032X103
CALIPER: PINHD-1X4; 1X04
CLED3V3: R-US_0207/10; 0207/10
LCD_CRYSTAL: PINHD-1X4; 1X04
LED3V3: LED5MM
MAX6675_TE1, MAX6675_TE2: PINHD-1X5; 1X05
MICROSD: PINHD-1X6; 1X06
R3V3, R3V3_ESPCON, R3V3_SUPPLY, R5V, R5V_ESP, R5V_ESPCON, R5V_SUPPLY: 0R; 0207/10
RBCLK: R-US_0207/10; 0207/10
RBDATA: R-US_0207/10; 0207/10
RCCLK: R-US_0207/10; 0207/10
RCDATA: R-US_0207/10; 0207/10
RGND_ESP: 0R; 0207/15
RSELECTOR_TXRX: 0R; 0207/10
RTC_DATA: PINHD-1X5; 1X05
RTC_PENJEPIT: PINHD-1X7; 1X07
RVDIV1, RVDIV2: R-US_0207/10; 0207/10
SELECTOR_SUPPLY_3V3, SELECTOR_SUPPLY_5V: PINHD-1X3; 1X03
SELECTOR_TX_RX: PINHD-2X2; 2X02
TCLK: BC547; TO92
TDATA: BC547; TO92
U1: V_REG_LM1117SOT223; SOT223
U2: ESP32-DEVKIT-V1; MODULE_ESP32_DEVKIT_V1

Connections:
1V5: CALIPER.1, RVDIV1.1, RVDIV2.2
3V3: R3V3.2, RCCLK.2, RCDATA.2, RVDIV1.2
3V3_ESP: R3V3_ESPCON.2, U2.1 (3V3)
3V3_SUPPLY: C3V3.1, LED3V3.A, R3V3_SUPPLY.2, U1.2 (OUT), U1.4 (OUT)
5V: ARDUINO_NANO1.12 (5V), ARDUINO_NANO1.15 (VIN), LCD_CRYSTAL.2, MAX6675_TE1.2, MAX6675_TE2.2, MICROSD.2, R5V.2, RTC_DATA.4
5V_ESP: R5V_ESP.2, R5V_ESPCON.2
5V_SUPPLY: 7805_SUPPLY.3 (VO), C5V.1, R5V_SUPPLY.2, U1.3 (IN)
CHIP_SELECT_USD: ARDUINO_NANO1.28 (D10/OC1B/!SS), MICROSD.6
CLK_CALIPER: RCCLK.1, TCLK.3 (C), U2.20 (D35)
CLK_IN: CALIPER.2, RBCLK.2
CS_TE1: MAX6675_TE1.4, U2.22 (D33)
CS_TE2: MAX6675_TE2.4, U2.25 (D27)
DATA_CALIPER: RCDATA.1, TDATA.3 (C), U2.19 (D34)
DATA_IN: CALIPER.3, RBDATA.2
GND: 12VIN.2, 7805_SUPPLY.2 (GND), ARDUINO_NANO1.14 (GND), ARDUINO_NANO1.19 (GND), C3V3.2, C5V.2, C12V.2, CALIPER.4, CLED3V3.2, LCD_CRYSTAL.1, MAX6675_TE1.1, MAX6675_TE2.1, MICROSD.1, RGND_ESP.1, RGND_ESP.2, RTC_DATA.5, RVDIV2.1, TCLK.1 (E), TDATA.1 (E), U1.1 (ADJ), U2.2 (GND), U2.29 (GND)
MISO_USD: ARDUINO_NANO1.30 (D12/MISO), MICROSD.3
MOSI_USD: ARDUINO_NANO1.29 (D11/MOSI), MICROSD.4
unnamed: 12VIN.1, 7805_SUPPLY.1 (VI), C12V.1
unnamed: RBCLK.1, TCLK.2 (B)
unnamed: RSELECTOR_TXRX.2, SELECTOR_TX_RX.2
unnamed: R5V_ESP.1, U2.30 (VIN)
unnamed: R5V.1, SELECTOR_SUPPLY_5V.2
unnamed: R5V_SUPPLY.1, SELECTOR_SUPPLY_5V.1
unnamed: CLED3V3.1, LED3V3.K (C)
unnamed: R5V_ESPCON.1, SELECTOR_SUPPLY_5V.3
unnamed: R3V3.1, SELECTOR_SUPPLY_3V3.2
unnamed: R3V3_SUPPLY.1, SELECTOR_SUPPLY_3V3.1
unnamed: RBDATA.1, TDATA.2 (B)
unnamed: R3V3_ESPCON.1, SELECTOR_SUPPLY_3V3.3
RX_ESP: SELECTOR_TX_RX.3, U2.12 (RX0)
RX_NANO: ARDUINO_NANO1.17 (D0/RX), SELECTOR_TX_RX.4
SCK_TE1: MAX6675_TE1.3, U2.21 (D32)
SCK_TE2: MAX6675_TE2.3, U2.24 (D26)
SCK_USD: ARDUINO_NANO1.1 (SCK/D13), MICROSD.5
SCL: LCD_CRYSTAL.4, RTC_DATA.2, U2.14 (D22)
SDA: LCD_CRYSTAL.3, RTC_DATA.3, U2.11 (D21)
SO_TE1: MAX6675_TE1.5, U2.23 (D25)
SO_TE2: MAX6675_TE2.5, U2.26 (D14)
TX_ESP: RSELECTOR_TXRX.1, U2.13 (TX0)
TX_NANO: ARDUINO_NANO1.16 (D1/TX), SELECTOR_TX_RX.1

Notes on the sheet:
CALIPER

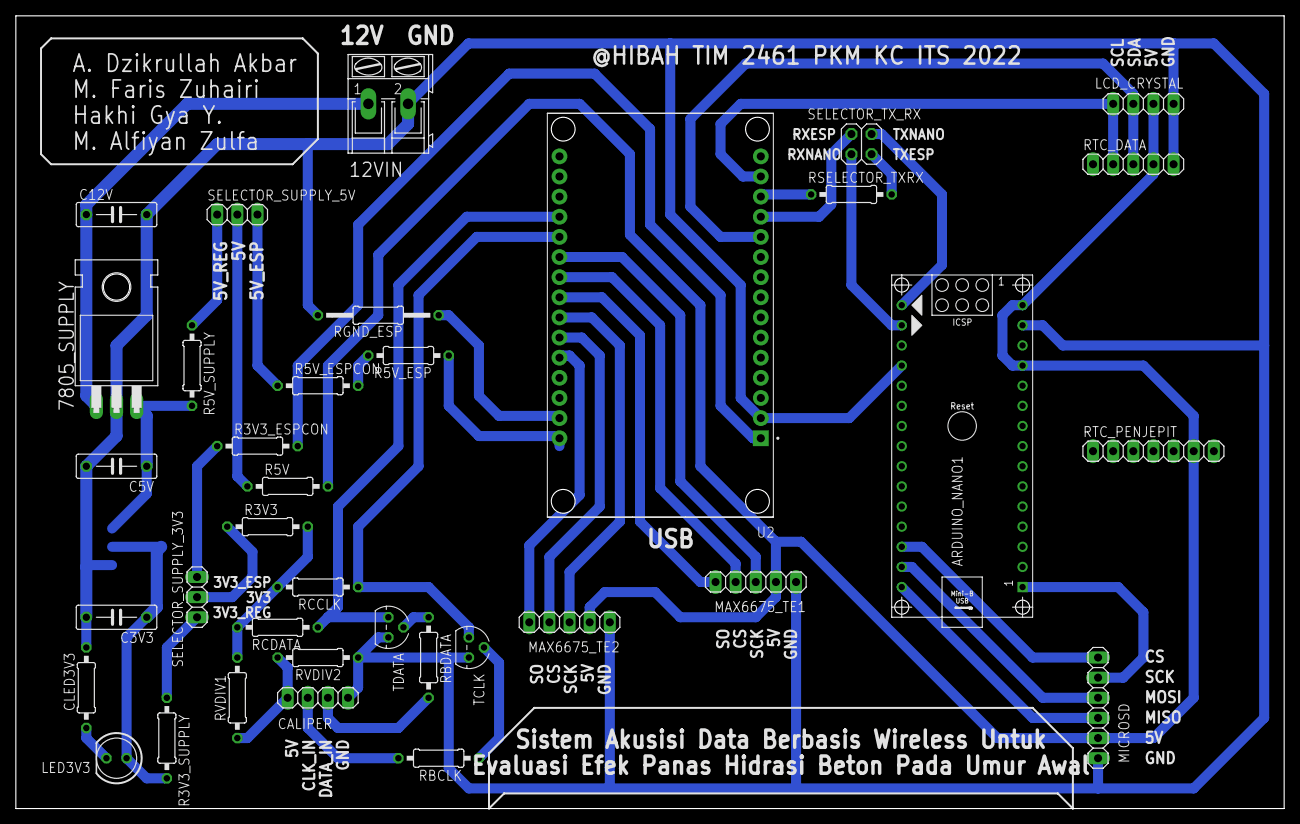
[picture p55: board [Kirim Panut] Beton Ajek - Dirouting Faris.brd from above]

Board: 2 copper layers, 160.0 x 100.0 mm, 37 parts (1 on the bottom side), 40 nets.

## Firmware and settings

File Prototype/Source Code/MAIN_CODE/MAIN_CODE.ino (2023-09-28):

#include <ETH.h>
#include <WiFi.h>
#include <WiFiAP.h>
#include <WiFiClient.h>
#include <WiFiGeneric.h>
#include <WiFiMulti.h>
#include <WiFiScan.h>
#include <WiFiServer.h>
#include <WiFiSTA.h>
#include <WiFiType.h>
#include <WiFiUdp.h>

#include <Wire.h>
#include <AverageThermocouple.h>
#include <MAX6675_Thermocouple.h>
#include <SmoothThermocouple.h>
#include <Thermocouple.h>
#include <SPI.h>
#include <SD.h>

#include <LiquidCrystal_I2C.h>
//---INISIALISASI THERMOCOUPLE 1-----------
int pinSO1 = 32;
int pinCS1 = 4;
int pinSCK1 = 33;
float suhuRumus1=0.0;
#define SMOOTHING_FACTOR 5
Thermocouple* thermocouple1 = NULL;
//---INISIALISASI THERMOCOUPLE 2-----------
int pinSO2 = 14;
int pinCS2 = 27;
int pinSCK2 = 26;
float suhuRumus2=0.0;
Thermocouple* thermocouple2 = NULL;
//---INISIALISASI DIGITAL CALIPER--------
int i;
int sign;
long value;
float result=0;
int clockpin = 15;  
int datapin = 34;
unsigned long tempmicros;

//---INISIALISASI RTC---------------------
#define DS3231_I2C_ADDRESS 0x68

byte decToBcd(byte val){
  return( (val/10*16) + (val%10) );
}
byte bcdToDec(byte val){
  return( (val/16*10) + (val%16) );
}
int jedaMenit = 1; //jeda waktu antar pengukuran dlm menit
int jedaDetik = 10; //jeda waktu antar pengukuran dlm menit
//---INISIALISASI LCD I2C------------------
LiquidCrystal_I2C lcd(0x27, 16, 2);
unsigned long millis_tampilan;
byte symKetinggian[] = {
  B00100,
  B01010,
  B10101,
  B00100,
  B00100,
  B10101,
  B01010,
  B00100
};

byte symSuhu[] = {
  B01101,
  B01100,
  B01110,
  B01100,
  B01100,
  B10010,
  B10010,
  B01100
};

//---INISIALISASI WIFI ESP32 & HTTP GET----
const char* host = "hidrasibeton.ewatery.tech";
const int httpPort = 80;
const char* ssid     = "apoci";
const char* password = "apoci123";
long last_millis_wifi;
String wifi="OFF";
bool mode;
WiFiClient client;

//---DATALOG MICRO SD----------------------
const int CS_uSD = 2; //chip select
File myFile;

void setup() {
  Serial.begin(9600);
  Wire.begin();
  //lcd.init();
  lcd.begin();
  lcd.createChar(0, symKetinggian);
  lcd.createChar(1, symSuhu);
  
  //---CONNECTING TO WIFI HOTSPOT---------
  WiFi.mode(WIFI_STA);
  WiFi.begin(ssid, password);
  lcd.clear();
  lcd.setCursor (0,0);
  lcd.print("Connecting.....");
  Serial.print("Connecting....");
  lcd.setCursor (0,1);
  lcd.print(ssid);
  //tunggu connect wifi
  while (WiFi.status() != WL_CONNECTED) {
    delay(500);
    Serial.print(".");
  }
  lcd.clear();
  lcd.setCursor (0,0);
  lcd.print("Connecting.....");
  lcd.setCursor (0,1);
  lcd.print("SUCCESS!");
  Serial.println("");
  Serial.println("WiFi connected");
  Serial.println("IP address: ");
  Serial.println(WiFi.localIP());
  lcd.clear();
  tampilPengukuran();
  
  //---SMOOTHING FOR THERMOCOUPLE1---------
  Thermocouple* originThermocouple1 = new MAX6675_Thermocouple(pinSCK1, pinCS1, pinSO1);
  thermocouple1 = new SmoothThermocouple(originThermocouple1, SMOOTHING_FACTOR);
  //---SMOOTHING FOR THERMOCOUPLE2---------
  Thermocouple* originThermocouple2 = new MAX6675_Thermocouple(pinSCK2, pinCS2, pinSO2);
  thermocouple2 = new SmoothThermocouple(originThermocouple2, SMOOTHING_FACTOR);
  
  //---DS3231------ FORMAT SETTING: seconds, minutes, hours, day, date, month, year
  //setDS3231time(50,02,15,06,15,07,22); //UNCOMMENT INI UNTUK PERTAMA KALI SETTING TIME DS1307

/*
  //---SD CARD-----
  SD.begin();
  if (SD.begin())
  {
    Serial.println("SD card is present & ready");
  } 
  else
  {
    Serial.println("SD card missing or failure");
    return;
    //while(1); //halt program
  }
  //SECTION clear out old data file
  if (SD.exists("data_pengukuran.txt")) 
  {
    Serial.println("Removing data_pengukuran.txt");
    SD.remove("data_pengukuran.txt");
    Serial.println("Done removing");
  }
  //SECTION write data
  //write csv headers to file:
   
   myFile = SD.open("data_pengukuran.txt", FILE_WRITE);  
   if (myFile) // it opened OK
    {
    Serial.println("Writing headers to data_pengukuran.txt");
    myFile.println("Year, Month, Day, Hour, Minute, Second, Suhu1, Suhu2, Panjang Caliper");
    myFile.close(); 
    Serial.println("Headers written");
    }
  else 
    Serial.println("Error opening data_pengukuran.txt");
    */
  pinMode(clockpin, INPUT);
  pinMode(datapin, INPUT);
  pinMode(CS_uSD, OUTPUT);
  Serial.println("Mulai baca caliper dan thermocouple");
}

void loop () {
  byte second, minute, hour, dayOfWeek, dayOfMonth, month, year;
  readDS3231time(&second, &minute, &hour, &dayOfWeek, &dayOfMonth, &month,
  &year);
  //jika jeda untuk detik, condition: detik%jedaDetik==0 saja
  //jika jeda untuk menit, condition: detik%60==0 && menit%jedaMenit==0
  //jika jeda untuk jam, condition: detik%60==0 && menit%60==0 && jam%jedaJam==0
  
  
  if (second%jedaDetik == 0){
    Serial.print(hour);
    Serial.print(minute);
    Serial.print(second);
    //------BACA THERMOCOUPLE 1&2-----
    const double suhu1 = thermocouple1->readCelsius(); 
    const double suhu2 = thermocouple2->readCelsius(); 
    //------BACA CALIPER SAJA-----
    while (digitalRead(clockpin)==HIGH) {} //if clock is LOW wait until it turns to HIGH
    tempmicros=micros();
    while (digitalRead(clockpin)==LOW) {} //wait for the end of the HIGH pulse
    if ((micros()-tempmicros)>500) { //if the HIGH pulse was longer than 500 micros we are at the start of a new bit sequence
      decode(); //decode the bit sequence
    }
    Serial.print("Pembacaan: caliper = ");  
    Serial.print(result,2); //print result with 2 decimals
    Serial.print("mm ; TE1 =  ");
    suhuRumus1 = 1*suhu1 - 1.35; //linearisasi thermocouple
    Serial.print(suhuRumus1);
    Serial.print(" C ; TE2 =  ");  
    suhuRumus2 = 1*suhu2 - 1.35; //linearisasi thermocouple
    Serial.print(suhuRumus2);
    /*
    myFile = SD.open("data_pengukuran.txt", FILE_WRITE);     
        // if the file opened okay, write to it:
        if (myFile) 
        {
          Serial.println("Writing to txt");
          myFile.println(year);
          myFile.println(month); 
          myFile.println(dayOfMonth); 
          myFile.println(hour); 
          myFile.println(minute); 
          myFile.println(second); 
          myFile.println(suhuRumus1); 
          myFile.println(suhuRumus2); 
          myFile.println(result); 
          myFile.close();
        } 
        else 
        {
          Serial.println("error opening txt");
        }
      */
    //writeToMicroSD(year,month,dayOfMonth,hour,minute,second,suhuRumus1,suhuRumus2,result);
    String protokol = "/tes.php?timeSampling="+
        String(year)+String(month)+String(dayOfMonth)+String(hour)+String(minute)+String(second)+
        "&suhu="+String(suhuRumus1)+
        "&panjang="+String(result);
    Serial.println( "Send Data To Server:"+send(protokol));
  }
  if (millis()-millis_tampilan<5000){
      tampilPengukuran();}
  else  if (millis()-millis_tampilan<8000){
      splashScreen();}
  else{
      millis_tampilan=millis();
    }
}

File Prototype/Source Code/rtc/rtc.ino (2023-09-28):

// Written by John Boxall from http://tronixstuff.com

#include "Wire.h"
#define DS3231_I2C_ADDRESS 0x68
// Convert normal decimal numbers to binary coded decimal
byte decToBcd(byte val){
  return( (val/10*16) + (val%10) );
}
// Convert binary coded decimal to normal decimal numbers
byte bcdToDec(byte val){
  return( (val/16*10) + (val%16) );
}
void setup(){
  Wire.begin();
  Serial.begin(9600);
  // set the initial time here:
  // DS3231 seconds, minutes, hours, day, date, month, year
  //setDS3231time(00,00,18,06,15,07,22); //UNCOMMENT INI UNTUK PERTAMA KALI SETTING TIME DS1307
}
void setDS3231time(byte second, byte minute, byte hour, byte dayOfWeek, byte
dayOfMonth, byte month, byte year){
  // sets time and date data to DS3231
  Wire.beginTransmission(DS3231_I2C_ADDRESS);
  Wire.write(0); // set next input to start at the seconds register
  Wire.write(decToBcd(second)); // set seconds
  Wire.write(decToBcd(minute)); // set minutes
  Wire.write(decToBcd(hour)); // set hours
  Wire.write(decToBcd(dayOfWeek)); // set day of week (1=Sunday, 7=Saturday)
  Wire.write(decToBcd(dayOfMonth)); // set date (1 to 31)
  Wire.write(decToBcd(month)); // set month
  Wire.write(decToBcd(year)); // set year (0 to 99)
  Wire.endTransmission();
}
void readDS3231time(byte *second,
byte *minute,
byte *hour,
byte *dayOfWeek,
byte *dayOfMonth,
byte *month,
byte *year){
  Wire.beginTransmission(DS3231_I2C_ADDRESS);
  Wire.write(0); // set DS3231 register pointer to 00h
  Wire.endTransmission();
  Wire.requestFrom(DS3231_I2C_ADDRESS, 7);
  // request seven bytes of data from DS3231 starting from register 00h
  *second = bcdToDec(Wire.read() & 0x7f);
  *minute = bcdToDec(Wire.read());
  *hour = bcdToDec(Wire.read() & 0x3f);
  *dayOfWeek = bcdToDec(Wire.read());
  *dayOfMonth = bcdToDec(Wire.read());
  *month = bcdToDec(Wire.read());
  *year = bcdToDec(Wire.read());
}
void displayTime(){
  byte second, minute, hour, dayOfWeek, dayOfMonth, month, year;
  // retrieve data from DS3231
  readDS3231time(&second, &minute, &hour, &dayOfWeek, &dayOfMonth, &month,
  &year);
  // send it to the serial monitor
  Serial.print(hour, DEC);
  // convert the byte variable to a decimal number when displayed
  Serial.print(":");
  if (minute<10){
    Serial.print("0");
  }
  Serial.print(minute, DEC);
  Serial.print(":");
  if (second<10){
    Serial.print("0");
  }
  Serial.print(second, DEC);
  Serial.print(" ");
  Serial.print(dayOfMonth, DEC);
  Serial.print("/");
  Serial.print(month, DEC);
  Serial.print("/");
  Serial.print(year, DEC);
  Serial.print(" Day of week: ");
  switch(dayOfWeek){
  case 1:
    Serial.println("Sunday");
    break;
  case 2:
    Serial.println("Monday");
    break;
  case 3:
    Serial.println("Tuesday");
    break;
  case 4:
    Serial.println("Wednesday");
    break;
  case 5:
    Serial.println("Thursday");
    break;
  case 6:
    Serial.println("Friday");
    break;
  case 7:
    Serial.println("Saturday");
    break;
  }
}
void loop(){
  displayTime(); // display the real-time clock data on the Serial Monitor,
  delay(1000); // every second
}

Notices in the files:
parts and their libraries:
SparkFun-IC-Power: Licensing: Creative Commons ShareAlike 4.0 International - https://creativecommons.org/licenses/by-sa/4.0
